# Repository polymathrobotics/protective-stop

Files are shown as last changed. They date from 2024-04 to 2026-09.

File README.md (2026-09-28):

# Protective Stop

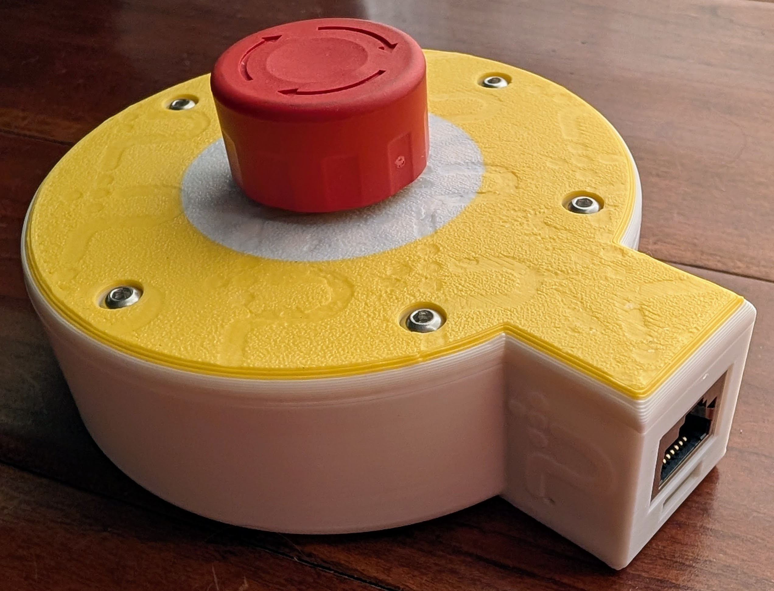
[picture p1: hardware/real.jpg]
Assembled Protective Stop remote with a red stop button, printed enclosure, and Ethernet side pod


<a href="https://certification.oshwa.org/us002846.html">
  OSHWA open source hardware certification mark, UID US002846
</a>

Protective Stop is an open hardware remote for robots and automation. A
PoE- or USB-powered ESP32-S3 watches a physical stop switch and reports its
state to machine-side pstop logic. A STOP message, a wiring fault, or a lost
heartbeat causes the machine process to request STOP.

Each machine sets its own heartbeat window; the remote normally transmits
halfway through it. The network update rate is therefore configured, not fixed.

> This is a protective stop, not an emergency stop. It does not replace a
> required emergency-stop function, including hardwired power removal where
> applicable. OSHWA certification covers open source hardware; it is not
> functional-safety certification.

## How it works

The switch has two normally closed contacts, each wired to a separate GPIO loop
and read by one CPU core. Each core builds the full pstop message independently;
transmission occurs only when both encoded messages match exactly.

Pressing the switch opens both loops and sends STOP. A broken wire or other
fault in one loop makes the cores disagree, while a stalled task or loss of all
network paths prevents transmission. In either case, the machine requests STOP
when its silence timeout expires.

The wire protocol and machine-side state logic come from vendored
[`pstop_c`](pstop_c/), which remains unchanged and follows a separate
certification track. The surrounding firmware handles sensing, networking, and
recovery.

```mermaid
flowchart LR
    subgraph REMOTE["REMOTE - ESP32-S3"]
        SW["DPST NC stop switch"]
        C0["core 0: read loop A and encode"]
        C1["core 1: read loop B and encode"]
        CMP{"byte-for-byte comparator"}
        SW --> C0 --> CMP
        SW --> C1 --> CMP
    end

    NET(["Tailscale path<br/>WireGuard direct or DERP relay"])

    subgraph MACHINE["MACHINE - robot host"]
        APP["machine wrapper"]
        LIB["pstop_c state machine"]
        STOP["STOP request"]
        APP --> LIB --> STOP
    end

    CMP -->|"machine-controlled heartbeat"| NET --> APP
```

Peers addressed directly over LAN or USB-NCM bypass Tailscale and are not
WireGuard-encrypted. Tailscale peers use WireGuard, with DERP relay fallback
when a direct path is unavailable. Their sockets are pinned to the tunnel, so
losing the VPN causes silence instead of a plaintext downgrade. Ethernet is
preferred, with USB-NCM and WiFi available as fallbacks.

## What's included

| Path | Contents |
|---|---|
| [`hardware/`](hardware/) | Editable FreeCAD enclosure, printable files, BOM, wiring, and photographed assembly guide |
| [`firmware/`](firmware/) | ESP-IDF remote firmware and the dual-core sensing/comparison logic |
| [`host/`](host/) | Plain-C machine process and its documented configuration |
| [`ros2/`](ros2/) | ROS 2 machine node and messages |
| [`components/`](components/) | Embedded networking, USB tether, and `pstop_c` integration |
| [`docs/`](docs/) | API, recovery, testing, networking, and safety-case documentation |
| [`tools/`](tools/) and [`test/`](test/) | Protocol, chaos, soak, flashing, and static-analysis tools (see [`tools/README.md`](tools/README.md) for the uv setup) |

Tailscale support uses
[`microlink`](https://github.com/CamM2325/microlink), an embedded client from
Malone Technologies.

### ROS Support
The protective stop machine node is compatible with the following ros2 Distros:
1. Humble (until May 2027)
2. Jazzy (until May 2029)
3. Lyrical (not yet supported, but planned to be supported as soon as possible!)

## Build and run

**[`docs/QUICKSTART.md`](docs/QUICKSTART.md)** walks a fresh laptop through
the whole thing: Tailscale account and key, USB tether, build and flash,
the ROS 2 machine node, pairing, and a bench test through STOP and ARM.
The short version (ESP-IDF 5.5 required):

```sh
cp firmware/sdkconfig.credentials.example firmware/sdkconfig.credentials
$EDITOR firmware/sdkconfig.credentials            # Tailscale auth key + admin password
cd firmware && . /path/to/esp-idf-v5.5/export.sh
idf.py -DPSTOP_PROFILE=dev build && idf.py -p /dev/ttyACM0 flash   # dev profile: bench only

cd ../ros2 && colcon build --packages-up-to protective_stop_machine
ros2 run protective_stop_machine machine_bridge_node
curl -X POST "http://<remote>/api/pstop_peer?ip=<laptop-tailscale-ip>&port=8890"
```

A plain-C machine process (`cd host && make && ./machine_app_runner`) is the
non-ROS alternative. Later firmware updates go over the authenticated admin
API (`POST /admin/api/ota`). Hardware assembly starts with
[`hardware/README.md`](hardware/README.md) and the photographed
[`hardware/ASSEMBLY.md`](hardware/ASSEMBLY.md).

## Timing and arming

The network update rate and stop-on-silence time are machine-controlled:

```text
remote send interval = clamp(heartbeat_ms / 2, 100 ms, 1000 ms)
stop-on-silence time = heartbeat_ms * max_missed_heartbeats
```

The default configuration uses a 400 ms heartbeat window and five missed
windows, giving a send interval of about 200 ms and a stop-on-silence threshold
of about 2 seconds. Integrators should choose values within the validated limits
so the timeout fits their process safety time and network conditions.

The machine starts stopped. To arm it, press and hold the switch for at least
`min_stop_ms` (500 ms by default), then release it. Whether a remote may re-arm
is the **remote's own** declared role: a new remote announces `stop_only` (it can
stop a machine but never arm it) until promoted to `operator` through its
authenticated `/api/role`. The change applies live — an armed machine keeps
running when its operator demotes itself, but refuses to re-arm until a remote
announcing `operator` performs the gesture.

Machines optionally restrict **who may bond at all** with a global allowlist
and/or denylist (empty by default = everyone). A refused remote is told so
(`UNBOND`) and stops retrying until an operator asks it to rebond.

One remote can maintain independent sessions with up to four machines. Each
machine controls its own heartbeat window, timeout and admission policy.

## Testing

The repository includes host-side protocol tests, fault-injection and chaos
ladders, transport soaks, ROS 2 tests, firmware builds, and a MISRA C:2012
pre-check. Start with [`docs/TESTING.md`](docs/TESTING.md); long-run transport
testing is documented in
[`docs/CONNECTIVITY_SOAK.md`](docs/CONNECTIVITY_SOAK.md).

```sh
make -C host test
./tools/misra_check.sh
pre-commit run --all-files
```

## Certification and licensing

The Protective Stop v1.2 hardware design was OSHWA-certified as open source
hardware on August 27, 2026:

- OSHWA UID: **[US002846](https://certification.oshwa.org/us002846.html)**
- Hardware: CERN-OHL-P-2.0
- Software and firmware: Apache-2.0
- Documentation: CC-BY-4.0 unless a file states otherwise

<a href="https://oshwa.github.io/certification-mark-generator/facts">
  Open source license facts: hardware CERN-OHL-P-2.0, software Apache-2.0, documentation CC-BY-4.0
</a>

The source package, licensing map, and mark guidance are summarized in
[`docs/OSHWA_COMPLIANCE.md`](docs/OSHWA_COMPLIANCE.md). Full license texts are
in [`LICENSE`](LICENSE) and [`LICENSES/`](LICENSES/).

The design target for the on-demand stop function is SIL 3 under IEC 61508 and
PL e under ISO 13849. These are engineering targets, not current
functional-safety certifications. The safety case and remaining evidence gaps
are tracked in [`docs/safety/`](docs/safety/) and
[`docs/safety/OPEN_ITEMS.md`](docs/safety/OPEN_ITEMS.md).

## Contributing

See [`CONTRIBUTING.md`](CONTRIBUTING.md) for development requirements. Report
security issues through [`SECURITY.md`](SECURITY.md).

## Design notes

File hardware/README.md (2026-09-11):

# Hardware

<a href="https://certification.oshwa.org/us002846.html">
  OSHWA open source hardware certification mark, UID US002846
</a>

<p>
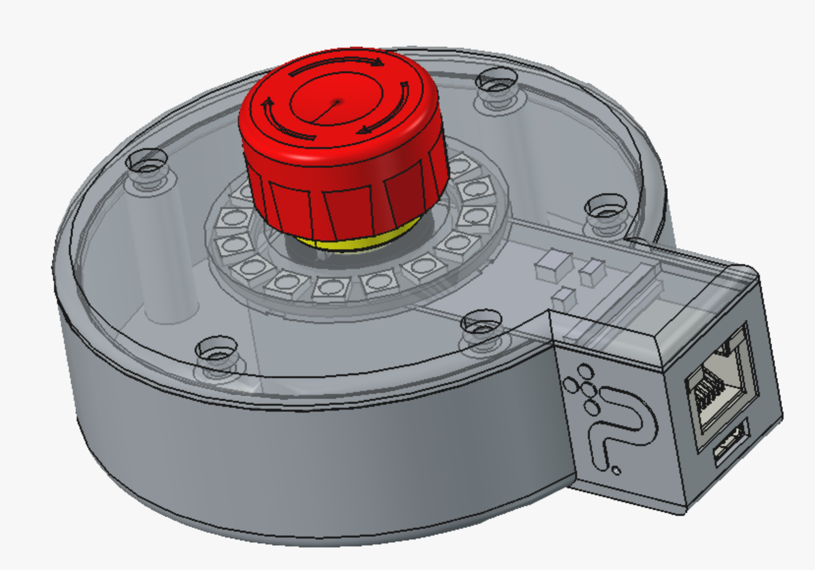
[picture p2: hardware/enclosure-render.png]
CAD render: E-stop button over the 16-LED ring, ports in the side pod
  
  Printed unit: yellow lid, red E-stop, RJ45 in the side pod
</p>

The physical design of the Protective Stop remote lives here: enclosure CAD
(FreeCAD source `casing.FCStd` plus printable exports), the Waveshare
ESP32-S3-ETH carrier board (`ESP32-S3-ETH-Schematic.pdf`, photos, STEP), and
the LED and connector models. CAD render on the left, a printed unit on the
right: the E-stop button sits in the center, the LED ring lights the
diffuser around its base, and the Ethernet and USB-C ports live in the
side pod.

Build steps with photos: [ASSEMBLY.md](ASSEMBLY.md).

## Pinout and wiring

Two external parts connect to the board: the 16-LED WS2812 ring and a DPST
normally-closed E-stop button. Each pole of the button sits in its own
loopback: the firmware drives one GPIO and reads the echo on another, once
per pole, so a broken wire reads the same as a pressed button (STOP). The
pin assignments are fixed in the firmware; the wire colors are only an
assembly convention to keep units consistent and easy to check. Pin names
match the board silkscreen (IO17, IO39, and so on).

| Board pin | Goes to | Wire color |
|---|---|---|
| VBUS | Ring 5V | red |
| GND | Ring GND | black |
| IO17 | Ring DIN (data) | green |
| IO39 | Button terminal 11 (pole A) | white |
| IO40 | Button terminal 12 (pole A) | white |
| IO41 | Button terminal 21 (pole B) | yellow |
| IO42 | Button terminal 22 (pole B) | yellow |

```mermaid
flowchart LR
    subgraph BOARD["ESP32-S3-ETH"]
        direction TB
        P5V["VBUS"]
        GND["GND"]
        G17["IO17"]
        G39["IO39 drive"]
        G40["IO40 sense"]
        G41["IO41 drive"]
        G42["IO42 sense"]
    end

    subgraph RING["WS2812 ring, 16 LEDs"]
        direction TB
        RV["5V"]
        RG["GND"]
        RD["DIN"]
    end

    subgraph SW["DPST E-stop button, NC"]
        direction TB
        P1A["terminal 11, pole A"]
        P1B["terminal 12, pole A"]
        P2A["terminal 21, pole B"]
        P2B["terminal 22, pole B"]
    end

    P5V --- |red| RV
    GND --- |black| RG
    G17 --- |green| RD
    G39 --- |white| P1A
    G40 --- |white| P1B
    G41 --- |yellow| P2A
    G42 --- |yellow| P2B

    linkStyle 0 stroke:#d33,stroke-width:2px
    linkStyle 1 stroke:#333,stroke-width:2px
    linkStyle 2 stroke:#2a2,stroke-width:2px
    linkStyle 3,4 stroke:#aaa,stroke-width:2px
    linkStyle 5,6 stroke:#cc2,stroke-width:2px
```

Notes:

- The button contacts have no polarity; within a pole, either terminal can
  go to the drive pin. Keep each color pair on one pole: 11/12 together
  (white), 21/22 together (yellow).
- The sense pins are pulled down internally, so an open loop reads 0 and
  the firmware treats it as STOP. Pressing the button opens both poles at
  once; a single open loop (one broken wire) makes the two cores disagree,
  which also stops the machine.
- The ring can be installed in any of its 16 rotations. Which pixel counts
  as LED 1 is a per-device setting, calibrated over the network after
  assembly (`POST /api/ring_offset`, see `../docs/API.md`).
- The board's onboard status LED (IO21) needs no wiring.

## Bill of materials

Everything except the printed parts is ordered online. Listings are
pinned where the exact part matters; the wire and lid hardware are
generic, so those stay as search links. All links open in a new window.

| Qty | Part | Notes | Order |
|---|---|---|---|
| 1 | Waveshare ESP32-S3-ETH | The W5500 Ethernet carrier board this design is built around. For PoE-powered units order the ESP32-S3-POE-ETH variant on the same page; it includes the PoE Module (B) that mounts on the board. | <a href="https://www.waveshare.com/esp32-s3-eth.htm" target="_blank" rel="noopener">Waveshare</a> |
| 1 | DIYmall WS2812B ring, 16 pixels | 5V addressable ring. | <a href="https://www.amazon.com/DIYmall-WS2812B-Integrated-Individually-Addressable/dp/B0B2D5QXG5" target="_blank" rel="noopener">Amazon</a> |
| 1 | NKK Switches FF0126BBCAEA01 E-stop button | Twist-release mushroom, two normally-closed contacts (DPST NC). Rated 100,000 operations (mechanical and electrical life, FF01 datasheet); the firmware counts presses against this in `GET /api/health` (`CONFIG_DCS_BUTTON_RATED_OPS`). The STEP model in this folder is this exact part. Substitutes must have 2NC: both loops need an NC pole, so a 1NO+1NC unit will not work; set the Kconfig rating to the substitute's datasheet value. | <a href="https://octopart.com/part/nkk-switches/FF0126BBCAEA01" target="_blank" rel="noopener">Octopart</a> |
| 1 set | Silicone hookup wire | Red, black, green, white, yellow, 24 to 26 AWG, per the wiring table above. | <a href="https://www.amazon.com/s?k=silicone+hookup+wire+kit+26awg" target="_blank" rel="noopener">search</a> |
| ~6 | M3 socket-head screws + brass heat-set inserts | Lid fasteners. Confirm length and count against the current print before buying in bulk. | <a href="https://www.amazon.com/s?k=m3+heat+set+insert+socket+head+kit" target="_blank" rel="noopener">search</a> |
| 4 | M1.6 heat-set threaded inserts, M1.6 x 5 x 2.5 mm | Anchor the ESP32-S3-ETH board to the base; 2.5 mm is the insert height/depth. | <a href="https://www.amazon.com/s?k=m1.6+heat+set+threaded+insert" target="_blank" rel="noopener">search</a> |
| 3 | 1 oz (28 g) adhesive steel weights | Optional. Ballast in the base floor pockets so the unit stays put on a table. Wheel-weight style, adhesive backed. | <a href="https://www.amazon.com/s?k=1oz+adhesive+wheel+weights+steel" target="_blank" rel="noopener">search</a> |
| 1 | Printed enclosure | `print.3mf` in this folder (base and lid; the diffuser is a white section of the lid print), or the pre-sliced `print.gcode.3mf` for an X1C. Not purchased; any common PLA/PETG works. | n/a |

## Component datasheets

The design contains no custom electronics; the active components are all
off the shelf, with freely accessible datasheets:

- <a href="https://files.waveshare.com/wiki/common/Esp32-s3_datasheet_en.pdf" target="_blank" rel="noopener">ESP32-S3 datasheet</a> (Espressif, via the Waveshare wiki)
- <a href="https://files.waveshare.com/wiki/common/W5500_ds_v110e.pdf" target="_blank" rel="noopener">W5500 Ethernet controller datasheet</a> (WIZnet, via the Waveshare wiki)
- <a href="https://files.waveshare.com/wiki/ESP32-S3-ETH/ESP32-S3-ETH-Schematic.pdf" target="_blank" rel="noopener">ESP32-S3-ETH carrier board schematic</a> (Waveshare)
- <a href="https://cdn-shop.adafruit.com/datasheets/WS2812B.pdf" target="_blank" rel="noopener">WS2812B datasheet</a> (WorldSemi, the ring's LEDs)
- <a href="https://www.nkkswitches.eu/pdf/estop_FF01.pdf" target="_blank" rel="noopener">FF01 series E-stop datasheet</a> (NKK Switches)

## Licensing

The design is CERN-OHL-P-2.0 and the documentation is CC-BY-4.0; the full
texts live in [`../LICENSES/`](../LICENSES/). The vendor reference files
stay the property of their manufacturers and are included only as
fit-check references, with their origins listed below.

| File(s) | License / origin |
|---|---|
| `casing.FCStd`, `base*.stl`, `lid*.stl`, `led.stl`, `print.3mf`, `print.gcode.3mf` | CERN-OHL-P-2.0 (original design) |
| `esp32-S3.step` | CERN-OHL-P-2.0 (original board fit model) |
| `LED.step` | CERN-OHL-P-2.0 (ring model commissioned by Polymath Robotics) |
| `README.md`, `ASSEMBLY.md`, `enclosure-render.png`, `real.jpg`, `assembly/*.jpg` | CC-BY-4.0 (original documentation) |
| `oshwa-certification-mark.svg` | Official OSHWA wide certification mark generated for UID `US002846`; use is governed by the [OSHWA certification agreement](https://certification.oshwa.org/license-agreement.html) |
| `oshw-license-facts.svg` | Generated with the [Open Source Licenses Facts generator](https://oshwa.github.io/certification-mark-generator/facts) for this project's certified license combination |
| `ESP32-S3-ETH-Schematic.pdf` | Waveshare, from the <a href="https://www.waveshare.com/wiki/ESP32-S3-ETH" target="_blank" rel="noopener">product wiki</a> (<a href="https://files.waveshare.com/wiki/ESP32-S3-ETH/ESP32-S3-ETH-Schematic.pdf" target="_blank" rel="noopener">direct PDF</a>) |
| `ESP32-S3-ETH-details-15.jpg` | Waveshare product photo, from the <a href="https://www.waveshare.com/esp32-s3-eth.htm" target="_blank" rel="noopener">product page</a> |
| `FF0126BBCAEA01.stp` | NKK Switches E-stop model, from the <a href="https://www.nkkswitches.com/distributor-landing-page/?part_no=FF0126BBCAEA01&vendor=digikey" target="_blank" rel="noopener">NKK part page</a>; series datasheet: <a href="https://www.nkkswitches.eu/pdf/estop_FF01.pdf" target="_blank" rel="noopener">FF01 (NKK)</a> |

## Design files

The editable source for the custom parts is `casing.FCStd`; the STL/3MF files
are its printable exports, and the STEP models are references used for fit.
Build steps live in [ASSEMBLY.md](ASSEMBLY.md).

OSHWA certification details and maintenance notes are in
[`../docs/OSHWA_COMPLIANCE.md`](../docs/OSHWA_COMPLIANCE.md).

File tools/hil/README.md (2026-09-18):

# pstop hardware-in-the-loop test suite

Drives a real pstop remote through its **actual E-stop loops and power
feed** using a 4-channel USB relay board (`tools/usb_relay4.py`), and
asserts the safety behavior at a **dedicated real machine instance**
(`host/machine_app_runner`) over the real transport. Nothing is mocked:
the loop GPIOs, the lockstep comparator, the wire protocol, and the
machine-side arming policy are all the shipping code paths.

## Rig wiring (as built, verified 2026-07-28)

Relay board: STM32 VCP (`0483:5740`), auto-detected. All three channels
use the relays' **NO contacts**, so the fully de-energized rig is the
fail-safe state: loops open ("button pressed"), DUT unpowered.
Bench-normal requires relays 1–3 energized — `rig.idle()` and every
fixture teardown put the rig there.

| Relay | NO contact in series with | De-energized means |
|---|---|---|
| 1 | E-stop loop A: GPIO39 → GPIO40 | loop A open ("press") |
| 2 | E-stop loop B: GPIO41 → GPIO42 | loop B open ("press") |
| 3 | DUT USB power feed (VBUS) | DUT power cut |
| 4 | spare | |

If a future rig wires NC contacts instead, flip `press_energizes` /
`power_cut_energizes` in `hil.toml` — the suite is polarity-agnostic.

The DUT is tethered on USB-NCM; `hil.toml` names the host interface
(`ncm_iface`) and the suite finds the chip's IP from the kernel
neighbor table, then talks to `state.json` + `/api/pstop_peers`. This
bench has TWO pstops attached (soak unit on `esp-pstop0`/10.42.0.x,
test unit on `usb0`/10.43.0.x) — the iface setting is what keeps the
suite pointed at the right one. The suite claims **peer slot 3** on the
chip for its own machine instance (port 8894, id 0x01020390) and clears
it on teardown; slot 0 belongs to whatever real bench machine exists.

## Running

```sh
cd tools/hil
./run.sh                    # everything (incl. power cycles, slow)
./run.sh -m 'not power'     # skip the power-cycle tests
./run.sh test_00_rig.py     # rig self-check after (re)wiring
```

`run.sh` runs pytest in the `tools/` uv environment and strips
`PYTHONPATH`, which a sourced ROS setup otherwise fills with broken
plugins. One-time setup is `cd tools && uv sync`; see
[`../README.md`](../README.md) for installing uv.

If the loops aren't wired yet, everything that needs them **skips**
with a message rather than failing; `test_00_rig.py` tells you whether
the wiring is live.

## What is covered

- `test_00_rig.py` — relay board round-trip, chip API shape, and that
  each relay opens exactly its own loop (catches miswiring).
- `test_10_button.py` — press ⇒ STOP on the wire; release ⇒ armed, never
  sooner than `min_stop_ms`; held button pins the robot at STOP; a
  sub-`min_stop` blip defers arming (pstop_c #59 semantics); re-arm
  after a stop while armed.
- `test_20_discordance.py` — one loop open, the other closed (per
  channel): comparator must go silent (no STOP message on the wire),
  machine stops via MISSED_HEARTBEATS, chip counts lockstep mismatches,
  and healing the fault must NOT re-arm without a fresh gesture.
- `test_30_power_cycle.py` (`-m power`) — power loss stops the machine;
  a cold boot re-bonds (NVS peer slot) but never self-arms; boot with
  the button held flows STOP and then completes a gesture on release.

Timing knobs live in `hil.toml [timing]` and are fed into the generated
machine config, so the asserted budgets and the machine under test
always agree.

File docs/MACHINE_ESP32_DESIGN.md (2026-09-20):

# pstop machine on ESP32-S3 — design sketch (v0, for review)

**Status:** v0.1 — review answers folded in, 2026-07-31. Deliberately
short — structure over detail. Nothing implemented yet.

## Goal

Deploy the pstop_c **machine** role on the same ESP32-S3 platform as the
remote: a self-contained box that bonds remotes, runs the safety decision
dual-core, and actuates the robot's stop circuit through relays. The pure
software machine (`host/machine_app_runner`) remains fully supported — same
library, same wire protocol, same config semantics; this is a second
machine form factor, not a replacement.

## Reused from the remote (unchanged infrastructure)

- **Hardware**: Waveshare ESP32-S3-ETH (PoE), same enclosure family.
- **Connectivity**: microlink (Tailscale/WireGuard/DERP), eth → wifi
  supervised uplinks. Own tailnet identity derived from eFuse MAC, prefix
  distinguishes the role: **`machn-01<mac24>`** (remotes keep `pstop-`).
- **Platform services**: NVS-persisted settings + admin UI, boot-count
  safety ladder, direct OTA (`/admin/api/ota`), `/state.json` telemetry
  (with `fw_ver`/`fw_sha`), reset-history, panic log.
- **pstop_c untouched**, as always: the machine role is what the library
  already provides; everything below is the shell around it.

## Dual-core RX lockstep (mirror of the remote's TX lockstep)

The remote's pattern: two cores independently *encode*, byte-compare,
transmit only on agreement. The machine inverts it:

- Each core runs its **own pstop_c machine instance** (own state, own
  remotes table) and independently decodes + validates every received
  datagram and computes (verdict, reply bytes).
- A comparator (same 100 ms tick discipline as the remote) compares the
  two cores' verdicts AND reply bytes. **Agree** → actuate relays to the
  agreed state, send the reply. **Disagree** → treat as internal fault:
  both relay outputs commanded open (STOP), reply withheld (the remote
  sees silence and stops, exactly like a remote-side mismatch), mismatch
  counter incremented (purple-equivalent indication, persistent-only per
  the current ring policy).
- Liveness (`check_heartbeats`) runs per core on the shared monotonic
  clock; a timeout verdict must also agree before it opens the relays —
  with the caveat that *either* core alone opening its relay already
  stops the robot (see below), so disagreement is never less safe.

## Relay output + feedback (replaces the remote's button inputs)

> **[DESCOPED 2026-08 — feedback OFF by default, REVERSIBLE.]** The relay
> **feedback / read-back** described in this section is compiled out by default
> via the Kconfig option `CONFIG_MACHN_RELAY_FEEDBACK` (default `n`), pending a
> new machine hardware revision whose wiring makes the divider voltages
> unreadable. The relay **drive** (below) and the series de-energize-to-safe
> stop are unchanged. Set the Kconfig to `y` to restore feedback. Full detail +
> safety-case impact: docs/RELAY_FEEDBACK_DESCOPE.md.

Two opto-isolated relays, contacts **wired in series** in the robot's
stop circuit — either core alone can break the circuit:

- Core 0 drives relay A, core 1 drives relay B (one GPIO each through
  opto-isolated drivers, reusing the remote's E-stop loop pins).
  **Energized = circuit closed = robot may run; de-energized = STOP.**
  Power loss, brownout, reset, or a hung core all fail to STOP.
- **Feedback = output-voltage sensing**: a resistor divider on each
  relay's switched output, read as a digital input by BOTH cores. After
  any commanded transition the observed voltage must match within
  `RELAY_FEEDBACK_MS` (TBD from relay switching time) and is also
  checked continuously at every comparator tick.
- **Fault semantics — nothing latches.** Transient conditions (a
  momentary core disagreement, a momentary loss of remote signal)
  already self-recover exactly as on the remote: the comparator
  withholds/opens for the duration and resumes when agreement returns.
  A *feedback contradiction* (e.g. output still live after commanding
  open — welded contact / shorted driver) raises a persistent
  **relay-fault indication** for as long as the condition is observed:
  telemetry flag, fault counter, and the machine keeps both outputs
  commanded open. Safety does not depend on latching — the series
  partner relay breaks the circuit — but the indication persists so a
  single-channel box gets serviced; it clears by itself when feedback
  returns to sanity.

## Reporting to the ROS2 computer

The ESP32 machine replaces the runner's *decision* role but the robot
computer still needs live state. Two channels, both read-only:

**`/state.json`** gains machine-role fields: robot verdict, restart
state, arming owner, per-remote table (bonded/heartbeat age), relay
commanded/observed states, mismatch + fault counters. A thin **ROS2
node** (successor of the archived `protective_stop_node`) polls it at
5 Hz and republishes as topics — `robot_status`, `relay_state`,
`fault`. No new firmware surface; no UDP stream.

The stop circuit itself is the relay chain — the ROS2 reporting path
carries **no safety responsibility**.

## Fleet / OTA policy (config-gated, per decision)

- The machine runs the same fleet check-in code but registers with
  **`device_type: "machine"`** in the check-in payload (new field,
  remotes implicitly `"remote"`).
- **Server-side enforcement (required, management-console work):** the console
  must refuse to assign remote firmware to `device_type != remote` —
  machines get their own image lineage or nothing. This needs a handoff
  item to the console session before any machine unit ships.
- Belt-and-braces on the device: machine builds set `auto_update`
  default **off**, and the OTA-apply path verifies the incoming image's
  project name (`machn_machine` vs `pstop_remote` in the app
  descriptor) and rejects a mismatch regardless of what the server says.
- Direct OTA (`/admin/api/ota`) remains the recovery path, same as today.

## Config

The `machine.toml` knobs move to NVS + admin UI (same pattern as the
remote's settings): admission allow/denylist (`/api/admission`, optional —
who may bond; re-arm authority is each remote's own announced role),
`max_missed_heartbeats`, `min_stop_ms`
(→ library `delay_between_stop_ms`), `machine_device_id`, listen port.
Persisted, live-applied where safe.

## Out of scope for v1

Certification argumentation; multi-machine coordination (remote side
already handles up to 4 machines — an ESP32 machine is just one of
them); LED ring on the machine box (onboard RGB only for v1, TBD);
console MACHINES-tab integration beyond the existing announce.

## Resolved in review (2026-07-31)

1. Relay: opto-isolated module; feedback via resistor divider on the
   switched output read as digital IO. Exact part TBD during hardware
   pass; `RELAY_FEEDBACK_MS` set from its switching time.
2. ~~No fault latching: indication only~~ **Revised 2026-07-31 after
   bench test** (disconnected feedback looked fully green): a feedback
   contradiction persisting ≥ ~1 s now **stops the robot** — both
   relays open, replies STOP, re-arming refused while the fault is
   present. Still no latch: clears with the fault; re-arm requires a
   fresh remote gesture. Named telemetry: `relay_fault_a/b` (consecutive
   contradiction ticks) + `relay_stop` in `/state.json`; commanded/
   observed in `e_hi*/e_lo*`.
3. ROS2 reporting: poll `/state.json` at 5 Hz; no UDP stream.
4. Arming: remote gestures only — the machine box has no arm input.
5. Naming: remotes keep `pstop`; machines use `machn`.

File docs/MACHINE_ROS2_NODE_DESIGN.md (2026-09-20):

# Machine ROS 2 Lifecycle Node — Design v0.2

Status: **READY TO IMPLEMENT** (2026-08-01). Decisions locked from Q&A:
role = **bridge + control**; software backend = **node hosts pstop_c itself**;
distro = **Jazzy**; interfaces = **machine-state + relay/fault + remotes/RTT**;
arming stays **remote-only** (§2, §8). Implementation decisions resolved in §10:
extend `protective_stop_msg`, in-repo `ros2/` workspace, **full control-proxy**
hardware backend, keep `machine_app_runner`.

---

## 1. Purpose & scope

A managed (lifecycle) ROS 2 node that presents **one uniform ROS 2 surface**
over a pstop *machine*, regardless of which of the two machine implementations
is behind it:

- **software** — the node **is** the machine: it links the certified `pstop_c`
  library and runs a machine instance in-process, binding UDP `:8890` so remotes
  bond directly to it (today's `host/machine_app_runner`, absorbed into the node).
- **hardware** — the ESP32 `machn` unit is the machine; the node is an HTTP
  client that polls its `/state.json` at 5 Hz and drives its admin API.

The backend is chosen at **configure time** from the parameter file; everything
above the backend seam (topics, services, diagnostics, lifecycle) is identical.

### What this node is NOT
It is a **bridge + control** surface, **not the safety authority**. The relays
(hardware) and the `pstop_c` fail-safe logic (software) enforce STOP
independently of ROS 2. Loss of this node, its host, or the DDS graph **must not
produce unsafe motion**: with the software backend the machine dies with the
node, so remotes stop receiving replies and **fail-safe STOP** on their own
heartbeat timeout; with the hardware backend the ESP32 keeps enforcing while
ROS 2 merely goes blind. This property is a design invariant, re-checked in §8.

What the node **does** owe, because the pure ROS 2 (software) machine has no
final element of its own, is an unambiguous published statement of the desired
state — STOP or OK — carried on a stamped heartbeat a consumer can watchdog.
That is `~/pstop_hb`; see §5 "Stop signal". Publishing it does not make the node
the safety authority (SR-M-04), it makes the machine's verdict actionable by
whatever the integrator allocates the actuation duty to.

---

## 2. Control surface (what "bridge + control" means here)

Allowed control, none of which can *create* an unsafe RUN state:

- **Reconfigure timing** — heartbeat period, `max_missed`, `min_stop_ms` — via
  dynamic parameters. Tightening these can only make the machine *more*
  conservative at runtime; validation (§4) refuses values looser than the
  compile-time safe envelope. Rates are read at configure/activate and need a
  restart.
- **Target/peer management** — which remotes the software machine expects, or
  (hardware) proxied peer-slot config through the ESP32 admin API.
- **Lifecycle** — activate/deactivate the bridge (deactivate drives the machine
  to its safe state, §3).

Explicitly **out of scope**: arming. Arming a machine to RUN requires a physical
STOP→OK gesture on a bonded remote (pstop_c `#59` ownership semantics). Exposing
"arm" over ROS 2 would move the human-in-the-loop guarantee into software; we
keep it on the remotes. The node can *observe* and *report* arm state, never
assert it.

---

## 3. Lifecycle model (`rclcpp_lifecycle::LifecycleNode`)

| Transition | Software backend | Hardware backend | Safety note |
|---|---|---|---|
| `on_configure` | load+validate params, construct backend, create pub/sub/services **inactive**, build `pstop_c` machine (no socket yet) | same, construct HTTP client, resolve device URL | no I/O, no motion authority yet |
| `on_activate`  | bind UDP `:8890`, start the **machine loop thread**, activate publishers, start state-publish timer | start 5 Hz poll timer, activate publishers | machine begins servicing remotes / polling |
| `on_deactivate`| **stop the machine loop** → remotes stop getting replies → they fail-safe STOP; deactivate publishers | stop polling; ESP32 keeps enforcing | deactivation is a *safe* action by construction |
| `on_cleanup` | destroy machine, socket, pubs | destroy HTTP client, pubs | back to `unconfigured` |
| `on_shutdown`  | ensure loop stopped, release | ensure polling stopped | idempotent safe teardown |
| `on_error` | stop loop, publish `UNSTABLE`, → `errorprocessing` | mark backend unreachable, publish `UNSTABLE` | fault ⇒ conservative state |

Bringup is **self-managed**: the read-only `autostart` parameter (default
**true**) makes the node configure and activate itself in its constructor, so a
bare `ros2 run protective_stop_machine machine_bridge_node` comes up active.
Set `autostart:=false` to hold it in `unconfigured` for manual or orchestrated lifecycle control

---

## 4. Parameters — file-driven, validated, partly dynamic

Loaded on start from a **ROS 2 params YAML** (`--ros-args --params-file`), the
idiomatic mechanism. We use **`generate_parameter_library`** (PickNik, standard
on Jazzy) to declare params in one YAML, auto-generate a typed struct with
**validation (ranges/enums)**, `read_only` flags, and a dynamic-update hook —
eliminating hand-rolled `declare_parameter` + validation boilerplate.

**Static (`read_only`, require reconfigure):**
`autostart`, `backend` (`software|hardware`), `machine_id`, `frame_id`, software
`bind_addr`/`port`, software `allowlist`/`denylist` (optional admission —
who may bond; re-arm authority is the remote's own announced role), hardware
`device_url`/`admin_user`, the `rates.*` group (`state_poll_hz`,
`publish_rate_hz`, `diagnostics_rate_hz` — read at configure/activate), and the
optional fleet groups `announce.*` and `fleet.*`.

**Dynamic (runtime-settable, re-validated on set):** the `timing.*` group only —
`heartbeat_ms` (∈ [50, 1000]), `max_missed` (∈ [1, 5]), `min_stop_ms` (≥ 100).

Validation rule: a dynamic set that would **loosen** the safety envelope past the
compile-time floor is **rejected** (the set-callback returns `successful=false`
with a reason), so ROS 2 can only make the machine safer, never less safe.

**Fleet check-in (`announce.*`, software backend only, opt-in):**
`announce.url`, `announce.key_file`, `announce.name`, `announce.interval_s` —
all `read_only`, and **default DISABLED** (empty `url`). When a URL is set, the
node runs a background thread (started on `on_activate`, stopped on
`deactivate`/`error`/`shutdown`) that POSTs a bearer-authenticated JSON check-in
every `interval_s`, so the software machine appears in the fleet console's
machines/overview exactly like the host runner (`host/machine_app_runner.c`
`[announce]`) and the ESP32 machn. The body's core `{"name","port"}` matches the
host runner byte-for-byte (the console keys on `name` and attributes the source
IP itself); additive fields carry the machine's status for the overview
(`device_type:"machine"`, `machine_id`, `running`, `active_remotes`, and a
per-remote `remotes[]` summary). Deliberately **off the safety path**: its own
thread, libcurl only, log-only on failure — a dead console never affects pstop.
Prefer the **environment** for the deployment secrets: `PSTOP_ANNOUNCE_URL` and
`PSTOP_ANNOUNCE_KEY_FILE` override the params so URL/key stay out of committed
config (same convention as the host runner). See `announce.hpp` /
`src/announce.cpp`; payload builder is header-inline + unit-tested
(`test/test_announce.cpp`, network-free).

---

## 5. Interfaces

### Topics (QoS chosen per data semantics)
| Topic | Type | QoS | Notes |
|---|---|---|---|
| `~/machine_state` | `protective_stop_msg/ProtectiveStopStatus` (ACTIVE/DEACTIVATED/UNSTABLE) + reason string | **reliable, transient_local (latched)**, depth 1 | publish on-change **and** at `publish_rate_hz` heartbeat; late subscribers get current state |
| `~/relay_status` | new `MachineRelayStatus` (relay_stop, relay_fault_a/b, mismatch, run) | reliable, depth 5 | hardware: from `/state.json`; software: relays N/A → fields flagged `not_applicable` |
| `~/remotes` | new `BondedRemoteArray` (id, bond_state, reply_age_ms, loop_rtt_ms, disco_rtt_ms, rebonds) | reliable, depth 5 | uniform across backends |
| `~/pstop_hb` | `protective_stop_msg/ProtectiveStopHeartbeat` (`stamp`, `stop`) | **reliable, volatile**, depth 1 | the **desired-state signal + liveness** — see "Stop signal" below. Republished every `publish_rate_hz` tick regardless of change; deliberately **not** transient_local |
| `/diagnostics` | `diagnostic_msgs/DiagnosticArray` via `diagnostic_updater` | default | backend reachability, bond count, faults, mismatch, loop jitter |

### Stop signal (what a downstream consumer acts on)

On the hardware backend the final element is the `machn` relay pair and this
node is telemetry. On the **pure ROS 2 (software) machine there is no final
element in scope** (SR-M-04, HARA A-07/H-12) — the actuation duty is allocated
to a downstream consumer, so the node's *published* signal is the only thing
that consumer can act on. It must therefore be unambiguous and self-dating:

- **Desired state, not a status narrative.** `~/pstop_hb.stop` is a single
  boolean — `true` = drive to STOP, `false` = cleared to run. It is taken from
  the machine's own cleared-to-run verdict, so `DEACTIVATED` (stopped, or
  awaiting the arming gesture) and `UNSTABLE` (backend unreachable) **both**
  resolve to `stop = true`. FMEA M03-1's "downstream consumer must treat
  STOP/UNSTABLE as de-energize" is applied at the source rather than re-derived,
  possibly differently, by every consumer.
- **`~/machine_state` is not the actuation input.** It stays the operator /
  telemetry view. It carries no stamp, and its tri-state deliberately reports
  *why* the machine is not running — a distinction a gate must not act on
  differently.
- **Heartbeat.** The same message carries `stamp` and is republished every tick
  whether or not anything changed, so a consumer fails safe on silence or
  staleness without the node having to assert anything. **Absence is a stop.**
- **Explicit final stop.** `on_deactivate`, `on_shutdown` and `on_error` each
  publish one last `stop = true` before the publishers go down, so an orderly
  teardown produces a positive stop instead of relying on the consumer's timeout.
- **Volatile by construction.** A late-joining consumer must never be handed a
  latched historical `stop = false` and open its gate on it; it waits for a live
  sample.

This makes the signal *usable*; it does not make it *rated*. SR-M-04 still
stands — a software-machine deployment is non-safety-rated and the final-element
integrity remains the integrator's (HARA A-07).

Interfaces ship as **`protective_stop_msg`** (`ros2/protective_stop_msg/`),
moved out of `archive/` so there is a single interface package. It keeps the six
original remote-side messages and the `ProtectiveStop` service — including
`ProtectiveStopHeartbeat`, reused unchanged for `~/pstop_hb` — and adds **three**
machine-side ones: `MachineRelayStatus`, `BondedRemote` and `BondedRemoteArray`,
so remote and machine share one interface package.

### Diagnostics
`diagnostic_updater` publishes OK/WARN/ERROR: backend unreachable ⇒ ERROR (but
note the machine still enforces independently); relay fault or mismatch ⇒ WARN/
ERROR; loop-period jitter over budget (software) ⇒ WARN.

---

## 6. Threading & determinism

Clean separation of **pure logic** from **ROS glue** (matches the repo's module
discipline):

- **Software backend** runs the `pstop_c` machine loop in a **dedicated
  `std::thread` at a deterministic period**, *off* the ROS 2 executor, so DDS/
  callback jitter never perturbs the safety heartbeat. It writes an immutable
  **state snapshot** (double-buffered / mutex-guarded POD) that ROS timers read.
- **Hardware backend** polls on a ROS timer in a **`Reentrant` callback group**
  so a slow HTTP round-trip can't stall state publication. *(superseded)*
- Publishers/services live in a `MutuallyExclusive` group. A `MultiThreaded
  Executor` runs the node. *(superseded)*

  > **[Reconciled 2026-08-05]** Both bullets above describe a threading model the
  > code does not have, and the node is **deliberately not** built that way.
  > Ground truth:
  >
  > - The hardware backend polls on its **own `std::thread`**
  >   (`hardware_backend.cpp` `poll_loop`), not a ROS timer in a callback group —
  >   so the "slow HTTP can't stall publication" property holds by the same
  >   off-executor mechanism the software backend uses, not by reentrancy.
  > - The node declares **no callback groups**, so every ROS callback
  >   (`publish_tick`, the lifecycle transitions, `diagnostic_updater`, the
  >   parameter set handler) lives in the node's default **`MutuallyExclusive`**
  >   group, and the code-generated executable spins a
  >   **`SingleThreadedExecutor`** (rclcpp_components default).
  >
  > **Single-threaded execution is a design requirement, not an accident.**
  > `publish_tick` and the lifecycle transitions both touch the publisher handles
  > and `last_snapshot_`, and `pub_timer_->cancel()` does not wait for an
  > in-flight callback. Serialising every ROS callback on one thread is what
  > makes that safe without locks: `on_cleanup`/`on_error` can only `reset()` a
  > publisher on the same thread that would otherwise be inside `publish_tick`.
  > Introducing a `MultiThreadedExecutor`, or moving any callback into a
  > `Reentrant` group, re-opens a use-after-free on all four publishers and a
  > data race on `last_snapshot_`, and **must** be accompanied by explicit
  > lifetime/state guards. Off-executor work belongs on a backend thread behind
  > `IMachineBackend`'s mutex-guarded snapshot, which is where it already is.
- Backends implement one interface:

  ```cpp
  class IMachineBackend {            // pure, no rclcpp
  virtual void start() = 0;        // bind/socket or begin polling
    virtual void stop()  = 0;        // → safe state
    virtual MachineSnapshot snapshot() const = 0;   // thread-safe read
    virtual bool configure(const MachineTiming&) = 0; // runtime reconfig
  };
  ```

  `SoftwareMachineBackend` and `HardwareMachineBackend` are the two impls; the
node depends only on `IMachineBackend`.

---

## 8. Safety analysis (invariant re-check)

| Failure | Software backend | Hardware backend |
|---|---|---|
| Node process dies | machine dies → remotes time out → **STOP**; `~/pstop_hb` also goes silent → a consumer watchdogging it stops | ESP32 unaffected → still enforces; ROS 2 blind (diagnostics ERROR on next consumer) |
| `on_deactivate` | machine loop stops → remotes **STOP**; one explicit `stop = true` heartbeat is published before the publishers go down | polling stops; ESP32 enforces |
| DDS/host partition | irrelevant to enforcement (UDP bond is separate from DDS); a partitioned consumer sees `~/pstop_hb` stop arriving → **STOP** | irrelevant; ESP32 enforces |
| Backend unreachable | n/a (in-process) | publish `UNSTABLE` + diag ERROR; **no** motion authority asserted |
| Param set loosening safety | rejected by validator | rejected by validator |

Invariant holds: **no ROS 2 failure path creates or sustains RUN.** The node can
only observe, report, and tighten.

---

## 9. Testing

- **gtest** on `SoftwareMachineBackend`/`HardwareMachineBackend` behind
  `IMachineBackend` with a mock transport / mock HTTP — no ROS spin needed
  (pure-logic tests).
- **launch_testing** for lifecycle transitions and the safety invariants
  (deactivate ⇒ remotes STOP; bad param ⇒ rejected).
- Reuse the existing wire-protocol suites (`pstop_multi_remote_test.py`,
  `stop_reset_battery.py`) against the **software backend hosted in the node** to
  prove parity with `machine_app_runner`.

---

## 10. Decisions (resolved 2026-08-01)

1. **Message ownership** — **extend `protective_stop_msg`** (moved out of
   `archive/` into `ros2/`); add `MachineRelayStatus` + `BondedRemote` +
   `BondedRemoteArray` there so remote and machine share one interface package.
2. **Package location** — **in-repo `ros2/` colcon workspace** at repo root. The
   archived packages already live here and CI can build it; accepts re-adding
   ROS 2 build deps that #53 slimmed out.
3. **Hardware backend scope** — **full control proxy**: the hardware backend not
   only publishes state but proxies config/peer-slot changes to the ESP32 via
   its admin API, so timing reconfiguration and target management work uniformly
   across both backends (§5). Still bounded by the safety validator (§4): proxied
   config can only tighten, never arm.
4. **`machine_app_runner`** — **kept** as a headless / CI tool. The node's
   software backend shares its pstop_c glue, but the runner stays because the
   wire-protocol suites (`pstop_multi_remote_test.py`, `stop_reset_battery.py`)
   depend on it.

## 11. Rollout note (perf / fleet, 2026-08-01)
Firmware perf track is `-O2`-only for the near term (validated); `-O3`-on-crypto
is deferred to its own change. Verified builds are uploaded to the fleet build
server so the flashing station's "latest" tracks real work; "starring" not
adopted (station uses newest).

---

## 12. Running the node and overriding parameters

Defaults (and the SR-M-01 validation ranges) live in the
`generate_parameter_library` source `src/protective_stop_machine_params.yaml`
and are compiled in, so a bare run comes up active:

```sh
ros2 run protective_stop_machine machine_bridge_node
```

To override, pass a params file:

```sh
ros2 run protective_stop_machine machine_bridge_node \
  --ros-args --params-file my_overrides.yaml
```

```yaml
/machine_bridge:
  ros__parameters:
    autostart: true             # read_only; false holds the node in unconfigured
    backend: software           # software | hardware   (read_only)
    machine_id: 0x01020304      # read_only
    frame_id: pstop_machine

    software:                   # used when backend == software
      bind_addr: 0.0.0.0
      port: 8890                # read_only
      # Admission (OPTIONAL): who may BOND. Both empty (default) = everyone.
      # A non-empty allowlist admits ONLY the listed 32-bit pstop ids; the
      # denylist always refuses and wins. A refused BOND is answered UNBOND.
      # Re-arm authority is NOT here: each remote announces its own
      # stop_only/operator role (remote /api/role) and the node honours it
      # live — a demoted operator keeps an armed machine running but cannot
      # re-arm it after the next STOP.
      # allowlist: [30234300]   # read_only
      # denylist: []            # read_only

    hardware:                   # used when backend == hardware
      device_url: http://100.84.155.111
      admin_user: admin         # password via env, never in the file

    timing:                     # the only dynamic group; validated on every set
      heartbeat_ms: 400         # [50, 1000]
      max_missed: 5             # [1, 5] — default 5, matches machn (timeout ~2.0s)
      min_stop_ms: 500          # >= 100

    rates:                      # read_only; read at configure/activate
      state_poll_hz: 5.0        # hardware poll
      publish_rate_hz: 10.0     # also the ~/pstop_hb rate
      diagnostics_rate_hz: 1.0

    # Optional fleet console check-in (software backend only, both default
    # DISABLED on an empty url). Prefer the ENVIRONMENT for the secrets:
    # PSTOP_ANNOUNCE_URL / PSTOP_ANNOUNCE_KEY_FILE and
    # PSTOP_CHECKIN_URL / PSTOP_CHECKIN_API_KEY_FILE override these.
    announce:                   # lightweight overview check-in
      url: ''                   # read_only; empty = disabled
      key_file: ''              # read_only; chmod-600 bearer token
      name: ''                  # read_only; empty = this host's hostname
      interval_s: 60            # read_only

    fleet:                      # device check-in (device_type="machine")
      checkin_url: ''           # read_only; base url, /api/v1/checkin appended
      api_key_file: ''          # read_only
      check_interval_s: 300     # read_only; [60, 300]
```

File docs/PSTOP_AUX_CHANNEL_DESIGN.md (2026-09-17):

<!--
SPDX-FileCopyrightText: 2026 Polymath Robotics
SPDX-License-Identifier: Apache-2.0
-->

# Remote role announcement

`pstop_c` v2 added two CRC-protected `uint32` padding fields to its 48-byte
message. Wrapper code uses `padding1` to let a remote announce whether it is an
operator or stop-only. The certified `pstop_c` library remains unchanged.

> **Forward-compatibility:** `padding1` is the remote-to-machine field and keeps
> 16 bits reserved for future remote announcements. `padding2` is reserved in
> full for a future machine-to-remote schema, such as machine state or stop
> reason feedback. The planned convention for `padding2` is an 8-bit schema
> version followed by 24 bits of direction-specific data. It remains zero and
> uninterpreted in this version.

## Wire layout

`padding1` is encoded by `common/pstop_aux_channel.h`:

```text
bits  0..7   schema version (1)
bits  8..15  role: 0 unspecified, 1 stop-only, 2 operator
bits 16..31  reserved for future remote-to-machine additions (zero today)
```

`padding2` is owned by machine replies but has no active schema yet:

```text
bits  0..7   reserved for a future machine-to-remote schema version (zero today)
bits  8..31  reserved for future machine-to-remote data (zero today)
```

Senders must zero every reserved bit. Receivers must ignore `padding2` until a
nonzero machine-to-remote schema version is defined and implemented.

Unknown versions decode as unspecified. Unknown role values under version 1
decode as stop-only. Only an explicit operator value can contribute operator
authority.

## Policy

Two independent decisions, deliberately kept apart.

### Authority: the remote alone decides

A remote may re-arm a machine when — and only when — the frame carrying its OK
announces `OPERATOR`. Machines do not consult any list for this: the machine
callback seeds `is_stop_only` from the BOND frame's announced role and every
later frame refreshes it.

```text
stop_only = announced_role != OPERATOR
```

`UNSPECIFIED` (pre-role firmware, unknown schema version) and unknown role
values decode as stop-only, so the failure mode of a provisioning gap is always
"cannot re-arm", never "unexpected operator".

The role is **live**. `POST /api/role` on the remote applies to its next frame
(no reboot) and the machine re-reads it per frame, giving these semantics:

| Situation | Machine behaviour |
|---|---|
| Armed; the remote that armed it demotes itself to `stop_only` | keeps **running**; that remote's arming-cycle ownership is released |
| ...then that remote presses STOP | machine **stops** and refuses to re-arm on its release (`NEED_STOP`) |
| ...and presses again | still refused — a stop-only remote never opens an arming cycle |
| some remote announcing `OPERATOR` performs STOP → OK | arms |
| the demoted remote promotes itself back | its next STOP → OK arms |

Why the machine needs two hooks around `machine_process_message()`
(`common/pstop_aux_channel.h`, `pstop_aux_apply_role_pre/post`): `pstop_c`
consults `is_stop_only` only when a STOP *acquires* ownership of the arming
cycle (`remote_stop_id == 0`). Once a remote has armed the machine it stays the
owner and its later STOP re-opens the cycle unconditionally; and from
`restart_state = OK` a stop-only STOP leaves `restart_state` untouched, so the
release would re-arm. The pre-hook releases ownership held by a stop-only remote
(voiding a half-open cycle to `NEED_STOP`); the post-hook forces `NEED_STOP`
after any accepted STOP from a stop-only remote. `pstop_c` itself is unmodified;
only public structs are touched, identically in all three machines.

Because the role is self-asserted (CRC only, no authentication), it must never
*grant* anything the machine would otherwise refuse — which is why admission is
a separate, machine-owned decision.

### Admission: optional, machine-owned, global

Whether a remote may **bond at all** is decided by two optional lists on the
machine, both empty by default (**open**: every remote is admitted). This is the
normal way to run; a fleet that wants a "paranoid" posture populates them.

| List | Effect |
|---|---|
| `allowlist` non-empty | **only** listed ids may bond |
| `denylist` | listed ids may **never** bond; wins over the allowlist |

Admission is evaluated once, at BOND (`remote_details_t.allowed`). A refused
BOND is answered with the `UNBOND` reply `pstop_c` already prepares
(`protocol.c`), addressed to the remote, instead of silence. On the remote a
BOND answered with `UNBOND` parks that session in `REJECTED` (`state: 3` in
`state.json`, red chip in the web UI, `last_msg = UNBOND`) with **no automatic
retries** — it waits for `POST /api/pstop_peers?slot=N&rebond=1` (the Rebond
button), a slot reconfigure, or a reboot. This keeps a banned or misconfigured
remote from knocking forever while making the refusal visible.

Where the lists live:

| Machine | Configuration |
|---|---|
| ESP32 `machn` | NVS via `GET/POST /api/admission` (`?allow=`, `?unallow=`, `?deny=`, `?undeny=`); web UI; `state.json` `allowlist`/`denylist` |
| ROS 2 node | `software.allowlist`, `software.denylist` (int arrays) |
| host runner | `[policy] allowlist = [...]`, `denylist = [...]` in `machine.toml` |

Admission never affects authority: an admitted remote still re-arms only if it
announces `OPERATOR`.

## Provisioning and lifecycle

The role is stored in remote NVS and defaults to stop-only. `POST /api/role`
persists a new value and applies it live; the next outbound frame announces it
and every bonded machine honours it on receipt (see the table above). No
re-bond is needed. The active role is exposed as `role` in the remote's
`state.json` and on its web UI.

Machine-side, each bonded remote's effective `stop_only` is observable (ROS 2
`/machine_bridge/remotes`, machn `state.json` `bonded_remotes`, host runner
`ROLE` log lines) and now tracks the announced role live.

## Rollout

The v2 message size is a hard wire cutover from 40 to 48 bytes. Update remotes
and machine implementations together. Existing remotes without the NVS role key
start as stop-only and must be explicitly promoted where re-arm authority is
required. A machine that previously carried an operator list does **not**
inherit it as an admission allowlist: the meanings differ ("may re-arm" vs
"may bond") and reinterpreting it would lock out every other remote after an
OTA. machn migrates the legacy `operators` ids once into its **pin list** (they
keep their WireGuard peer pinning, which is what made cross-site remotes bond
reliably) and comes up in open admission; add ids to the allowlist deliberately
if a paranoid posture is wanted.

One observed edge worth knowing: if a remote is promoted to `operator` *while
its button is held*, its continuing STOP frames are now operator STOPs and open
an arming cycle, so the release arms (min-STOP still counted from the first
operator STOP). Role is evaluated per frame; promotion is an authenticated
admin action, so this is by design.

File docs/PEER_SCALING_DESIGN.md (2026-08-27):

# Peer capacity scaling — 16 → 128 peers (2026-07-21)

Raises the Tailscale peer capacity to 128 on the ESP32-S3 (8 MB PSRAM)
**without** degrading the stability or latency of the one safety-critical
peer (`priority_peer_ip`, the protective-stop link). All changes are
in `components/microlink` (+ nested `wireguard_lwip`) and `firmware/`;
`pstop_c` is untouched.

## Principle: memory scales, CPU bursts don't

A full code trace found that **memory is not the limiter** — at 128 peers
the WG device struct (~114 KB) and peer table (~34 KB) are PSRAM-resident,
and per-packet peer lookups are µs-scale linear scans dwarfed by the
~30 ms NaCl box-open that follows. Every historical wedge in this firmware
was **CPU load starving the single wg_mgr loop** that also drains the
pstop heartbeat queue. So the load paths were armored first; the capacity
constants were raised last.

The NaCl layer recomputes the X25519 DH on **every** box open/seal (no
shared-key cache), so each inbound disco packet from an unknown/rotated
key costs ~30 ms — and the 2026-07-20 rotation-rescue deliberately admits
unknown keys to that cost. Unbounded, a 100-peer tailnet's magicsock
probing (or a malicious flood) is a multi-second stall. The fix is a
budget, not a revert.

## Load-path armor (landed before the capacity raise)

All budgets exempt the priority peer; all live in `ml_wg_mgr.c` /
`microlink_internal.h` / `ml_peer_nvs.c`.

| Change | Constant | Effect |
|---|---|---|
| WG-rx queue drained **first** in the loop + depth 8→32 | `ML_WG_RX_QUEUE_DEPTH` | pstop heartbeats no longer wait behind (or overflow from) a disco box-open burst — the single highest-value latency fix |
| Inbound disco box-open budget per loop pass | `ML_DISCO_OPENS_PER_PASS=4` | bounds the unknown-key admission; priority peer's disco key exempt (cleartext key at header offset 6, one memcmp, no crypto) |
| Peer-add pacing | `ML_PEER_ADDS_PER_PASS=4` | a 100-peer MapResponse used to drain in one pass (~10 s of X25519 stall); now ~4 adds/10 ms, loop returns for heartbeats |
| NVS peer-cache write debounce (5 s) | `ml_peer_nvs_flush_if_due` | first sight of 100 peers rewrote the growing blob once **per peer** (~465 KB flash into a 24 KB partition, cache-stalling both cores); now the PSRAM working copy is authoritative and flash catches up ≤1×/5 s (+ flush on deinit) |
| CallMeMaybe broadcast pacing | `ML_CMM_SENDS_PER_PASS=2` | post-STUN CMM to all sessionless peers was an all-at-once seal burst + inbound ping storm; now resumable 2/pass |
| Heartbeat seal cap + per-peer phase jitter | `ML_HB_SEALS_PER_TICK=8` | a shared trust-renewal moment (AP blip) aligned every peer's next heartbeat into one tick; jitter de-aligns the fleet, cap bounds the tick |
| Sessionless handshake-retransmit cap | (active-clear) | the lease/demotion path re-armed `peer->active`, and wireguardif then retried an initiation (~90 ms) every 5 s **forever** for peers that never answer; non-priority peers with no session get `active` cleared (inbound initiations still establish sessions) |
| Dedup ring 16→64, pending-probe table 32→64 | `WG_DEDUP_RING_SIZE`, `MAX_PENDING_PROBES` | dual-path dedup and probe tracking sized for 100+ peers |

## Capacity raise

`CONFIG_ML_MAX_PEERS` 16→128 (Kconfig range 1→128, sdkconfig +
sdkconfig.defaults); `WIREGUARD_MAX_PEERS` 16→128; the WG device
`heap_caps_calloc(MALLOC_CAP_SPIRAM)` explicit (was policy-dependent
`mem_calloc`), with an internal-RAM fallback; `cfg.max_peers=128` in
dcs_support.c; settings-blob validation and web-UI cap 64→128. Memory
delta ≈ **+130 KB PSRAM, ~0 internal RAM** (+1 KB BSS for the probe
table). No wire-protocol change; the settings-blob `max_peers` is uint8
with append-only versioning, so no NVS-format break.

## Deliberately NOT changed

- **NVS peer *cache* stays 64** (`CONFIG_ML_NVS_MAX_PEERS`): 128 entries
  (11.8 KB blob) can't safely coexist with a populated allowlist in the
  24 KB NVS partition. Growing the partition moves `ota_0` → full reflash
  - NVS wipe + re-provisioning — a flash-layout breaking change deferred
  to a hardware/major revision. The cache is only a boot accelerator;
  the control plane repopulates the rest.
- **WG sessions stay lazy** (peers added passive, sessions form on peer
  initiative) — no separate slot allocator needed; idle PSRAM slots cost
  only the 400 ms periodic's `valid` check.
- **Allowlist** Kconfig is already 512; keeping it *populated* in
  deployment remains the primary outbound-load bound.

## Validation (bench, 2026-07-21)

Real 100-peer tailnets aren't available on the bench, so
`tools/disco_storm.py` injects well-formed **unknown-key** DISCO pings at
the chip's UDP 51820 — driving the exact worst-case box-open path a large
tailnet produces. Concurrent 10 Hz pstop link measured throughout (new
USB chip, no loops wired so verdict is STOP — the test is heartbeat
continuity under crypto load, not arming).

| Storm rate | pstop sent/replies | send_fail | rebonds | RTT | boot_count | machine heartbeat timeout |
|---|---|---|---|---|---|---|
| baseline | lockstep | 0 | 0 | 5 ms | 0 | none |
| 40 pps | 1973/1973 | 0 | 0 | 5 ms | 0 | none |
| 600 pps (≈1.5× budget capacity) | 3336/3336 | 0 | 0 | 5 ms | 0 | none |

At 600 pps — above the ~400 opens/s budget — excess disco crypto is shed
while the heartbeat stays fully isolated: RTT unchanged, no dropped ticks,
no rebonds, wg_mgr stack healthy. **The 128-peer build boots clean
(`boot_count=0`), confirming the explicit PSRAM placement holds the
internal heap** — the v15.6 "64 peers exhausts internal RAM" warning does
not apply under the current SPIRAM-malloc policy + explicit placement.

### Real-tailnet validation (2026-07-21, Polymath tailnet, 343 nodes)

Run on the live Polymath tailnet — no synthetic control plane needed.
The bench chip registered (`vpn_ip 100.117.20.69`, `state CONNECTED`) and
pulled the **full 128 peers** (capped from 343 real nodes: macbooks,
robots, peplinks, desktops — all organically DISCO-probing it), while
heartbeating pstop to the laptop machine over the WireGuard tunnel.

| Metric | Result over the ingestion + steady window |
|---|---|
| peers pulled | **128 / 128** (cap), `ml_state=4` throughout |
| pstop cadence | exactly 10 Hz (1056 sent / 106 s), replies in lockstep |
| rebonds | **1** (the initial post-boot bond) — no storm |
| mismatches / send-fails | **0 / 0** |
| boot_count / crashes | 0 / none |
| comparator tick | never starved — 10 Hz held under full 128-peer DISCO load |
| 6-min steady hold | up 398 s, bc 0, 3729 sent, 1 rebond, **1 mismatch / 3729 ticks** (0.03 %, single core-publish-timeout, absorbed by machine loss-tolerance), 6/128 peers upgraded to direct |

This is the max-load case the earlier revision of this doc flagged as
unvalidated: the load bounds + shared-key cache + 128-peer NVS all held
together on a genuine 128-peer tailnet. Note the pstop RTT read ~110 ms
here — a **bench-topology artifact**, not a regression: the chip's only
uplink is the laptop's shared connection, so reaching the laptop's *own*
Tailscale IP hairpins through DERP. A remote and robot with independent
internet form a direct path (~20–70 ms, as measured in
`TRANSPORT_TEST_REPORT`).

Still worth doing later: a mass simultaneous trust-lease flap (toggle the
uplink with 128 peers bonded) to exercise the heartbeat-spread + retransmit
caps at scale.

## Optional follow-ups (not done)

- NaCl `beforenm` shared-key cache per known peer (~32 B/peer): removes
  the per-open/seal X25519 for known peers — a large multiplier on every
  budget above. Worth it if organic load ever approaches the budgets.
- Honor runtime `config.max_peers` as the actual `add_peer` bound (today
  the compile-time `ML_MAX_PEERS` is the only bound; the runtime knob is
  cosmetic).

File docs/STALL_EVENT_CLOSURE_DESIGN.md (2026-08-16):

<!-- SPDX-FileCopyrightText: 2026 Polymath Robotics -->
<!-- SPDX-License-Identifier: Apache-2.0 -->

# Closing the all-path stall class (run-33 residual) — design

Status: REVIEWED (adversarial agent, APPROVE-WITH-CHANGES) — this revision
incorporates all 7 required changes. Scope: the single remaining disarm class after
PR #96 — a ~2-4 s machn-side stall that ages ALL remotes' heartbeats
simultaneously (run-33 +167m: LAN-only PS included, ages fresh at samples,
self-healed 11 s). Plus the queued low-risk items (operator directive).

## 1. Evidence and the prime suspect

At the event: all three remotes' rtt elevated 1.3-1.5 s and ages crossed
2.0 s between 2 s samples; machn's `wg_max_iter_ms` gauge did NOT register a
new worst — but its high-water mark already sat at 5.2 s, so any stall
under 5.2 s is invisible to it (gauge blind spot, see §3). The DERP task's
rx-poll gap DID set a new worst (4.5 s) in the same window. machn-local
gateway-ping loss (11-15%) accrues while external probes measure the LAN
fabric at 0% loss — the loss is machn-side egress, not the wire.

The one remaining UNBOUNDED crypto path on the heartbeat task (`ml_wg_mgr`
loop, 10 ms cadence):

- The WG-rx drains (loop-head unbounded `while(xQueueReceive)` plus FOUR
  other processing sites: the peer-add and disco interleaves via
  wg_mgr_drain_wg_rx, the post-disco tail drain, and the pre-registration
  drain) are "safety first" — but HANDSHAKE packets share that FIFO with
  the heartbeats, and an inbound INITIATION costs ~4 X25519 ≈ 45 ms
  MEASURED (11.3 ms/op, docs/CRYPTO_SPEEDUP_REPORT.md; a response ≈ 2 ≈
  23 ms). A wave of ~44-88 initiations stalls heartbeat processing 2-4 s.
  Every other burst source in this loop is already budgeted (disco opens,
  peer-adds with safety-decrypt interleave, CMM sends).
- THE COUPLING MECHANISM: each handshake is processed holding
  LOCK_TCPIP_CORE (CONFIG_LWIP_TCPIP_CORE_LOCKING). A wg_mgr crypto burst
  therefore also stalls the DERP task's lwIP sockets (the observed 4.5 s
  rx-poll gap) and machn-local ICMP egress (the observed gw-ping loss) —
  one lock explains all three observations. Task priorities exonerate CPU
  starvation (safety 8 > wg_mgr 7 > DERP 5).
- Secondary: `wireguardif_periodic()` can INITIATE rekeys inline for all
  peer slots in one call — unbounded, deferred evidence-first (§5).

Plausible trigger: SESSION-ESTABLISHMENT PHASE-LOCK — sessions
(re)established together (boot, or a prior stall) rekey phase-locked every
~120 s (REKEY_AFTER_TIME) indefinitely; re-ingest is verifiably hitless to
WG sessions and cannot phase-lock rekeys itself. Unproven — §3's
instrumentation decides it from the next event (a 120 s comb in the
existing wireguardif_periodic timing log would confirm).

## 2. Fix A — handshake budget on the WG-rx drain (core, ~25 LOC)

ONE budgeted drain helper replaces ALL FIVE wg_rx processing sites (a
single shared per-pass budget — a handshake deferred at one site must not
be processed unbudgeted at another):

> Scope caveat: "all five sites" covers the `wg_rx_queue` ingestion model
> only. With `CONFIG_ML_ZERO_COPY_WG=y` (default n, no in-tree config
> enables it), direct-UDP WG packets bypass the queue — `zc_pcb_recv_cb`
> calls `wireguardif_network_rx()` inline on tcpip_thread — so a handshake
> wave on that path runs unbudgeted under LOCK_TCPIP_CORE. Thread the same
> budget into `ml_zerocopy.c` before enabling zero-copy.

- Drain is SNAPSHOT-BOUNDED: `uxQueueMessagesWaiting()` at entry caps the
  pops this call — a requeued handshake cannot be re-popped in the same
  pass (the naive while-loop would livelock spinning on its own requeue).
- DATA packets (heartbeats, replies, cookies): drain freely, unchanged.
- HANDSHAKE packets (len>=4 && data[0] 0x01/0x02 — verified identical
  framing on both producer paths): consume from
  `ML_WG_HANDSHAKES_PER_PASS` (default 3 ≈ ≤135 ms worst per pass at the
  measured 45 ms); excess handshakes REQUEUE to the tail with a per-packet
  attempt counter (new u8 in ml_rx_packet_t padding). On requeue FAILURE
  (queue refilled by a concurrent producer) or attempt cap
  (`ML_WG_HS_REQUEUE_MAX`, default 12 — must exceed one pass's worth of
  pops so a deferral survives to the next pass's budget): free(pkt.data) + count
  (`wg_hs_dropped`) — never leak, never spin. Deferrals count
  (`wg_hs_deferred`).
- Fail-safe direction: a deferred/dropped handshake can only delay a
  REKEY — initiators retransmit at 5 s with ~60 s of session margin
  (REJECT_AFTER_TIME 180 s vs rekey start 120 s); the active session keeps
  decrypting heartbeats. Worst case = the existing rekey-late nuisance
  stop, never a missed stop.

## 3. Fix B — stall-EVENT instrumentation (telemetry only, ~40 LOC)

High-water gauges can't attribute events (blind under their own mark).
Add a small event ring (8 entries, DERP-task/wg-task-owned, monitor-read):

- wg_mgr: when an iteration exceeds 1000 ms, record {boot_s, dur_ms,
  wg_pkts, handshakes, peer_adds, disco_opens, periodic_ms,
  disco_probe_ms} for that iteration (per-pass counters; the last two are
  already timed at their call sites).
- DERP ring for iterations > 1000 ms: {boot_s, dur_ms, home_cstate
  (DERP_CS_* — separates residual blocking-DNS from rx backlog),
  last_dns_ms, rx_gap_ms}.
- Entries published via a release-stored write index (the in-tree
  zero-copy ring pattern); readers may see a torn in-flight entry, never a
  torn published one.
- NEW edge-drop counters at BOTH wg_rx producers (net_io UDP + DERP
  route): today they drop silently on a full queue; post-Fix-A a
  storm bigger than the drain rate sheds heartbeats AT THE EDGE while
  every iteration stays short — without `wg_rx_enqueue_drops` the rings
  are blind to exactly the mode Fix A creates.
- Export all of it in /admin/api/monitor; the soak driver already
  snapshots the monitor at each disarm, so the next event self-attributes.

## 4. Queued low-risk items riding along

- **#42 partial (gauge ONLY):** export `fleet_region_missing` (bool: fleet
  peer configured with region 0). The reviewed-out fallback is DROPPED:
  `ML_DERP_REGION` is 9 while this fleet lives on region 2 — a compiled-
  default aux would be a permanently useless TLS conn, and injecting
  synthetic regions into `ml_wg_collect_safety_regions` could re-home the
  machine itself (it also feeds the home-fallback candidate list). Root
  cause of the learning gap stays open (#42) — likely server-side map
  content for machine-role nodes.
- **ops:** run-33's START line printed a hardcoded stale build label;
  interpolate EXPECTED_FW instead (driver-only).

## 5. Explicitly out of scope

- Timeout/margin changes (2.0 s stands; operator-only).
- pstop_c: untouched.
- wireguardif_periodic rekey-initiation bounding: DEFERRED unless the §3
  rings attribute an event to it (touching wireguard_lwip's periodic path
  has wider blast radius than the rx-drain budget; do it evidence-first).
- ENOTCONN kick (#32), region sweep (#30), host-test PR: unchanged queue.

## 6. Validation

Bench: build both roles; flash uniform; verify budget behavior (handshake
storm synthesized by rebonding all remotes at once = flash-boundary reboot
does exactly this) and rings populate on induced stalls. Then the operator
gate: 8 h zero-exclusion soak, normal protection (hourly reports, disarm
class diagnosis via the new rings, HIL gesture rearm, driver preflight).
Success: 0 drops, or any drop fully self-attributed by the rings.

## 7. Phase 2 (2026-08-15): re-ingest quiescence + region stash + ring v2

Status: DRAFT for review. Evidence: run-34 rings (steady-state 1.0-2.0 s
stall clusters, every entry adds=4 with ~70-90% of the duration
unaccounted) and the post-run storm (2,998 ms cluster during flush
recovery, compounding losses). Root chain, source-verified: the 5-min
re-register re-ADDs every peer; existing-peer re-adds already skip the
WG reinstall (hitless re-ingest), but each one still calls
ml_peer_nvs_save() → dirties the peer cache → the 5 s-debounced
ml_peer_nvs_flush_if_due() commits to FLASH in-loop — and a flash write
suspends flash-resident execution on BOTH cores, stalling wg_mgr, the
DERP task and ICMP egress at once (the "unaccounted" time; also the
likely body of run-33's 2-4 s event and run-34's forensic 2.7 s gap).

### 7a. Skip-unchanged re-adds (fix 3 core, ~20 LOC)
In add_peer(), for an EXISTING peer, compare the material fields
(public_key match is given; disco_key, hostname, vpn_ip, and the update's
carried region/endpoints vs stored) and RETURN EARLY when nothing
changed: no memcpys, no maybe_rehome, no ml_peer_nvs_save (⇒ no dirt ⇒
no flash flush), no pacing slot consumed (adds_this_pass unchanged —
skipped re-adds are ~µs). Counter: peer_readds_skipped. Effect: a
5-min re-register of an unchanged map becomes telemetry-free and
flash-free; re-ingest clusters only occur when the map genuinely changed.

### 7b. Flush quiet-gate (fix 3 belt, ~6 LOC)
ml_peer_nvs_flush_if_due() additionally defers while
uxQueueMessagesWaiting(peer_update_queue) > 0 (an ingest burst is in
progress — the worst moment to suspend the cores). Flash writes then land
in genuinely quiet passes. The existing 5 s debounce stays.

### 7c. Learned-region stash (fix 4 / task #42, ~18 LOC)
Both existing region writes already preserve-on-zero; the wipe is
REMOVE→re-ADD: the fleet peer is pinned but NOT is_safety_peer, so the
hitless-reingest remove-veto does not protect it, and a fresh slot has
nothing to preserve. Minimal fix that changes no remove/veto semantics:
a 4-entry {pubkey, region} stash written when a PINNED peer with a
nonzero learned region is removed; add_peer consults it when the incoming
update carries region 0. Counter: region_stash_restores. (The
server-side question — why machn's map omits the fleet region — stays
open in #42.)

### 7d. Ring v2 + soak-driver self-audit (fix 5, ~15 LOC + ops)
- wg ring entries gain cmm_sends (site exists at the CMM pacing loop).
- wireguardif stamps worst_rx_gap_at_ms when the per-peer worst updates
  (one field + one line in wireguardif.c, accessor alongside the existing
  one) — makes cumulative-gauge events datable (run-34's 2,720 ms and the
  DUT's 19.6 s reconcile become decidable).
- ops driver: hourly line gains machn pstop-side rebond totals and
  rx_worst_gap(+at) so blind-window drops self-audit.

### 7e. Explicitly out of scope (unchanged)
Timeouts; pstop_c; wireguardif_periodic bounding (rings show ≤62 ms all
night — exonerated); moving flush to another task (flash suspension is
core-global — the fix is writing less and at quiet times, not elsewhere).

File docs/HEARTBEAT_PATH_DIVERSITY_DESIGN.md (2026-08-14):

<!-- SPDX-FileCopyrightText: 2026 Polymath Robotics -->
<!-- SPDX-License-Identifier: Apache-2.0 -->

# Heartbeat path diversity — relay-leg mirroring (design + resource analysis)

Status: **IMPLEMENTED (e9a7faa) + field-validated** — run-31: 400+ home-conn
RSTs absorbed overnight with ZERO disarms and worst heartbeat gap <1 s
(vs 13 disarms/3 h on the pre-diversity build under lighter storms);
dedup verified exact (sent==replies, ratio 1.00); rescue-router saved 746
frames in the first storm hour alone.
Goal: a heartbeat gap requires MULTIPLE simultaneous path deaths, so false
protective stops become rare at the EXISTING 2 s failsafe latency (operator
ceiling: ≤4 s; nothing here changes any timeout).

## 1. What already exists (and where it is blind)

`peer->dual_path` (wireguard_lwip) is ON for every safety peer, both roles:
when a DIRECT endpoint exists, every encrypted WG packet (heartbeats, replies,
rekeys) is also mirrored over DERP (`derp_output_fn`), and the receiver's
standard WG anti-replay window (RFC2401, wireguard.c:320) silently drops the
duplicate. Dedup is free, protocol untouched.

run-29/30 disarm ledger against that machinery — the blind spots:

| Blind spot | Ledger evidence | This design |
|---|---|---|
| B1. Relay-bound peer = DERP **single**-path (no direct endpoint ⇒ nothing to mirror; wireguardif.c:163 branch) | disarms #1–#3: relay-bound remotes gapped while machn's home conn reconnected | fix (relay-leg diversity) |
| B2. The DERP leg (mirror OR sole leg) routes to ONE conn (peer-region, fallback home; `derp_route_conn`) and **drops silently** if it's down | every storm window where home was mid-reconnect | fix (pool fallback + second leg) |
| B3. Stale direct endpoint (NAT wiped): direct leg blackholes; covered ONLY if the DERP leg survives | full-wipe disarms | hardened by B1/B2 fix |
| B4. wg_mgr/lwIP stall (machn-side, all-remote simultaneous gap) | disarms #4/#10/#12 class; `wg_max_iter_ms` gauge in run-30 | NOT addressed here (separate: ingest bounding) |

## 2. Design: safety-frame DERP leg diversity

One change, both roles, entirely in `ml_derp_queue_send()` + `derp_route_conn`
usage (components/microlink):

For frames whose destination is a heartbeat carrier (`ml_wg_tx_class_pubkey()`
at the enqueue path: mirror = priority OR health-tracked; the fleet pin keeps
its priority-queue slot but is NOT mirrored — reachability armor, not a
heartbeat carrier):

1. **Primary leg (today's):** peer-region conn, else effective-home conn.
2. **NEW second leg:** one ADDITIONAL connected pool conn, chosen as:
   the peer's home-region conn and the effective-home conn when both are up
   and DISTINCT; else any other CONNECTED pool conn (a DERP server only
   delivers to clients connected to it — but both ends hold multi-region
   pools via the safety want-set, so cross-region delivery is real: verified
   by the DUT's 4-slot pool in the field).
3. **Fallback (replaces silent drop):** if the primary is down, the frame
   goes to ANY connected conn instead of being dropped.
4. Non-safety frames: unchanged (single leg).
5. Receiver: no change anywhere — WG anti-replay dedups; DERP servers ignore
   frames for absent clients (today's semantics).

Failure algebra after: a heartbeat gap now requires
(direct dead) AND (DERP leg A dead) AND (DERP leg B dead-or-same-server-down)
inside one 2 s window. Tonight's ledger reread: every network-class disarm
had ≥1 surviving pool conn at the disarm instant.

## 3. Resource analysis (operator-required, first)

Frame: pstop heartbeat ≈ 60 B payload → WG transport ≈ 92 B → DERP
SendPacket framed ≈ 92 + 45 (hdr+key) ≈ ~140 B → TLS record ≈ ~170 B wire.

**Bandwidth** (worst case, all legs active):
- Remote (1 machine): 5 Hz × 1 extra leg ≈ **0.85 kB/s up** (plus existing).
- Machine (3 remotes, replies): 15 Hz × 1 extra leg ≈ **2.6 kB/s up**.
- At 10-remote scale: ~8.5 kB/s extra — noise against any uplink; DERP
  servers see one extra small TLS record per heartbeat.

**CPU** (per extra leg, machine @15 Hz worst case):
- No extra WG encrypt (the SAME encrypted packet is mirrored — encryption
  happens once, before transport fan-out).
- Per leg: one queue enqueue + one memcpy (~140 B) + one AES-GCM TLS record
  (HW AES, ~10–20 µs incl. overhead on S3).
- Total ≈ 15 × ~30 µs ≈ **<0.5 ms/s = <0.05 % CPU**. The prio-queue drain is
  already budgeted per loop (ML_DERP_TX_PRIO_DEPTH drained fully first).

**Memory:**
- Zero new buffers or structs. Each mirrored frame is one extra
  `ml_derp_tx_item_t` (existing pool/queue) alive for <1 loop iteration.
- Queue headroom: prio queue depth 12 vs machine worst case 3 remotes ×5 Hz
  ×2 legs = 30 items/s, drained every ~1 ms loop → instantaneous occupancy
  ≤2–3. At 10 remotes ×2 legs = 100/s → occupancy still <8. **Bump
  ML_DERP_TX_PRIO_DEPTH 12 → 16** as margin (16 × ~24 B item = +96 B RAM).
- Net RAM delta: **~+100 B**. Flash: ~1–2 kB code.

**Radio/coexistence:** DERP legs are TCP on the existing conns — no new
sockets, no new RF behavior.

## 4. Implementation sketch (~60–100 LOC)

- `ml_derp_queue_send()`: after the existing enqueue, if
  `ml_wg_is_safety_pubkey(dest)` → compute second leg conn (distinct,
  connected) → enqueue a second item tagged with that conn's region so
  `derp_route_conn` picks it; if the primary’s region conn is down at DRAIN
  time, existing home-fallback already applies — extend the final drop case
  to try any-connected before dropping (counter: `derp_tx_leg2 +
  derp_tx_rescue_routes` for observability).
- Item struct gains nothing (region_id field already routes).
- Both roles get it by construction (shared component).

## 5. Validation (operator directive #3)

Bench: verify duplicate suppression (machine `pstop_replies` rate unchanged,
WG replay drops counter increments), then **stop run-30 and start run-31**
(12 h zero-exclusion, same format) the moment the build is verified. Success
metric: network-class disarms → 0 through ≥1 real storm; only B4
(wg_mgr-stall class) may remain, tracked by `wg_max_iter_ms` correlation.

## 6. Explicitly out of scope
- Any timeout change (2 s stands; operator ceiling 4 s held in reserve).
- ESP-NOW/BLE sidechannel (separate feasibility study in flight).
- B4 wg_mgr ingest bounding (own fix, pending run-30 correlation data).
- pstop_c: untouched (transport-only; dedup is WG-native).

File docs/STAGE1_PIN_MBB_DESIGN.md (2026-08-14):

<!-- SPDX-FileCopyrightText: 2026 Polymath Robotics -->
<!-- SPDX-License-Identifier: Apache-2.0 -->

# Stage 1 — Gapless forced region switch (pin → make-before-break)

Status: **IMPLEMENTED (36c768d + b4f7b5e) — pending bench validation (§8).**
Date: 2026-08-13. Parent plan: `NONBLOCKING_DERP_TLS_PLAN.md` (Stage 1 of 4).
Implementation deltas from this design (all safety-neutral): no httpd→wg_mgr
poke (the 3 s self-heal cadence IS the next tick — pin latency ≤3 s); the
no-live-home case fires nothing (the DERP task's own home-reconnect already
connects to the override); two extra executor fixes found during
implementation — the "already effective" check and the want-set exclusions
compared against `ml_effective_home_region()`, which under a pin equals the
override from the instant it is set, so both had to compare against the LIVE
home conn's region instead (§4.3 of commit b4f7b5e; also prevents a duplicate
aux to the region the home actively serves during the prove window).
Repro + evidence: run-26 + real-flush wire data (memory
`reference_pstop_switch_home_reconnect_dropgap`; peer artifacts
`flush-20260813T112019Z-*`).

Scope decisions (operator, 2026-08-13):

1. **Switch-path only.** The dead-home (RST/flush) reconnect is out of scope
   — different mechanism (nothing alive to keep serving), handled by the
   async engine (Stages 2–3).
2. **Command routing through wg_mgr** — the negotiator stays the single
   writer of the MBB command interface.
3. **Pin fallback = retry forever, never gap.** A pin toward an unprovable
   region keeps the old (working) home and retries with backoff; green is
   never risked to honor a pin faster.
4. **Delivery: new PR stacked on #94.** Gate: ~25-switch forced-switch soak,
   0 green drops, MBB-commit (no-teardown) logs confirmed.

---

## 1. Problem (one paragraph)

`POST /api/settings {"derp_region":N}` (machn, admin) applies a region pin by
firing `ML_EVT_DERP_RECONNECT` (`ml_config_httpd.c:649`). The DERP task
handler (`ml_derp.c:1272-1309`) **tears down the live home conn, then
blocking-reconnects** (DNS→TCP→TLS ~1-2 s on the DERP I/O task). During that
window the task cannot service rx, and the machn's inbound heartbeat
processing gaps; when the gap crosses the 2 s machine timeout the dual-core
verdict drops ROBOT_OK → nuisance fail-safe disarm (~1 in 5 switches on the
bench, self-recovers ~12-20 s, but latches disarmed pending a re-arm
gesture). Meanwhile the codebase already contains a **gapless** home switch —
the §7 MBB executor (`derp_mbb_tick`, `ml_derp.c:904`): open the target as an
aux, prove it (rx echo / PONG), then swap `derp_home_slot` **by index, no
teardown**; the old home drains as an aux via the want-set. Autoneg uses it;
the pin does not.

## 2. Design in one sentence

Make the pin a **first-class MBB source**: the httpd handler only records the
override; the wg_mgr negotiator (already the MBB single-writer) issues an MBB
command toward the override whenever the home conn is alive; the legacy
teardown path remains only for the no-live-home case (cold boot / already
dead — where there is no gap to protect).

## 3. Invariant change (the one semantic edit)

Today's executor invariant **I2** — "a lock landing mid-switch wins
instantly: ABORT" (`derp_mbb_tick`, `ml_derp.c:~928`) — was written for locks
preempting an *autoneg* switch. Stage-1 revises it:

> **I2':** an override aborts an in-flight MBB **only if it names a different
> region than the MBB target** (operator preemption). An MBB whose target
> *equals* the override is the override being applied — it proceeds.

Everything else in the executor (prove gates, generation preemption,
`SWITCH_ADVERT` commit, rollback) is reused verbatim.

## 4. Changes by file

### 4.1 `components/microlink/src/ml_config_httpd.c` (handler, ~646-665)

- **Remove** the direct `xEventGroupSetBits(..., ML_EVT_DERP_RECONNECT)`.
- Keep: `derp_region_override = N`, `config_save_settings()` (NVS), and the
  coord re-advertise (`microlink_request_announce`) — the re-advertise is
  independent of transport switching and must stay (PS-wedge fix).
- Add: `ml_wg_notify_region_pin(ml)` — a thin poke so the negotiator
  evaluates the pin on its next tick without waiting for a natural pass
  (see 4.2). Log line switches from "slot-0 reconnect" to "pin routed via
  negotiator (MBB when live)".

### 4.2 `components/microlink/src/ml_wg_mgr.c` (negotiator)

`neg_apply_target()` override branch (~1251-1263) currently:
`priority_peer_region = target; neg_cancel_mbb(); derp_home_region = target;
fire ML_EVT_DERP_RECONNECT`. Replace with:

```text
if (ml->derp_region_override != 0) {
  ml->priority_peer_region = target;            /* advert: unchanged */
  if (home_conn_alive(ml)                        /* NEW: gapless path */
      && ml->derp_home_region != target) {
    if (ml->mbb_target_region != target) {
      s_neg_pending_source = MICROLINK_REGION_SRC_LOCK;
      ml->mbb_target_region = target;            /* same single-writer issue */
      ml->mbb_generation++;
      s_pin_mbb_requests++;
      log "PIN via MBB: region %u -> %u (gapless; old home drains)"
    }
    /* else: already in flight toward the pin — let it run */
  } else if (ml->derp_home_region != target) {
    /* no live home = nothing to protect: legacy immediate rehome */
    s_diag_rehome_applied++;
    ml->derp_home_region = target;
    fire ML_EVT_DERP_RECONNECT                    /* unchanged cold path */
  }
  return;
}
```

- `home_conn_alive(ml)`: `ml->derp[ml->derp_home_slot].connected` — read on
  the wg_mgr task; a torn read costs one conservative fallback to the legacy
  path (same as today's behavior), never a wrong commit.
- **Damping exemption:** the pin branch sits *above* the §8 damping guards
  (stability window, dwell, switches/hour circuit-breaker) exactly as the
  override branch does today — an operator pin is deliberate; it must not be
  suppressed. The MBB dedupe (`mbb_target_region == target → return`) is the
  only rate limit it needs.
- **Ban exemption:** `neg_region_banned()` is NOT consulted for the pin
  (matches today: the lock ignores autoneg's bad-region cooldowns).

**Outcome consumption (retry-forever):** where the negotiator consumes
`mbb_outcome` (ML_MBB_OUTCOME_ROLLED_BACK), add: if
`ml->derp_region_override == rolled_back_target`:
- do **not** ban the region (a pin is a command, not advice);
- schedule re-issue with backoff: 5 s → 15 s → 60 s, then every 60 s
  (`s_pin_retry_at_ms`, RAM-only), re-issuing the same
  `mbb_target_region`/generation bump when due;
- increment `s_pin_mbb_retries`; status stays `pin_pending` (see 4.4).
The old home keeps serving throughout — green never at risk. Pin lands on
the first successful prove once the region becomes reachable.

### 4.3 `components/microlink/src/ml_derp.c` (executor, minimal)

- **I2 → I2'** (~928): `if (override != 0 && override != s_mbb.target) abort`.
- No other executor change. The aux open reuses the want-set; during its
  blocking TLS handshake the home conn keeps being **pumped**
  (`derp_pump_home_rx`, commit 6832794) — Stage-1 composes with the pump:
  home stays connected *and* its rx is serviced during the new conn's
  handshake. The residual CPU burst is the same one switches #1-#4 survived
  in run-26 *without* a live home; with the home alive and pumped the
  timeout race is removed, not just narrowed.
- `ML_EVT_DERP_RECONNECT` handler: **unchanged** (still the correct path for
  RST/EOF dead-home recovery and the cold rehome).

### 4.4 Observability (small, same files)

- Counters (wg_mgr, exposed via `ml_wg_get_neg_diag` extension or a new
  4-word getter): `pin_mbb_requests`, `pin_mbb_commits` (from outcome
  consumption), `pin_mbb_retries`.
- `/admin/api/status`: `pin_pending` = (override != 0 &&
  effective_home != override) — lets the soak driver and the fleet console
  distinguish "pin applied" from "pin retrying".
- Existing `mbb_pending_region` / `mbb_state` already surfaced — reused for
  validation.

## 5. Ownership / concurrency review

Unchanged model. The negotiator remains the only writer of
`mbb_target_region`/`mbb_generation` (httpd never touches them — it writes
`derp_region_override` exactly as today, already a published cross-task
word). The executor remains the only writer of `derp_home_slot` and conn
state. `derp_home_region` gains no new writer: in the MBB path the executor
sets it at commit (existing); in the legacy path the negotiator sets it
(existing). The single new cross-task read (`derp[home_slot].connected` from
wg_mgr) is a volatile word read with a fail-conservative fallback. No locks
added; no pstop_c contact (`components/microlink` only — reliability, not
safety; every failure mode below fails toward "old home keeps serving" or
"legacy behavior", both green-safe or no-worse-than-today).

## 6. Edge cases

| # | Case | Behavior |
|---|---|---|
| 1 | Pin while autoneg MBB in flight toward a **different** region | Negotiator issues pin target → generation bump preempts (executor restarts toward pin). I2' aborts nothing (override == new target). |
| 2 | Pin while autoneg MBB in flight toward the **same** region | Dedupe: command already in flight; executor proceeds; commit satisfies the pin. |
| 3 | Pin to the current home region | `derp_home_region == target` → no-op (advert refresh only). |
| 4 | Pin cleared (override → 0) mid-MBB | I2' no longer matches (override 0 ≠ abort condition — add explicit: target-source was LOCK and override cleared → negotiator `neg_cancel_mbb()` on its next pass; executor aborts on generation bump). Autoneg resumes ownership. |
| 5 | Pin changed N→M mid-MBB | Negotiator issues M, generation bump restarts executor toward M. Retry state resets. |
| 6 | Home conn dies mid-MBB (flush during switch) | Executor's existing stability gates fail → rollback; RST path reconnects home as today (out of scope); negotiator retries pin once home is back (4.2 fallback picks legacy if home still dead at retry). |
| 7 | Pinned region genuinely dead | Retry-forever with 60 s cap; `pin_pending` visible; old home serves indefinitely. Operator sees unfulfilled pin in status rather than a disarm. |
| 8 | Reboot with pin set (NVS) | Boot path connects directly to override region (existing `ml_effective_home_region` — no live home to protect; unchanged). |
| 9 | Remote peers' stale netmap | Unchanged: `microlink_request_announce` re-advertise still fires from httpd (4.1). MBB commit additionally sends NOTE_PREFERRED on both conns (existing). |

## 7. What Stage-1 does NOT fix (explicit)

- **Dead-home reconnect** (edge-flush RST, drops #2/#3 of run-26): the
  blocking reconnect with no live home remains; that is Stages 2–3 (async
  handshake state machine). Stage-1 removes the *forced-switch* trigger and
  proves the MBB-for-pin plumbing those stages build on.
- The reconnect-storm/RTT-inflation under sustained stress (scale ceiling):
  also Stages 2–3.

## 8. Validation plan (gate for the PR)

**Results so far (2026-08-13, machn OTA'd with bcc9d5d, verified behaviorally
via the new `pin_pending` monitor field):**
- **8.1 matrix: PASS.** Pins 9→2→10→12→9: 4/4 committed gaplessly in 12-15 s
  (pin tick ≤3 s, prove ~10 s, index swap), **`derp_reconnects` stayed 0 for
  the whole matrix** (legacy path was +1/switch), green held on every 3 s
  sample, 3/3 direct throughout.
- **8.2 negative: legacy semantic inherited, not testable on this bench.**
  Pinning a nonexistent region (999) COMMITS rather than retries: unknown
  regions fall back to the compiled default DERP host (`ml_derp.c` region
  lookup, documented pre-existing behavior identical in the legacy path), so
  the conn connects and proves against a real server. The retry-forever
  machinery therefore engages only for genuinely unreachable regions
  (server/network down) — exercised by code review + the rollback path;
  every failure mode degrades to "old home keeps serving".
- **8.3 preemption: PASS.** Pin →2 re-pinned →10 4 s later: executor
  restarted to 10 immediately (generation bump), exactly one commit, landed
  on 10, green held, reconnects 0.
- **8.4 run-27 gate soak: 17/17 SWITCHES GREEN, 0 switch-triggered drops**
  (runs 27a–d, 2026-08-13, stopped at 17/25 by the operator with the edge in
  a sustained flush storm — evidence deemed sufficient). Breakdown: 8 (27a,
  build bcc9d5d) + 1 (27b, 38b4645) + 8 (27c/d, cbb1545 machn), including
  **3 switches committed gaplessly MID-STORM** and run-26's killer
  transition (switch #5 → region 2) repeatedly. `pin_commits` tracked
  +1/switch exactly; `derp_reconnects` stayed FLAT during switching (the
  legacy path cost +1/switch and ~1/5 disarms). ~10 non-switch disarms
  occurred across the day — every one attributed to real edge flush events
  by independent wire captures (peer pcap µs clocks) or concurrent
  RST-counter deltas, and excluded per the pre-registered triage; none were
  switch-triggered. Contrast baseline: run-26 on the legacy path = 1
  switch-triggered disarm in 13 switches plus a reconnect storm and RTT
  inflation, none of which recurred under pin→MBB.
- **Residual (out of scope, Stage-2/3):** dead-home flush survival — a
  flush that RSTs the live home conn (or wipes the NAT hairpins) can still
  gap heartbeats 2–9.5 s. Five wire-attributed case studies with disarm
  wall-clocks are banked as the Stage-2 validation targets.

1. **Bench live-switch matrix** (fast): pin 9→2→10→12→9 with all 3 remotes
   bonded; for each switch confirm in logs: `PIN via MBB` → `MBB AUX_OPENING`
   → `MBB COMMIT` (and **no** `DERP reconnect requested` line); green held;
   `pin_mbb_commits` increments; `derp_reconnects` does NOT increment.
2. **Negative prove test:** pin to an unreachable/bogus region id → verify
   `pin_pending`, retries at 5/15/60 s cadence, old home serving, green
   held; then pin back → immediate recovery.
3. **Preemption test:** start pin 9→2, immediately re-pin →10 (case 5);
   verify single commit to 10.
4. **25-switch soak** (run-27): run-26 driver re-used verbatim (20 min
   cadence, cycle [9,2,10,12], ~8 h). PASS = **0 green drops** across ≥25
   switches + every switch shows an MBB COMMIT (no teardown). Contrast
   metric vs run-26: drop rate 3/13 → 0/25; `derp_reconnects` stays ~flat
   (was +1/switch); RTT median should no longer step up per switch.
5. **Opportunistic real-flush overlay:** peer watchers stay armed; a flush
   during run-27 exercises the *unfixed* dead-home path — expected outcome
   documented (possible disarm, same as run-26 drops #2/#3), NOT a Stage-1
   failure. Distinguish via logs (`DERP reconnect requested` = flush path).

## 9. Deliverables

- One PR stacked on #94 (branch `derp/pin-mbb` off `derp/relay-recovery`):
  - commit 1: negotiator + httpd routing (+counters/status)
  - commit 2: executor I2' + LOCK-source abort handling
  - commit 3: docs (this file moves to Implemented status + soak results)
- run-27 soak report (25+ switches, table + verdict) before requesting
  review.

## 10. Effort / risk

Small diff (~150-200 LOC net, three files), no new tasks, no new locks, no
sdkconfig change, no pstop_c contact. Highest-risk element is the outcome/
retry bookkeeping in the negotiator (new small state machine: `s_pin_retry_at_ms`
- backoff): mitigated by the negative prove test (8.2) and by the fact that
every retry failure mode degrades to "old home keeps serving" (green-safe).

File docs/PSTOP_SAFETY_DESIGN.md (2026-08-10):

# Protective-Stop (pstop) Integrity Chain — Safety Design

> **Reconciliation status — updated 2026-08-02.** This document has been
> reconciled against the current firmware and **predates the shipped code**. It
> is **SIL2-framed**; the program target is now **SIL 3 / PL e**
> (`docs/safety/SYSTEM_DEFINITION.md`). Its **§5–§10 describe the DROPPED
> "Option C" integrity chain** (LFSR/PRNG challenge, `S ^= (Cn ^ En)` liveness
> accumulator, stamp echo-signature) and an **unimplemented GPIO
> config-integrity check** as if live. The **implemented** stuck-at/systematic
> controls are **Option A** (fresh both-phase physical sample every tick) +
> **Option B** (two cores form the verdict by diverse expressions; a byte
> `memcmp` of the two 40-byte encodings detects divergence). Inline
> `> **[Reconciled 2026-08-02]**` notes and bold status markers
> (**DROPPED 2026-07** / **NOT IMPLEMENTED**) below correct each claim **without
> deleting the original design rationale**. Full register:
> `docs/safety/RECONCILIATION.md`. Ground truth: `SYSTEM_DEFINITION.md`.

**Status:** design record. §2 describes what is implemented today
(verified against `firmware/main/main.c`); §4–§8 are the SIL2 hardening
roadmap, still awaiting decisions. Merged from the former
ESTOP_SAFETY_DESIGN.md + ESTOP_SAFETY_DECISIONS.md.
**Standard frame:** IEC 61508 (SIL2 target, HFT=1, de-energize-to-safe).
> **[Reconciled 2026-08-02]** Program target is now **SIL 3 / PL e**
> (SYSTEM_DEFINITION; HARA §6). The SIL2 rationale throughout this doc is
> retained as design history; read the integrity level as **SIL 3 / PL e**.
**Scope:** the remote's stop-switch sensing → verdict → pstop message
path. `pstop_c` (machine *and* remote protocol library,
`components/pstop/upstream`, certification track) stays byte-for-byte
unchanged; everything here lives in the application shell
(`firmware/main/main.c`, the comparator, the GPIO sensing) around it.

Terminology: the product function is a **protective stop (pstop)** — the
physical DPST normally-closed button on the loops is referred to as the
"E-stop switch" only as the hardware part name.

---

## 1. The property to guarantee

> There is **no viable execution path** in which the pstop message says
> `OK` while the physical switch loop is open, stuck, or unread.

Equivalently: a sustained `OK` reaching the machine must be *causally and
freshly* derived from a correct, live read of the switch loop on **both**
independent channels. Any fault — open loop, stuck pin, frozen task,
bypassed branch, lost packet, dead machine — must drive the system to
STOP within the process safety time.

## 2. Implemented today (`firmware/main/main.c`)

- **Dual-channel loopback.** Core 0 owns channel A (IO39 drive →
  DPST pole 1 → IO40 sense); core 1 owns channel B (IO41 →
  pole 2 → IO42). Sense inputs are pulled DOWN, so an open loop
  reads 0 (STOP) — fail-safe idle.
- **Rolling drive level.** *(superseded — see reconciled note.)* Each tick
  the owning core drives its OUT pin
  with the tick counter's LSB (10 µs settle, `ESTOP_SETTLE_US`) and
  verifies the echo. The loop counts as closed only when the most recent
  drive-high echoed high (continuity) AND the most recent drive-low
  echoed low (no stuck-high short). Until both phases have been sampled
  the channel reads OPEN.
  > **[Reconciled 2026-08-02]** **Superseded by Option A both-phase.** The
  > current code (`main.c:265-308`) samples **both phases every tick** — drive
  > HIGH → read → drive LOW → read, in one call — and **ignores the tick
  > counter** (`(void)counter;` "both phases are sampled every tick; no rolling
  > phase", `main.c:269`). The verdict is thus fresh each tick with no two-tick
  > latency. The "rolling counter-LSB, one phase per tick" text above is the
  > *predecessor* design and is what SYSTEM_DEFINITION means by "not the old
  > rolling `counter&1`".
- **Asymmetric release debounce** (`LOOP_RECLOSE_DEBOUNCE_TICKS = 3`).
  The open→STOP edge is single-tick — the stop path is never filtered.
  The closed→OK edge requires 3 consecutive healthy reads, so
  EMC-induced blips produce a ≥300 ms STOP episode instead of chatter.
- **Boot warm-up hold** (`LOOP_BOOT_OPEN_CONFIRM_TICKS = 5`). The
  comparator sends NOTHING until each channel has settled (one full
  closed-debounce cycle, or 5 consecutive open reads = switch genuinely
  held at boot). This keeps the boot-time loop glitch from putting a
  STOP→OK episode (the arming gesture) on the wire at every power-on.
- **Lockstep comparator.** Both cores independently compute a verdict and
  encode the full 40-byte `pstop_msg_t`; the comparator memcmps the two
  encodings — including the CRC — and transmits only on agreement.
  2oo2-to-run, 1oo2-to-stop: a single-channel fault makes the cores
  disagree → nothing is sent → the machine heartbeat-times out to STOP.
- **Machine-side arming policy** (`host/machine_app_runner.c`,
  `min_stop_ms = 500` in `host/machine.toml`): a STOP episode must be
  held ≥500 ms for its OK release to count as the arming gesture; shorter
  STOP→OK cycles are vetoed via the library's public
  `machine_stop_robot()`. See `FAILOVER_AND_ARMING_DESIGN_2026-07-21.md`.

## 3. The black channel is end-to-end

pstop_c is explicitly a black-channel protocol:

- The machine echoes the remote's own data back in every reply
  (`protocol.c`): `resp->received_counter = req->counter`,
  `resp->received_stamp = req->stamp`.
- The machine also *validates* the reverse direction — it checks that the
  remote correctly echoed the machine's counter/stamp, with bounded loss
  and monotonic time (`MSG_LOST`, `OUT_OF_ORDER`).

Both ends can therefore confirm their own data made the full round trip,
and the machine's *native* checks already trip to STOP if the remote's
counter/stamp sequence stalls or regresses. That gives a closed loop —
remote → machine → remote — that the GPIO can be **spliced into**, so a
GPIO fault breaks a chain the *machine* polices, not just the remote.

## 4. Gaps in today's design (the SIL2 case)

| # | Gap | Why it matters at SIL2 |
|---|-----|---|
| G1 | **Common-cause / systematic SW faults.** Two cores run identical code → an identical bug yields identical wrong `OK` → comparator agrees. | Byte-compare gives ~0 systematic-fault coverage (β≈1). Usually the dominant SIL2 risk. |
| G2 | **Bypassable verdict.** `closed ? OK : STOP` is a branch; a wild write / optimizer / logic bug can reach `OK` without a read. | Defeats "OK ⟺ correct read." |
| G3 | **Predictable challenge.** `counter&1` is a known toggle; a fault that happens to track it isn't forced to reveal itself. | Lowers diagnostic coverage (DC). |
| G4 | **Loose coupling to the message.** The verdict is computed *beside* the message, not woven into the data that round-trips. | A stale/forged value can ride the protocol. |

> **[Reconciled 2026-08-02]** How these gaps were actually dispositioned:
> **G3** is **moot as written** — the predictable `counter&1` was *not* fixed by
> the dropped LFSR challenge; the adopted compensating measure is **Option A**
> both-phase sampling (a stuck pin fails the high *or* low phase without any
> unpredictable challenge; `counter` is ignored, `main.c:269`). **G1**
> (common-cause) is addressed by **Option B** diverse expressions, **not** the
> §5.4 semantic comparator (see the §5.4 note). **G2/G4** were targets of the
> dropped Option-C chain and remain **residuals** tracked in HARA (H-06/H-09)
> and FMEA (DU-3/DU-5), not closed controls.

## 5. Proposed integrity-chain architecture — **DROPPED 2026-07 (Option C)**

> **[Reconciled 2026-08-02]** **The entire §5 integrity chain below was assessed
> and NOT adopted (Option C, dropped 2026-07).** The LFSR/PRNG challenge (§5.1),
> the `S ^= (Cn ^ En)` liveness accumulator (§5.2), the stamp echo-signature
> (§5.3), the semantic-1oo2D comparator (§5.4), and the runtime GPIO
> config-integrity check (§5.5) are **not in the code**. The implemented controls
> are **Option A** (fresh both-phase physical sample per tick, `main.c:265-308`)
> - **Option B** (two cores form the verdict by diverse expressions — arithmetic
> image `:305` vs boolean `:307` — with a byte `memcmp` of the two 40-byte
> encodings, `:890`, detecting divergence). The text is kept as design rationale;
> see per-subsection notes and `docs/safety/RECONCILIATION.md` (R-01/R-02/R-04).

One token must circulate the **entire** physical+logical loop every
cycle, and must come back fresh and correct to keep `OK` alive:

```
 per-core LFSR challenge Cn
        │  drive
        ▼
   GPIO OUT ─▶ DPST pole ─▶ GPIO IN   (echo En; En==Cn iff loop closed+healthy)
        │  read
        ▼
   fold En into: (a) counter advance   (b) stamp signature
        │  pstop msg
        ▼
      MACHINE  ──(native checks: counter +1, stamp monotonic, bounded loss)──┐
        │  resp.received_counter = req.counter                               │
        │  resp.received_stamp   = req.stamp   (black-channel echo)          │
        ▼                                                                    │
   REMOTE verifies: my counter/stamp (and the echo signature) returned ◀────┘
        │  only then →
        ▼
   advance token / emit next OK     ── else STOP (chain stalled anywhere)
```

### 5.1 Dynamic challenge–response loopback (fixes G3)
Replace `counter&1` with a per-core rolling pseudo-random challenge
(LFSR seeded per core), optionally multi-bit per tick — a genuine short
serial loopback — and verify the full echo each tick.

### 5.2 Liveness accumulator — no bypass (fixes G2)
Maintain a per-core accumulator that *is* the safety value:
`S ^= (Cn ^ En)` — zero contribution iff the echo matched. `OK` is gated
on `S == seed` AND a freshness counter that must advance every tick.
Emitting `OK` provably requires a history of correct live reads; there is
no constant `OK` to fall through to, and the data dependency stops the
compiler from hoisting/caching the read.

### 5.3 Splice the GPIO into the black-channel round-trip (fixes G4)
Using only existing wire fields (pstop_c unchanged):
- **Counter backbone (machine-enforced).** Gate the counter advance on a
  correct echo: a GPIO fault stops counter progress → the **machine's
  own** `MSG_LOST`/heartbeat logic trips to STOP, with zero machine
  changes.
- **Stamp signature (freshness/anti-replay).** Carry a rolling signature
  of the measured echoes in the low bits of `stamp` (kept strictly
  increasing). The machine echoes it verbatim in `received_stamp`; the
  remote checks the returned signature against the challenge sequence it
  drove — proving the machine acted on the exact, current GPIO-derived
  message.

### 5.4 Dual-core diversity + comparator contract (fixes G1 — the crux)
Make the two channels diverse by construction: core 0 active-high sense,
challenge seed A, GPIO data-register read; core 1 active-low, seed B,
driver-API read. A systematic bug in one encoding does not reproduce
identically in the other. This forces the comparator from byte-identical
`memcmp` to **semantic 1oo2D**: each core emits {verdict, liveness
proof, fresh sequence}; the comparator checks they agree on meaning AND
each proof is valid+fresh, then emits the single canonical pstop message.
Any disagreement, stale proof, or missing proof → send nothing → STOP.

> **[Reconciled 2026-08-02] — Framing correction.** The implemented comparator
> is a **byte-identical `memcmp`** of the two 40-byte encodings (`main.c:890`),
> **not** a semantic 1oo2D. This is **sufficient by design, not a skipped
> control**: **Option B** makes the two cores emit **byte-identical** encodings
> when healthy (core 0 arithmetic image `k_estop_msg[((rb_hi^1)|rb_lo)&1]` `:305`
> vs core 1 boolean `(rb_hi==1)&&(rb_lo==0)` `:307` — the *same* OK/STOP codeword
> when correct), and any caught fault makes one core's bytes **differ**, which
> the memcmp catches. The semantic comparator was therefore rendered
> **unnecessary**, not omitted. **Do not overclaim:** this rests on the two
> source expressions staying non-convergent through one toolchain/ISA, and the
> shared code *after* codeword selection (override/debounce, encode) is β≈1.
> Common-cause coverage is **not quantified** — it requires FMEDA **and** the
> §10 row-9 fault-injection proof (HARA §6; FMEA DU-3/DU-5).
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

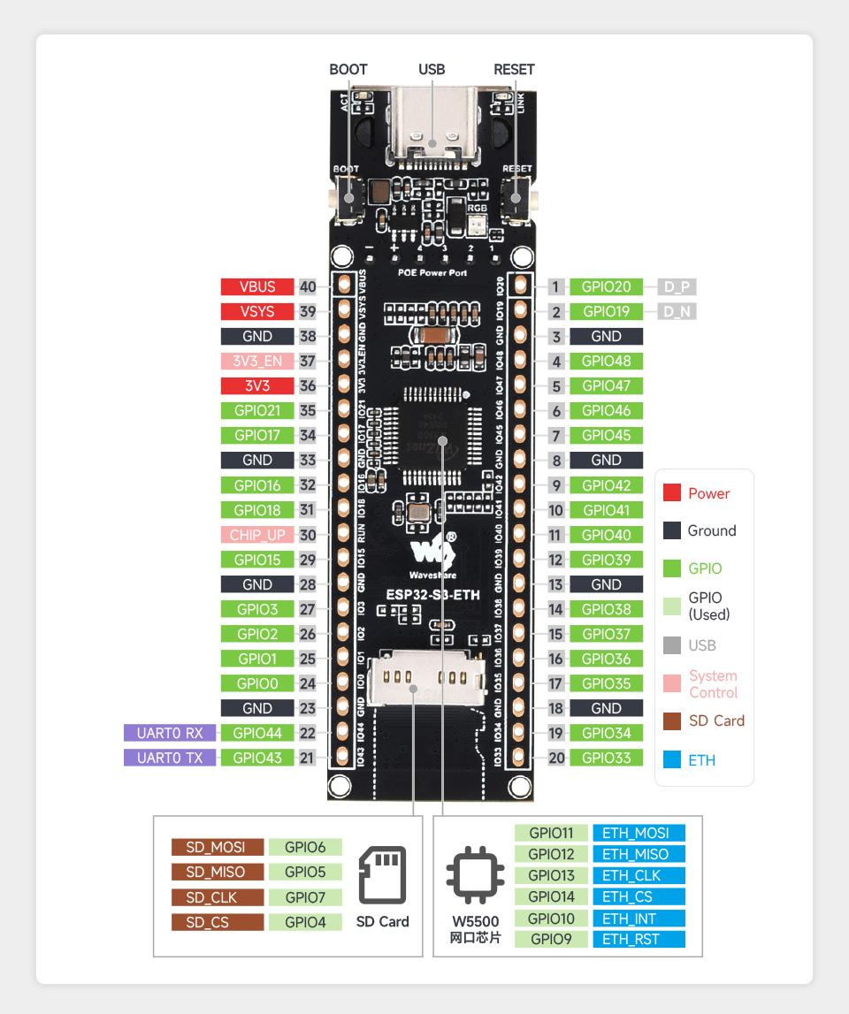
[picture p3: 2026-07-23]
hardware/ESP32-S3-ETH-details-15.jpg

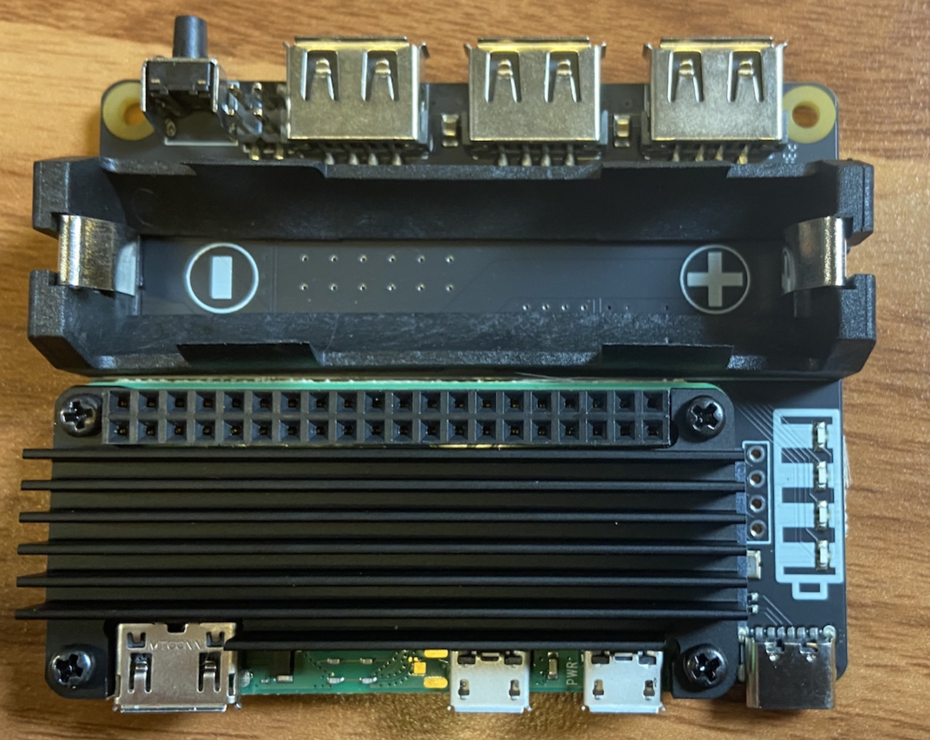
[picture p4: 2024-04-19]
docs/img/applied-heatsink.png

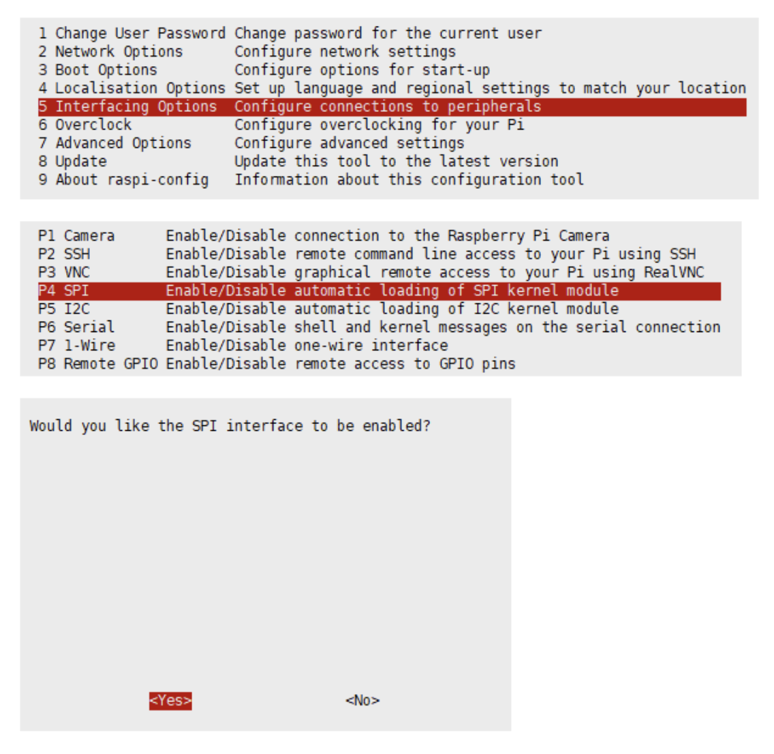
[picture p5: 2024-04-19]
docs/img/rpi-config.png

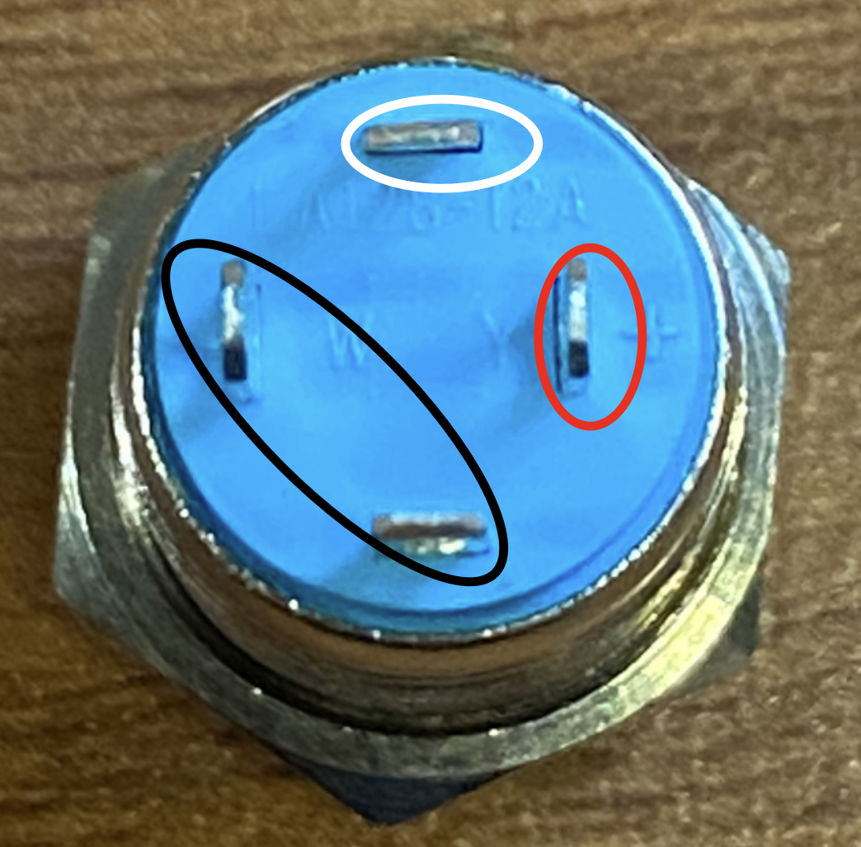
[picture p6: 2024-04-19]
docs/img/powerbutton-colors.png

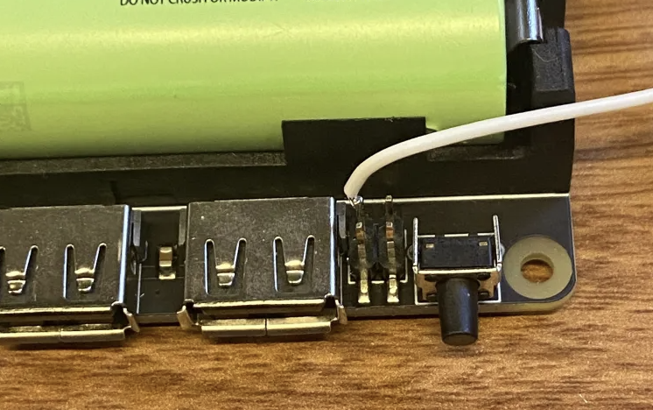
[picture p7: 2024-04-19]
docs/img/powerbutton-white.png

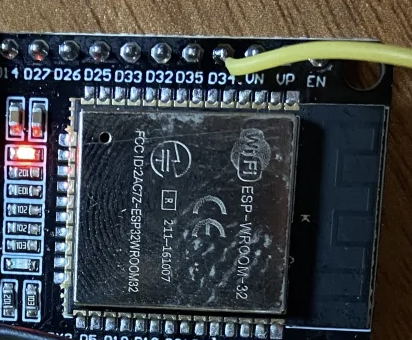
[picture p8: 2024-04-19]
docs/img/esp-d34.png

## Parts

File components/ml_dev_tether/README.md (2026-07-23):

# ml_dev_tether — USB-CDC-NCM tether for dev iteration

Opt-in microlink module. When the ESP32-S3 boots, brings up its USB-OTG
controller as an NCM (Network Control Model) Ethernet device and waits for a
DHCP lease from the connected host. If a lease arrives, that netif becomes
the default route — DERP/Tailscale traffic rides over USB to the host,
through the host's existing internet, and out. If no lease arrives within
the configured timeout, falls back to WiFi.

## Usage on the device side

```c
#include "ml_dev_tether.h"

void app_main(void) {
    ml_app_config_t cfg = ML_APP_CONFIG_DEFAULT();
    cfg.try_alt_network        = ml_dev_tether_try_start;
    cfg.alt_network_timeout_ms = 5000;
    ml_app_start(&cfg);
}
```

Also enable the NCM class in `sdkconfig.defaults`:

```
CONFIG_TINYUSB_NET_MODE_NCM=y
```

## Host-side setup (Linux, NetworkManager)

Easiest approach — let NetworkManager handle DHCP server + NAT
automatically. Plug the ESP32 in once, then:

```sh
# Find the new interface (look for the locally-administered MAC)
ip link show

# Configure NetworkManager "shared" connection on it (does DHCP + NAT)
nmcli connection add type ethernet ifname <usb-iface-name> \
    con-name esp-tether ipv4.method shared ipv6.method ignore
nmcli connection up esp-tether
```

Verify:

```sh
ip addr show dev <usb-iface-name>     # should see 10.42.0.1/24 or similar
ping <esp-ip>                          # should see <1 ms
```

## Host-side setup (Linux, manual)

If NetworkManager isn't your friend, dnsmasq + iptables:

```sh
sudo ip addr add 192.168.7.1/24 dev <usb-iface-name>
sudo ip link set <usb-iface-name> up
sudo dnsmasq --interface=<usb-iface-name> --bind-interfaces \
    --dhcp-range=192.168.7.2,192.168.7.10,1h --no-daemon &
sudo sysctl -w net.ipv4.ip_forward=1
sudo iptables -t nat -A POSTROUTING -o <wan-iface> -j MASQUERADE
sudo iptables -A FORWARD -i <usb-iface-name> -j ACCEPT
sudo iptables -A FORWARD -o <usb-iface-name> -j ACCEPT
```

## Caveats

* **Single USB-C connector on XIAO ESP32-S3.** USB-OTG and USB-Serial-JTAG
  share D+/D-. Enabling TinyUSB takes the JTAG console with it — the device
  re-enumerates as an NCM device (no `/dev/ttyACM*` console). Recovery:
  hold BOOT + tap RESET to enter ROM bootloader (USB-Serial-JTAG is provided
  by ROM), then `idf.py flash` works again. OTA over WiFi or over the USB
  netif also works.
* **First-boot fallback latency.** On boot, `ml_dev_tether_try_start` waits
  up to `alt_network_timeout_ms` for a DHCP lease before falling back to
  WiFi. Keep this short (~5 s) for fast cold-boot when no host is
  attached.
* **No hot-plug.** Tether is one-shot at boot. If you unplug USB while
  tethered, the netif loses its lease but won't auto-fall-back to WiFi.
  Reboot to retry.
* **No PSRAM-less boards.** Tested on ESP32-S3. ESP32 classic has no
  USB-OTG.

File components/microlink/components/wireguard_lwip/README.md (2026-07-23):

# WireGuard Implementation for lwIP

This project is a C implementation of the [WireGuard&reg;](https://www.wireguard.com/) protocol intended to be used with the [lwIP IP stack](https://www.nongnu.org/lwip/)

# Motivation

There is a desire to use secure communication in smaller embedded devices to communicate with off-premises devices; WireGuard&reg; seems perfect for this task due to its small code base and secure nature

This project tackles the problem of using WireGuard&reg; on embedded systems in that it is:
- malloc-free so fits into a fixed RAM size
- written entirely in C
- has low memory requirements in terms of stack size, flash storage and RAM
- compatible with the popular lwIP IP stack

# Code Layout

The code is split into four main portions

- wireguard.c contains the bulk of the WireGuard&reg; protocol code and is not specific to any particular IP stack
- wireguardif.c contains the lwIP integration code and makes a netif network interface and handles periodic tasks such as keepalive/expiration timers
- wireguard-platform.h contains the definition of the four functions to be implemented per platform (a sample implementation is given in wireguard-platform.sample)
- crypto code (see below)

## Crypto Code

The supplied cryptographic routines are written entirely in C and are not optimised for any particular platform. These work and use little memory but will probably be slow on your platform.

You probably want to swap out the suplied versions for optimised C or assembly versions or those available throught the O/S or crypto libraries on your platform. Simply edit the crypto.h header file to point at the routines you want to use.

The crypto routines supplied are:
- BLAKE2S - adapted from the implementation in the RFC itself at https://tools.ietf.org/html/rfc7693
- CHACHA20 - adapted from code at https://cr.yp.to/streamciphers/timings/estreambench/submissions/salsa20/chacha8/ref/chacha.c
- HCHACHA20 - implemented from scratch following description here https://tools.ietf.org/id/draft-arciszewski-xchacha-02.html
- POLY1305 - taken from https://github.com/floodyberry/poly1305-donna
- CHACHA20POLY1305 - implemented from scratch following description here https://tools.ietf.org/html/rfc7539
- AEAD_XChaCha20_Poly1305 - implemented from scratch following description here https://tools.ietf.org/id/draft-arciszewski-xchacha-02.html
- X25519 - taken from STROBE project at https://sourceforge.net/p/strobe, in addition there is a version optimised for Cortex-M0 processors which requires very little stack taken from https://munacl.cryptojedi.org/curve25519-cortexm0.shtml

# Integrating into your platform

You will need to implement a platform file that provides four functions
- a monotonic counter used for calculating time differences - e.g. sys_now() from lwIP
- a tain64n timestamp function, although there are workarounds if you don't have access to a realtime clock
- an indication of whether the system is currently under load and should generate cookie reply messages
- a good random number generator

# lwIP Code Example
(note error checking omitted)

    #include "wireguardif.h"
    
    static struct netif wg_netif_struct = {0};
    static struct netif *wg_netif = NULL;
    static uint8_t wireguard_peer_index = WIREGUARDIF_INVALID_INDEX;

    static void wireguard_setup() {
    	struct wireguard_interface wg;
    	struct wireguardif_peer peer;
    	ip_addr_t ipaddr = IPADDR4_INIT_BYTES(192, 168, 40, 10);
    	ip_addr_t netmask = IPADDR4_INIT_BYTES(255, 255, 255, 0);
    	ip_addr_t gateway = IPADDR4_INIT_BYTES(192, 168, 40, 1);

    	// Setup the WireGuard device structure
    	wg.private_key = "8BU1giso23adjCk93dnpLJnK788bRAtpZxs8d+Jo+Vg=";
    	wg.listen_port = 51820;
    	wg.bind_netif = NULL;

    	// Register the new WireGuard network interface with lwIP
    	wg_netif = netif_add(&wg_netif_struct, &ipaddr, &netmask, &gateway, &wg, &wireguardif_init, &ip_input);

    	// Mark the interface as administratively up, link up flag is set automatically when peer connects
    	netif_set_up(wg_netif);

    	// Initialise the first WireGuard peer structure
    	wireguardif_peer_init(&peer);
    	peer.public_key = "cDfetaDFWnbxts2Pbz4vFYreikPEEVhTlV/sniIEBjo=";
    	peer.preshared_key = NULL;
    	// Allow all IPs through tunnel
    	peer.allowed_ip = IPADDR4_INIT_BYTES(0, 0, 0, 0);
    	peer.allowed_mask = IPADDR4_INIT_BYTES(0, 0, 0, 0);

    	// If we know the endpoint's address can add here
    	peer.endpoint_ip = IPADDR4_INIT_BYTES(10, 0, 0, 12);
    	peer.endport_port = 12345;

    	// Register the new WireGuard peer with the netwok interface
    	wireguardif_add_peer(wg_netif, &peer, &wireguard_peer_index);

    	if ((wireguard_peer_index != WIREGUARDIF_INVALID_INDEX) && !ip_addr_isany(&peer.endpoint_ip)) {
    		// Start outbound connection to peer
    		wireguardif_connect(wg_net, wireguard_peer_index);
    	}
    }

# More Information

WireGuard&reg; was created and developed by Jason A. Donenfeld. "WireGuard" and the "WireGuard" logo are registered trademarks of Jason A. Donenfeld. See https://www.wireguard.com/ for more information

This project is not approved, sponsored or affiliated with WireGuard or with the community.

- The whitepaper https://www.wireguard.com/papers/wireguard.pdf
- The Wikipedia page https://en.wikipedia.org/wiki/WireGuard 

# License

The code is copyrighted under BSD 3 clause Copyright (c) 2021 Daniel Hope (www.floorsense.nz)

See LICENSE for details

# Contact

Daniel Hope at Smartalock

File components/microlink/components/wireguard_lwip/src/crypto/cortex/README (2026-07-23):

Curve25519 for ARM Cortex-M0 from https://munacl.cryptojedi.org/index.shtml

Public Domain

Introduction

μNaCl (pronounced "microsalt") is a project to bring the crypto part of the Networking and Cryptography library (NaCl) to embedded microcontrollers. At the moment the only full implementation of μNaCl is targeting 8-bit AVR ATmega microcontrollers. Work on NaCl for TI MSP430 and ARM Cortex-M0 is in progress and this websites already provides standalone implementations of Curve25519 for those architectures.

Contributors

The core μNaCl development team consists of Michael Hutter and Peter Schwabe.

μNaCl benefits from contributions by and collaboration with other people. The standalone Curve25519 implementation for TI MSP430 is by Gesine Hinterwälder (Ruhr University Bochum). The standalone Curve25519 implementation for ARM Cortex-M0 is by Björn Haase and Ana Helena Sánchez.

Acknowledgements

Work on μNaCl is supported by the Austrian Science Fund (FWF) under the grant number TRP251-N23 and by the Netherlands Organisation for Scientific Research (NWO) through Veni 2013 project 13114.

Part of the work on μNaCl was done when Michael Hutter and Peter Schwabe were on an invited research visit at Academia Sinica, Taiwan. They thank Bo-Yin Yang for his hospitality.

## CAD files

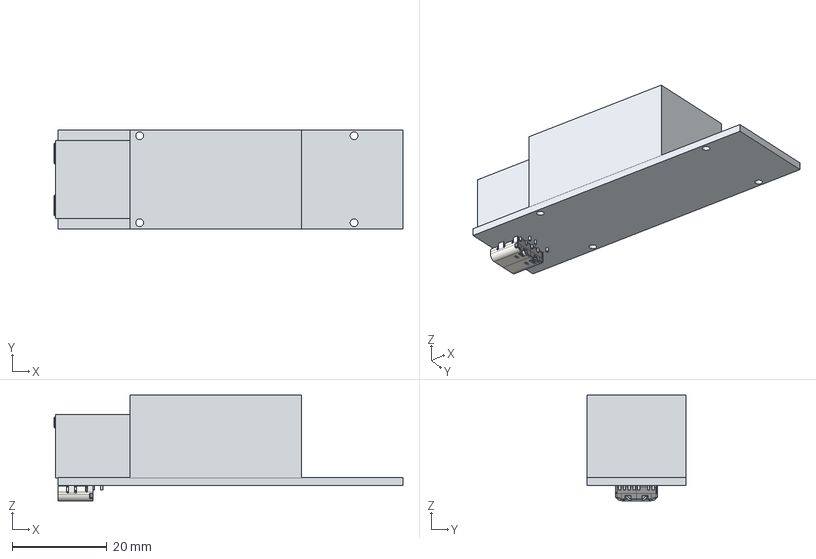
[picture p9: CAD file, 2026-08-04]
hardware/esp32-S3.step
73.8 x 21.0 x 22.3 mm
USB_C_Receptacle_16P_TopMnt_Horizontal_GCT_USB4105-xx-A037
USB_C_Receptacle_16P_TopMnt_Horizontal_GCT_USB4105-xx-A038
USB_C_Receptacle_16P_TopMnt_Horizontal_GCT_USB4105-xx-A039
USB_C_Receptacle_16P_TopMnt_Horizontal_GCT_USB4105-xx-A040

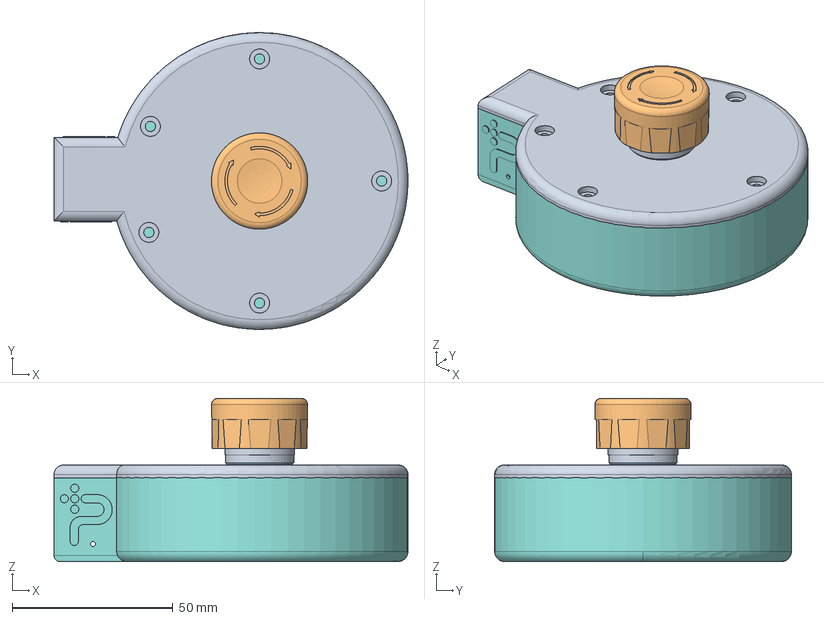
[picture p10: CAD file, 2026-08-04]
hardware/casing.FCStd
110.2 x 92.4 x 50.9 mm
FF01H
FF01CBA
ff01_seal
FF01N
FF01T2
FF01IH
LED
LED001
LED002
LED003
LED Ring Board
LED004
LED005
LED006
LED007
LED008
LED009
LED010
LED011
LED012
LED013
LED014
LED015
base_01
lid_01
USB_C_Receptacle_16P_TopMnt_Horizontal_GCT_USB4105-xx-A041
USB_C_Receptacle_16P_TopMnt_Horizontal_GCT_USB4105-xx-A042
USB_C_Receptacle_16P_TopMnt_Horizontal_GCT_USB4105-xx-A043
USB_C_Receptacle_16P_TopMnt_Horizontal_GCT_USB4105-xx-A044

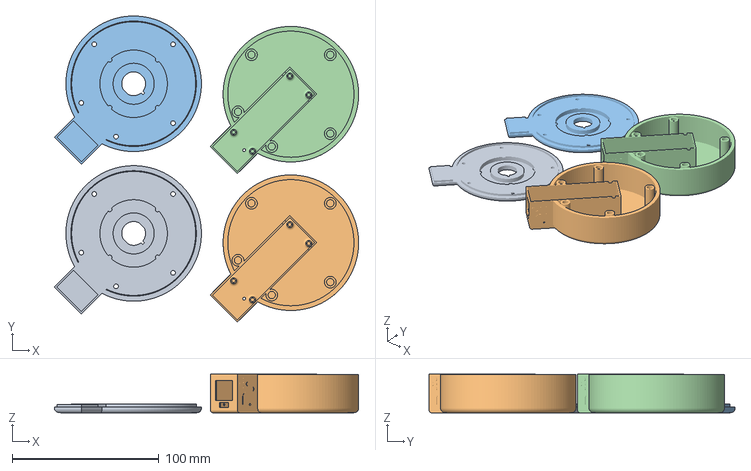
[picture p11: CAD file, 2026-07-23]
hardware/print.3mf
207.4 x 208.6 x 26.3 mm
lid_01.stl x 2
base_01.stl x 2

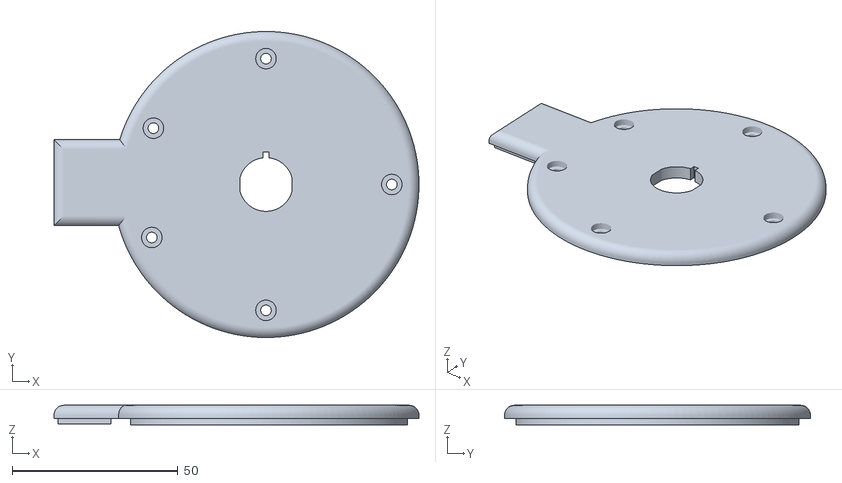
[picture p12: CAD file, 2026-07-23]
hardware/lid_01.stl
110.2 x 92.4 x 5.90

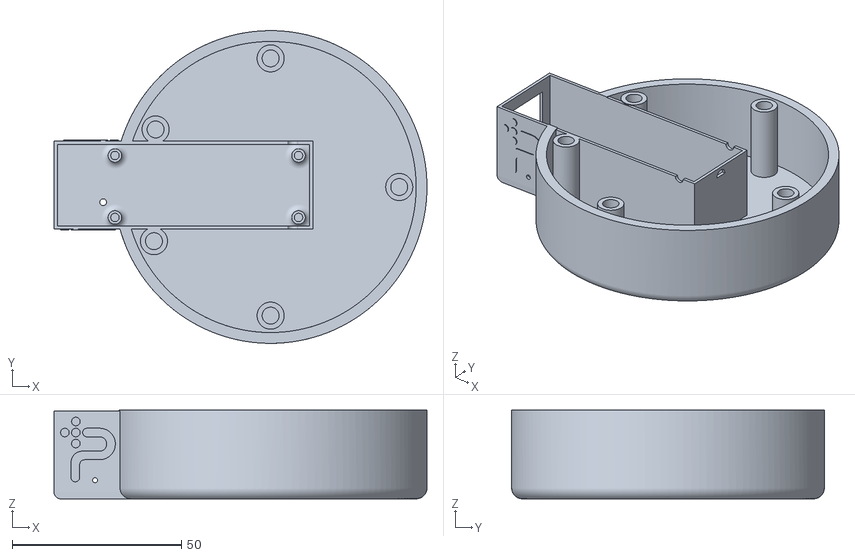
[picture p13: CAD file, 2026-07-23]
hardware/base.stl
110.2 x 92.4 x 26.2

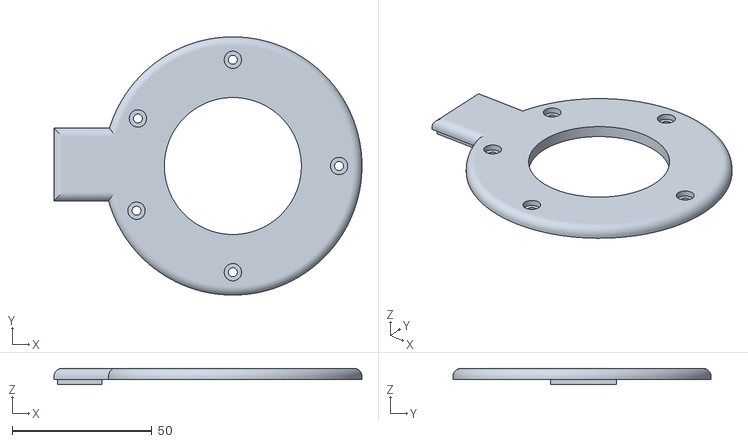
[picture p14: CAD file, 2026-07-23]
hardware/lid-minus-led.stl
110.2 x 92.4 x 5.90

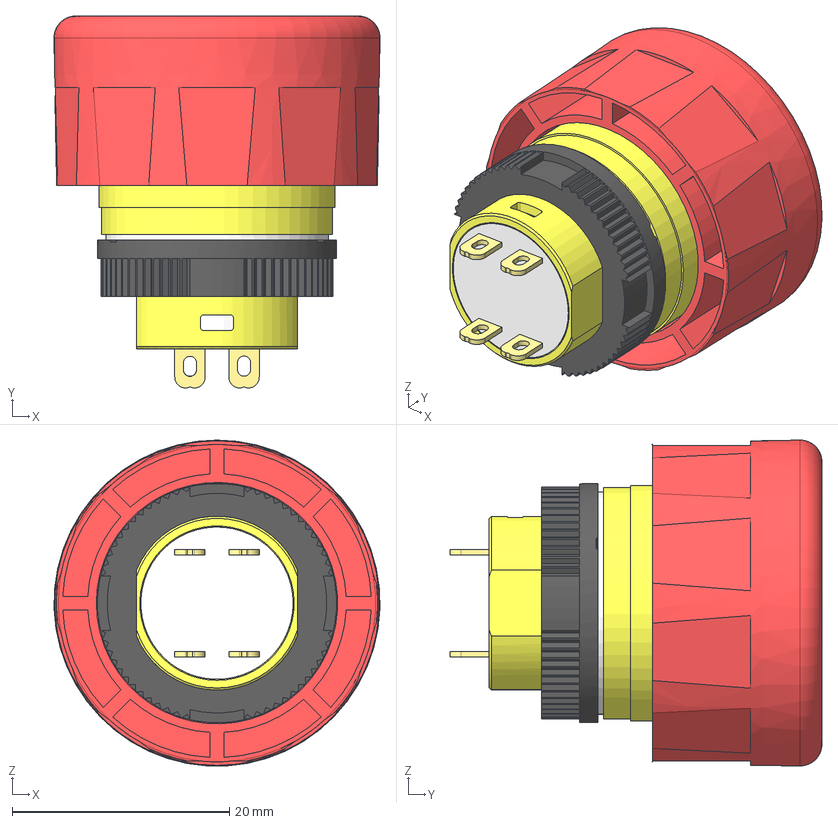
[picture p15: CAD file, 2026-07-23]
hardware/FF0126BBCAEA01.stp
30.0 x 34.2 x 30.0 mm
2 B A
FF01H
FF01CBA
ff01_seal
FF01N
FF01T2
FF01IH

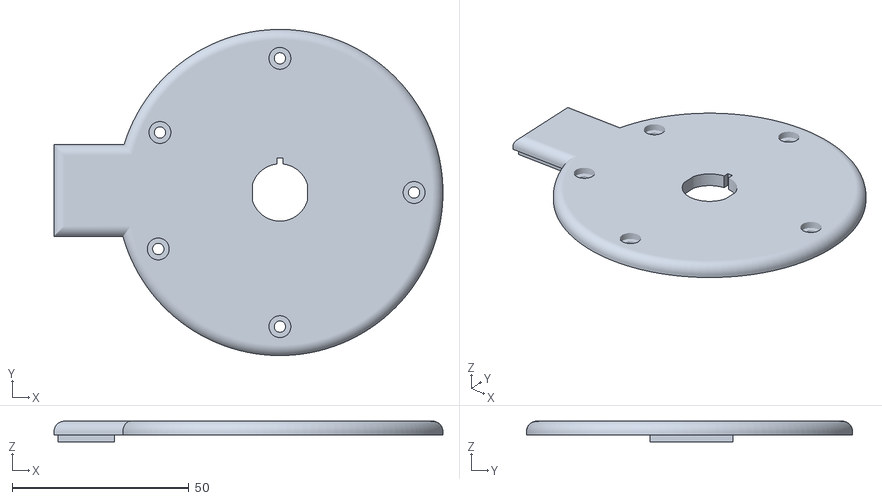
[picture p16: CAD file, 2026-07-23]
hardware/lid.stl
110.2 x 92.4 x 5.90

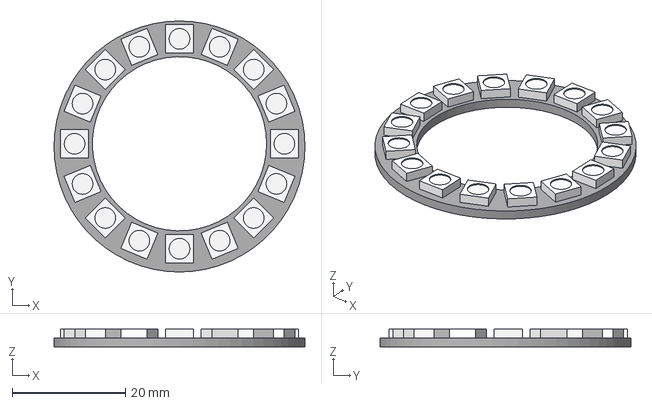
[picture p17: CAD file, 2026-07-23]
hardware/LED.step
44.3 x 44.3 x 3.16 mm
LED x 16
LED Ring Board

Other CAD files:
hardware/print.gcode.3mf
hardware/base_01.stl
hardware/led.stl

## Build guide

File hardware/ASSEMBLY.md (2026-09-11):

# Assembly guide

Building one Protective Stop remote takes about 15 minutes. Order the
parts from the [BOM](README.md#bill-of-materials) and print the enclosure
(`print.3mf`) first; the white diffuser is part of the lid print, not a
separate piece. Wire colors and pin names follow the
[wiring table](README.md#pinout-and-wiring).

Tools: soldering iron (wiring and heat-set inserts), solder, flush
cutters, wire stripper, Phillips screwdriver, 2.5 mm hex driver.

## Printing the enclosure

`print.3mf` is a Bambu Studio project with everything preconfigured; the
plate holds two units (two bases, two lids). The reference setup, straight
from the project file:

- Printer: Bambu Lab X1 Carbon, 0.4 mm nozzle, textured PEI plate.
- Process: the 0.20 mm Strength preset, tuned to 6 walls, 25% grid
  infill, 5 top / 3 bottom shells.
- Filaments: AMS slot 1 is white Bambu PLA Tough+ (base, diffuser,
  supports), slot 2 is yellow PLA Tough+ (lid face). The lid is the
  two-color piece; it prints face-down, so the yellow only appears in
  the first few layers and the AMS swaps are cheap. The diffuser prints
  in the white as part of the lid.
- Tree supports (auto) and auto brim are on; leave them enabled, since
  the side pod overhangs need the support.
- Sliced on this setup, the full plate runs about 4.5 hours and uses
  144 g of filament (136 g white, 9 g yellow) for the two units.
  `print.gcode.3mf` is that exact sliced plate, ready to send to an
  X1C.

Other printers and materials work; keep the walls and infill at least
this heavy, because the lid takes the button's shove every time someone
hits STOP.

## 1. Prepare the base

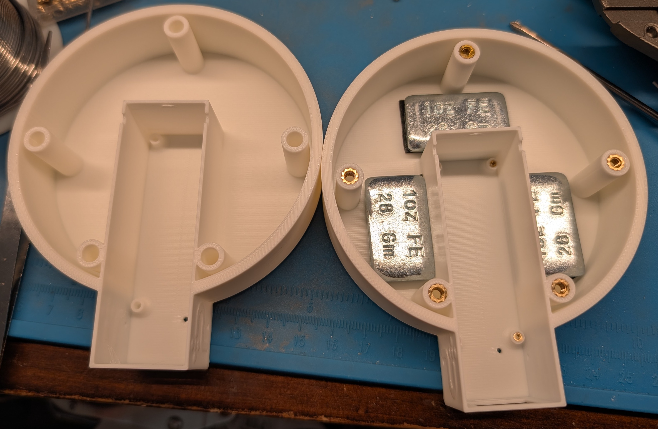
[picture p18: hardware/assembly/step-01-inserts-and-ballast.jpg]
Bare base next to a base with inserts and ballast installed


Press the brass heat-set inserts into the base with the soldering iron:
M3 inserts into the lid-screw bosses, M1.6 inserts into the board anchor
holes in the side pod. Optionally, stick the three 1 oz steel weights
into the floor pockets; they are ballast so the unit stays put on a table
instead of following the Ethernet cable around.

## 2. Mount the button and ring in the lid

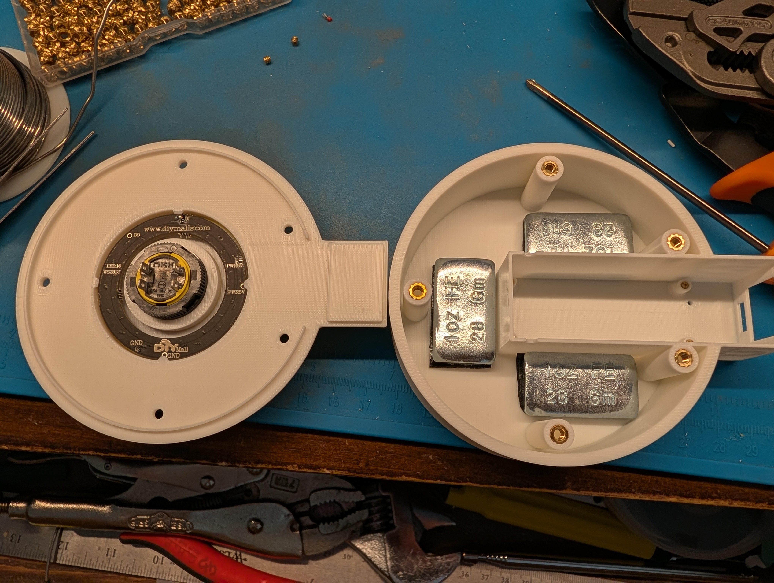
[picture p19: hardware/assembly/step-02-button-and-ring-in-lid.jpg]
Lid underside with the E-stop button and LED ring installed


Push the E-stop button through the center hole from the top and lock it
with its collar from below. Seat the LED ring around the button body,
LEDs facing the diffuser. Rotation does not matter electrically, since
which pixel counts as LED 1 is calibrated over the network after
assembly; for consistency across units, match the orientation in the
photo.

## 3. Solder the board wires and seat the board

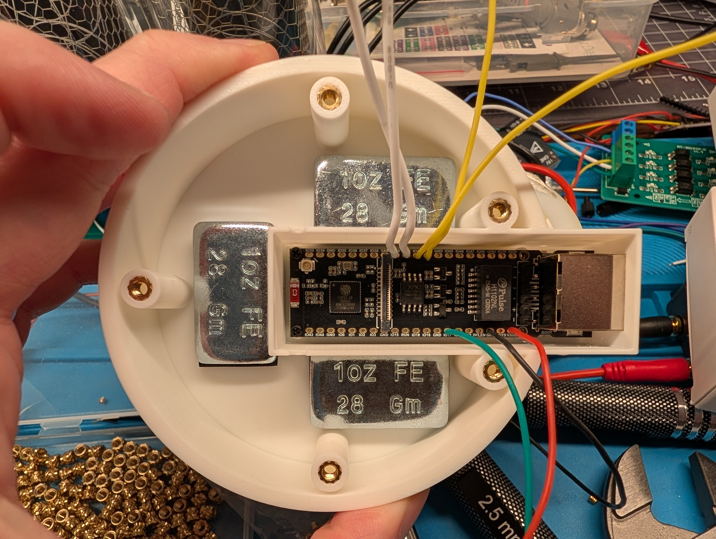
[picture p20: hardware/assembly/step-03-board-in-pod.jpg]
ESP32 board seated in the side pod with wires soldered


Solder the wires to the board pads first, leaving enough slack to open
the lid comfortably:

| Wire | Board pad |
|---|---|
| red | VBUS |
| black | GND |
| green | IO17 |
| white x2 | IO39, IO40 |
| yellow x2 | IO41, IO42 |

Then drop the board into the pod channel, connectors facing out, and
anchor it with the short M1.6 Phillips screws.

## 4. Install the PoE module and wire the lid

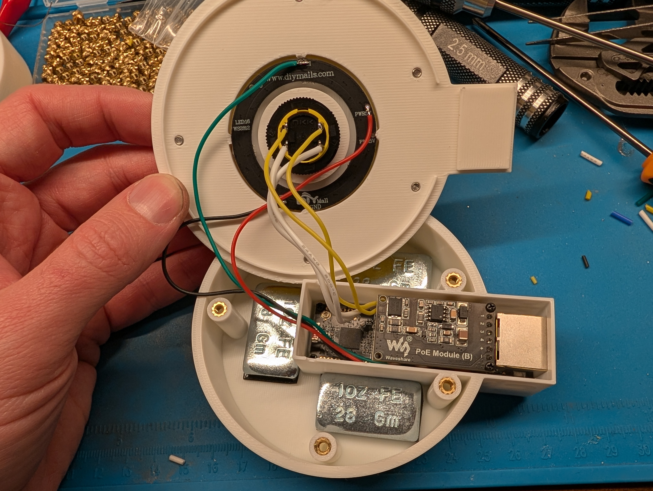
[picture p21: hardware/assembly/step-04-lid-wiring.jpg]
Lid and base joined by the wires


Set the PoE Module (B) onto the board and fasten it with the longer
Phillips screws that come with the ESP32-S3-ETH; every unit gets the
module. Thread the three ring wires (red, black, green) through the
routing hole, then solder the connections: red to PWR5V, black to GND,
green to DI (the ring has two PWR5V and two GND pads; either works, but
mind the DI/DO marking, since data only enters at DI). The white pair
goes to button terminals 11 and 12, the yellow pair to 21 and 22; within
a pair, either wire on either terminal.

## 5. Close the lid

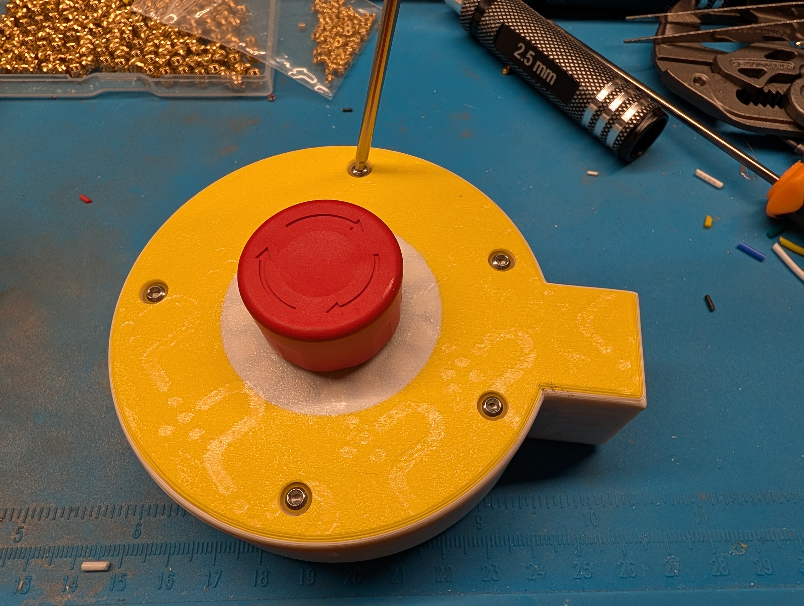
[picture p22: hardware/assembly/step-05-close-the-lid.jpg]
Lid screwed down with the 2.5 mm hex driver


Fold the wires into the base so the lid does not pinch them, seat the
lid, and drive the M3 screws into the inserts with the 2.5 mm hex driver.
Snug is enough; the inserts strip before the screws do.

## 6. Commission

Connect USB and flash; a fresh board enters download mode on its own.
(If automatic flashing does not work, hold BOOT and tap RST to force
download mode.) Everything after the first flash goes over the network.
See the [quickstart](../docs/QUICKSTART.md) for the flash and
machine-pairing steps, then calibrate the ring rotation:
`POST /api/ring_led1?on=1` lights the pixel the firmware currently calls
LED 1, and `POST /api/ring_offset?n=0..15` moves it to where the bezel
says LED 1 should be ([API reference](../docs/API.md)).

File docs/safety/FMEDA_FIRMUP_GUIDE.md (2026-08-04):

<!-- SPDX-FileCopyrightText: 2026 Polymath Robotics, Inc. -->
<!-- SPDX-License-Identifier: Apache-2.0 -->

# Firming Up the pstop FMEDA Without Manufacturer Failure-Rate Data

> **How to read this document.** It is dense with functional-safety acronyms and
> symbols. Every acronym is spelled out at first use, and there is a full reference at
> the end: **Appendix A** (acronym glossary with explanations), **Appendix B** (symbols
> and notation), and **Appendix C** (the harder concepts in plain language). If a term
> is unfamiliar, jump to the appendix — each entry is a few sentences, not just a
> definition.

**Purpose.** A **Failure Modes, Effects and Diagnostic Analysis (FMEDA)** is the
component-by-component spreadsheet that predicts how often a safety device fails, and in
which direction (safe vs dangerous). Our current one (`docs/safety/FMEDA.md`) reports a
**Safe Failure Fraction (SFF)** of ≈ 93 %, a dangerous-failure frequency
(**Probability of dangerous Failure per Hour, PFH**) of ≈ 3.7 × 10⁻⁹ per hour, and a
**common-cause failure fraction (β, "beta")** of 10 % — enough to claim **Safety
Integrity Level 3 (SIL 3)** but "met but fragile," and built on **assumed** component
numbers. This guide is the playbook for turning those assumptions into an
**assessor-defensible** FMEDA when you **cannot get component makers to supply
failure-rate (λ, "lambda") data** — Espressif publishes no **Failures-In-Time (FIT,
failures per 10⁹ hours)** or **Mean Time Between Failures (MTBF)** for the ESP32-S3
microcontroller, and most relay and passive-component vendors won't give a
dangerous-failure breakdown.

It was produced from two **IEC 61508** advisor passes (data-sourcing +
method/defensibility). *IEC 61508* is the International Electrotechnical Commission's
umbrella standard for the functional safety of electrical/electronic safety systems.
The guide is tailored to the pstop architecture: **Remote** = a dual-core ESP32-S3
reading a 2-channel **emergency-stop (E-stop)** loop through its **General-Purpose
Input/Output (GPIO)** pins; **Machine** = an ESP32-S3 microcontroller (**MCU**) driving
two **series** safety relays with feedback. The voting architecture is **one-out-of-two
with diagnostics (1oo2D)** and the **Hardware Fault Tolerance (HFT)** is 1 (it survives
one hardware fault), in **high/continuous demand** (the safety function is in constant
use — see Appendix C).

> **Honesty up front.** Everything below is *generic / handbook-derived*. None of it
> substitutes for vendor qualification data. The defensible position is **not** "we
> found the real numbers" — it is "we used a *named, dated, condition-matched,
> conservatively-adjusted, sensitivity-tested* number and can audit every one." A
> certification body / assessor (for example **TÜV**, the German technical-inspection
> association; **exida** or **Sira**, functional-safety certifiers) accepts handbook
> rates on exactly those terms.

---

## 0. The two things an assessor actually checks

1. **Random hardware failure ≠ systematic failure.** Generic rates and this FMEDA
   address only *random hardware* failure — parts wearing out or failing by chance
   (the architectural-constraint and PFH gates below). They do **nothing** for
   **Systematic Capability level 3 (SC 3)** — freedom from design/software mistakes,
   which is proved separately (the "Route 1S/2S/3S" systematic routes of IEC 61508-2,
   and IEC 61508-3 for software; see Appendix C). Keep them apart; a good FMEDA must not
   be allowed to *imply* systematic compliance.
2. **Two independent hardware gates, both must pass.** (a) **Architectural
   constraints** — the Safe Failure Fraction and Hardware Fault Tolerance together cap
   the achievable SIL (IEC 61508-2 §7.4.4, Tables 2 & 3). (b) **Quantified target** —
   the PFH must fall in the SIL-3 band (IEC 61508-2 §7.4.5). For pstop these are
   *different* tests: **our PFH is strong; our exposure is the SFF architectural gate**
   (see §2).

---

## 1. The firm-up playbook (do these in order)

1. **Freeze the FMEDA component list** — every part in the safety path (both ESP32-S3
   dies, the GPIO loop network, both series relays + feedback, power conditioning,
   oscillators).
2. **Pick one primary rate source and cite its edition** (recommendation in §3). Use a
   *consistent family* of sources; justify any per-part deviation.
3. **For each component**: base failure rate λ → **failure-mode split** (what fraction
   of failures are safe vs dangerous) → apply **π-factors** (pi-factors — the
   stress-adjustment multipliers that scale a rate to your real operating conditions,
   §4) → **Diagnostic Coverage (DC)** decides how much of the dangerous rate is detected
   (DD) vs undetected (DU) (§5).
4. **Relays**: run the **ISO 13849 B10d / MTTFd** route (§6) — the machinery-standard
   wear-out calculation — as an independent cross-check on the constant-rate relay
   numbers; set the replacement/proof-test interval from it.
5. **Common-cause fraction β via IEC 61508-6 Annex D** — a completed scoring
   questionnaire, with no phantom diversity credit (§7).
6. **Build the Assumptions Register** (§8) — the central defensibility artifact; one
   row per rate.
7. **Sensitivity analysis** (§9) — show the SFF stays ≥ 90 % (for the complex "Type B"
   channel) and the PFH stays < 10⁻⁷ per hour across the handbook uncertainty band
   (×3 to ×10).
8. **Add field evidence** where you can (§10) — "prior-use / proven-in-use" data to move
   from *assumed* toward *demonstrated*.
9. **Self-audit against the assessor checklist** (§11) before submission.

---

## 2. Architecture & metric — where pstop is strong vs fragile

Every element is classified **Type A** (simple — all failure modes well understood, with
field data) or **Type B** (complex — contains something whose failure behaviour isn't
fully known; any microcontroller is Type B). The SFF and HFT then cap the SIL via
IEC 61508-2 Tables 2 & 3 ("Route 1H", the hardware route). See Appendix C for Type A/B.

| Element | Type | HFT | SFF band needed to license SIL 3 |
|---|---|---|---|
| ESP32-S3 (Remote cores, Machine MCU) | **B** (complex) | 1 | **SFF 90–<99 %** (Table 3) |
| Series relays + feedback | **A** (well-defined modes, field data) | 1 | **SFF 60–<90 %** (Table 2) |

**Consequence.** The ESP32-S3 is **Type B**, so at HFT = 1 you need **SFF ≥ 90 %** to
license SIL 3 — and the current 93 % sits *just* inside that band. That boundary is the
whole "fragile": if an assessor reclassifies even one failure mode you called
Dangerous-Detected (DD) as Dangerous-Undetected (DU), the SFF can drop below 90 % and
demote the Type-B channel to SIL 2. **Protecting the 90 % boundary is priority #1.**
Argue the **relays as Type A explicitly** (well-known modes, field data, defined fault
behaviour) — they then only need SFF 60–<90 %, a far more comfortable margin.

**Demand mode = high/continuous → the metric is PFH.** An operator can hit the E-stop at
any moment, so demand is not below once per year and not tied to the proof-test schedule
(IEC 61508-4 §3.5.16 defines the modes). Therefore:

- Target band: **SIL 3 continuous = PFH between 10⁻⁸ and 10⁻⁷ per hour** (IEC 61508-1
  Table 3). Our 3.7 × 10⁻⁹ per hour is comfortably inside — **the quantitative gate is
  not the problem.**
- **The proof-test interval T1 barely helps in high demand.** In the low-demand metric
  (average Probability of Failure on Demand, **PFDavg**), T1 scales the dominant
  ½·λ_DU·T1 term; in the high-demand metric (PFH) the residual is **β·λ_DU** — a *rate*
  that is almost independent of T1. So don't lean on "proof-test more often" to rescue
  PFH — lean on **β** and on converting **DU → DD** with diagnostics.

**The 1oo2D high-demand approximation you must internalise (IEC 61508-6 Annex B.3.3):**

```
PFH_1oo2D  ≈  2·(1−β)²·λ_DU²·t_CE   +   β·λ_DU
                (negligible)              (dominant)
```

Here **λ_DU** is the dangerous-undetected failure rate per channel, **β** the
common-cause fraction, and **t_CE** the "channel-equivalent down-time" (a small
mean-outage term — see Appendix B). For realistic λ_DU the squared term vanishes and
**PFH ≈ β·λ_DU**. Everything that decides "SIL 3 by a comfortable margin vs by a
whisker" is (a) how small **λ_DU** is (→ diagnostics) and (b) how small and defensible
**β** is. This is the strategic heart of the whole exercise.

---

## 3. Where to get failure rates without a vendor (data sources)

These are recognized reliability-prediction handbooks and databases you can cite in
place of vendor data. Each entry names what it is best used for and its known bias.

| Source | Edition | Use it for | Bias / pedigree |
|---|---|---|---|
| **Siemens Norm SN 29500** (used with **IEC 61709:2017**) | 29500-1/-2/-4/-5; 61709 Ed. 3 | **Primary base rates** for the ESP32-S3 die + passive parts; the π-factor conversion engine | Tool-supported, well-structured; **optimistic** (rates read low). Reference conditions: 40 °C, sheltered (environment class C of IEC 60654-1). |
| **exida Safety Equipment Reliability Handbook (SERH), 4th ed.** + the SILStat field-data program | 4th | **Relays + the safe/dangerous split** — its numbers are *already* broken into the four safety buckets (λ_SD/λ_SU/λ_DD/λ_DU) in FMEDA form | Functional-safety pedigree (built for de-energize-to-trip logic). The same device can vary ~10× depending on data method — record which data set and duty you used. |
| **Quanterion Failure Mode/Mechanism Distributions (FMD-2016)** | 2016 | **Failure-mode distributions** — the safe-vs-dangerous apportionment (e.g. what fraction of relay failures are contact weld) | Empirical field data; the go-to source when a handbook gives a total rate but no mode split. |
| **FIDES Guide 2009/2022** (published in France as **UTE C 80-811**) | 2009/2022 | **Mobile-robot / rugged-environment** penalty (mission profile, thermal cycling, a process-quality factor Π_Process of 0.5–4) | Physics-of-failure + lifecycle model; more representative than SN 29500's "sheltered" reference for a moving vehicle. |
| **US Military Handbook 217F, Notice 2 (MIL-HDBK-217F N2)** | 1995 | **Environment π-factors** — the clean, citable Ground-Benign→Ground-Mobile ("G_B → G_M") mobility penalty; connector/relay/PCB models | Frozen since 1995, **pessimistic** for silicon (fine for a conservative safety argument); officially discouraged for new integrated-circuit work. |
| **Quanterion Nonelectronic Parts Reliability Data (NPRD-2016)** | 2016 | Field rates for **electromechanical/mechanical** parts (relays, connectors, switches) | Field data across ground/airborne/naval environments. |
| **Telcordia SR-332 Issue 4** | 2016 | Alternative electronic base rates; can blend lab + field data | Telecom-lineage, optimistic for harsh environments. |

**Recommended sourcing strategy for pstop:** use SN 29500 (with IEC 61709) for the
ESP32-S3 electronics; overlay FIDES / MIL-HDBK-217F Ground-Mobile factors to justify the
mobile penalty; use exida SERH + FMD-2016 for the relays and the dangerous-mode split;
cross-check the relays with ISO 13849 B10d (§6). Cite editions everywhere; never write
"industry typical."

---

## 4. Applying π-factors — the worked conversion (do this for every dominant line)

A **π-factor** (pi-factor) is a multiplier that adjusts a handbook's base failure rate
(quoted at some standard "reference condition") to your real operating condition —
temperature, electrical stress, environment, part quality, etc.

```
λ_operating = λ_ref × π_T × π_U × π_E × π_Q × π_(other)
   λ_ref = base rate at the handbook's reference condition
   π_T = temperature factor,  π_U = voltage,  π_E = environment,  π_Q = quality

Temperature factor uses the Arrhenius law (failure rate rises exponentially with heat):
  π_T = exp[ (E_a / k) · (1/T_ref − 1/T_op) ]
   E_a = activation energy (eV), material/mechanism-specific
   k   = Boltzmann's constant = 8.617×10⁻⁵ eV/K
   T_ref, T_op = reference and operating temperature, in kelvin
   Typical E_a: a complex integrated circuit ≈ 0.3–0.7 eV; passive parts ≈ 0.1–0.15 eV
```

**Worked example — the ESP32-S3 die (this is why "SIL 3 met" looks fragile):**

| Factor | Value | Basis |
|---|---|---|
| λ_ref | 60 FIT @ 40 °C | SN 29500-2 die model (assumed) |
| π_T (temperature) | **≈ 6.45** | E_a = 0.4 eV, operating 85 °C vs reference 40 °C |
| π_E (environment) | ≈ 3 | mobile (MIL-HDBK-217F Ground-Benign→Ground-Mobile) — not sheltered |
| π_Q (quality) | ≈ 2 | commercial-grade part, not automotive-qualified (AEC-Q100) |
| **λ applied** | **≈ 2320 FIT** | 60 × 6.45 × 3 × 2 |

The 40× jump from 60 to ~2320 FIT is exactly the trap: an FMEDA that quietly uses
*reference-condition* rates reads "SIL 3" but collapses under honest operating
conditions. Two legitimate levers pull it back down: **run the die cooler** (every
10–15 °C roughly halves π_T) and **diagnostics** (move that rate into the
dangerous-*detected* bucket λ_DD, where it barely touches PFH). **Show this conversion
explicitly in the FMEDA for every dominant line** — undocumented reference-condition
rates are the single most common generic-rate finding by assessors.

---

## 5. Diagnostic Coverage without vendor data — claim it from IEC 61508

**Diagnostic Coverage (DC)** is the fraction of a component's *dangerous* failures that
an on-line self-test detects (and reacts to) before they can cause harm. A "diagnostic"
here is any automatic check the system runs on itself (see Appendix C). You do **not**
need vendor DC numbers — the standard lets you claim DC from its own catalogue of
techniques, then justify it with your FMEDA reasoning.

- **Three tiers:** Low = 60 %, Medium = 90 %, High = 99 % (IEC 61508-2).
- **Where the maximum claimable DC lives:** **IEC 61508-2 Annex A** tables list, per
  element type (processing unit, program/data memory, input/output, program-sequence
  /watchdog monitoring, clock, sensors, final elements), the highest DC you may claim
  for each technique. **IEC 61508-7 Annex A** describes each technique and its
  effectiveness. **IEC 61508-2 Annex C** is the normative calculation:
  **DC = Σλ_DD / Σλ_D** and **SFF = (Σλ_S + Σλ_DD) / (Σλ_S + Σλ_D)** (Σ = "sum of"; λ_S
  = safe rate, λ_D = total dangerous rate). A worked example is in IEC 61508-6 Annex C.
  *(Verify the exact Annex A table numbering against your licensed 2010 edition before
  citing a specific "Table A.n" — the element-type→table mapping is what you cite.)*

**pstop diagnostics → defensible DC claims:**

| Diagnostic (already in the design) | Technique | DC claim | Justification / cap |
|---|---|---|---|
| Both-phase 2-channel E-stop sampling | redundant-input cross-monitor | **90 %**; 99 % only if dynamically pulse-tested | catches single-channel stuck, cross-short, short-to-supply |
| Dual-core compare (Remote) | reciprocal comparison by software | **90 %** | identical cores → **no** common-cause / shared-clock credit; do not claim 99 % |
| **Relay feedback readback** (Machine) | output / final-element monitoring | **99 % if force-guided (mechanically-linked) contacts, else 90 %** | this is what converts the relay-weld dangerous rate λ_D into detected λ_DD; weld detection needs the mirror contact mechanically forced (see Appendix C) |
| Heartbeat / windowed watchdog | program-sequence, temporal + logical | simple = **60 %**; **windowed + logical + independent timebase = 90 %** | a bare "kick the watchdog" only catches gross hangs |
| GPIO pad re-verify (requirement SR-R-09) | input/output readback / plausibility | **60–90 %** | catches a stuck driver; no common-cause credit for drive + sense sharing one die |
| Clock cross-check (requirement SR-H-04b) | clock monitoring | **90 %**; High only with a *truly independent* 2nd oscillator | checking against the same crystal is weak; against the independent tick / external watchdog timebase it is Medium-High |

Rules assessors apply — bake them in: **identical redundancy caps DC at Medium (90 %)
and pushes the residual into β**; a diagnostic only counts if it acts **within the
process safety time (PST)** and forces the safe state (document the diagnostic test
interval and the fault reaction). Then split **λ_DD = DC·λ_D** and
**λ_DU = (1−DC)·λ_D** — the sum of λ_DU across the design drives PFH.

---

## 6. Relays — the ISO 13849 B10d cross-check (relays wear out; a constant rate hides it)

ISO 13849 is the machinery functional-safety standard. Because relay contacts wear with
use, a constant-failure-rate model under-represents them; ISO 13849 models wear-out from
a cycle count instead.

```
n_op   = (d_op · h_op · 3600) / t_cycle      operations per year
   d_op    = operating days per year
   h_op    = operating hours per day
   t_cycle = seconds between demands
MTTFd  = B10d / (0.1 · n_op)                 Mean Time To dangerous Failure, in years (cap 100)
   B10d = cycles at which 10 % of samples have failed DANGEROUSLY
If only B10 is known (10 % failed by ANY mode), ISO 13849-1 permits B10d = 2·B10
   (i.e. assume half of failures are dangerous)
```

**Mean Time To dangerous Failure (MTTFd)** bands: Low 3–<10 years · Medium 10–<30 years
· High 30–100 years. Typical **B10d**: a power relay/contactor ≈ 1.3–2 × 10⁶ cycles; a
signal relay up to ~2 × 10⁷ (de-rate hard near the contact's rated load).
**Worked:** switch every 60 s, 16 h/day, 300 days/yr, B10d = 2 × 10⁶ →
n_op = 288 000/yr → MTTFd = 2 × 10⁶ / (0.1 × 288 000) = **69 years (High).**

**But an E-stop relay is usually *idle*, not cycling** — so **weld/stiction/corrosion
wear-out**, not cycle count, governs. A relay that never operates can weld silently;
the **feedback readback + a periodic forced test** is what keeps λ_DU bounded. ISO
13849-1 Annex E gives "cross-monitoring + feedback of relays" a DC of **99 %**, which
corroborates the §5 relay-feedback claim. **Reconcile the two routes:** if the B10d
calculation yields a much worse number than the constant-rate route, the constant-rate
number is hiding wear-out — trust B10d and set the **replacement interval** from it.

---

## 7. Common-cause failure fraction β via IEC 61508-6 Annex D — no phantom diversity

A **common-cause failure (CCF)** is one root cause that takes out both redundant
channels at once (a shared power glitch, a shared firmware bug, a shared thermal event).
**β ("beta")** is the fraction of a channel's failures that are common-cause — and, per
§2, in a 1oo2D high-demand system it dominates PFH.

IEC 61508-6 Annex D is a **scored questionnaire** (~37 items grouped as: separation,
diversity, complexity, assessment, procedures, competence, environmental control +
testing). Each "yes" adds an **X** score (the part whose effectiveness is *improved by
diagnostics*, amplified by a "Z" factor tied to DC and diagnostic interval) and a **Y**
score (diagnostic-independent). The total **S** is looked up in **Table D.4 → β**; a
separate score **S_D → β_D** gives the smaller common-cause fraction for *detected*
failures. *(The Table D.4 score→β cut-offs are proprietary — reproduce them from a
licensed copy of the standard.)*

**Defending pstop's β:**

- **Two identical ESP32-S3 cores running identical firmware = the textbook
  low-diversity, high-CCF case.** You earn **little or no diversity credit** — identical
  cores fail together under the same transient, clock glitch, thermal excursion, or
  firmware defect. **Do not claim diversity you don't have**; an assessor strikes it and
  then distrusts the whole register. **Hold β = 10 % on the cores** — that is the
  method's conservative default ceiling and is essentially unimpeachable.
- **Where you *can* lower β legitimately** (these load the X term, and they are real on
  our design): separation (independent power rails; physical/thermal separation of the
  two relays and their drive), strong on-line diagnostics (lockstep compare, watchdogs,
  relay readback), and documented electromagnetic-compatibility (EMC) and thermal
  qualification.
- **Highest-leverage engineering change available:** because **PFH ≈ β·λ_DU**, the
  single biggest win is **relay diversity** — if the two series relays are *different
  types / manufacturers*, you can argue **β = 5 %** (or lower) on the dominant
  final-element channel with a completed Annex D worksheet, roughly halving PFH. Two
  identical relays → hold β = 10 % there too. Always compute **β_D separately** (it feeds
  the detected-failure terms in the 1oo2D formula).

**Deliverable:** the completed Annex D questionnaire — item-by-item evidence, the X/Y
sums, the Z input, and the Table D.4 lookup — attached to the FMEDA. β must never appear
as a bare "10 %" with no worksheet behind it.

---

## 8. The Assumptions Register — the central defensibility artifact

One row per generic rate. This is the document that turns "we used a database number"
into an auditable strength:

| # | Field | Why the assessor needs it |
|---|---|---|
| 1 | Component / failure mode | trace to the FMEDA line |
| 2 | λ used | the number entering the roll-up |
| 3 | **Source + edition/version + table/page** | e.g. "SN 29500-2:2010 Tbl x"; "exida SERH 4th"; "FMD-2016" — named & dated, never "typical" |
| 4 | Source reference conditions | the temperature (θ_ref), duty, stress and quality the base rate assumes |
| 5 | **π-factors applied** | π_T / π_E / π_Q / … each with its value + the clause/equation defining it |
| 6 | Applied conditions | your actual operating temperature (θ_op), environment class (e.g. Ground-Mobile), duty — matched to (4) |
| 7 | Failure-mode-split source | where the safe/dangerous ratio came from (FMD-2016 / the source's own split) |
| 8 | Rationale | one line: why this source applies to this part |
| 9 | **Conservatism note** | *which direction is it pessimistic, and by how much* (e.g. "θ 85 °C assumed vs 60 °C measured → λ overstated ≈ 1.9×") |
| 10 | Sensitivity link | cross-reference to the §9 case that varies this λ |
| 11 | Owner / date / status | change control |

Rules that make it audit-ready: **every rate condition-matched** (a mismatched
reference condition is the #1 finding); **every rate conservative on the record**
(column 9 is your currency when you lack vendor data); **one consistent source family**
or a per-part justification; and **state the handbook uncertainty yourself** (IEC 61508-7
notes handbook rates carry a factor of ×3 to ×10) to pre-empt the assessor.

---

## 9. Uncertainty & conservatism — the load-bearing exhibit

Because handbook rates carry ×3-to-×10 uncertainty, no assessor accepts a single point
estimate that clears SIL 3 by only 5 %. **You must prove robustness:**

- **Sensitivity analysis.** Identify the dominant contributors (for a 1oo2D high-demand
  system: **β and the λ_DU of the relay channel**, per §2). Vary each **×3 and ×10**;
  move a claimed-DD mode to DU (DC 90 → 80 %); sweep β across its Annex D range; take
  the worst-case temperature. Present a table: for each perturbation recompute the
  **SFF (does it stay ≥ 90 % for the Type-B channel? ≥ 60 % for the Type-A relay?)** and
  the **PFH (does it stay < 10⁻⁷ per hour?)**. The claim you are proving is **"SIL 3
  holds across the credible uncertainty envelope,"** not "the nominal is 3.7 × 10⁻⁹." If
  SIL 3 breaks under a ×3 rate or a DC→80 % move, fix it *before* submission (relay
  diversity, better diagnostics, a cooler die).
- **Conservative rounding:** round λ_DU **up**, DC and SFF **down**, β **up**; take the
  upper end of any range; use the worst-case temperature (max ambient + self-heat).
  Record every rounding in register column 9.
- **Bound the DU terms explicitly:** since PFH ≈ β·λ_DU, put an upper bound on the sum of
  λ_DU and show that β · λ_DU(upper) is still < 10⁻⁷ per hour. A bounded worst case that
  passes beats a precise nominal.

---

## 10. From *assumed* toward *demonstrated* — prior-use / proven-in-use

Generic rates are an assumption; the strongest FMEDA adds field evidence. "Proven-in-use"
(IEC 61508-2 §7.4.10) is the standard's route for crediting an accumulated operating
history in place of, or alongside, predicted rates.

- **Requirements:** a documented, stable operating history; an **unchanged
  design/firmware** over the window (any change resets the clock); an operating
  environment that matches the target; and **field failures systematically recorded and
  classified safe/dangerous** — a real fault-reporting system, not anecdote.
- **How much:** the assessor expects the accumulated device-hour count to statistically
  support the target at a stated confidence — a common benchmark is **> 10⁷ device-hours
  (~1000 device-years)** across a sufficient installed base (**≥ ~100 units**) with a
  dangerous-failure record consistent with the claimed λ.
- **How hours become a rate (a chi-squared, χ², upper confidence bound — *not* a naïve
  failures ÷ hours):**
  `λ_a = χ²(a; 2k+2) / (2T)`, where **k** = number of dangerous failures observed,
  **T** = accumulated device-hours, and **a** = the confidence level. With **k = 0**
  failures this reduces to `λ = −ln(1−a) / T`. Assessors expect a = 70–90 %.
  **Zero failures does not mean λ = 0** — it is an upper bound *only if T is large
  enough*; low/zero counts on thin exposure are worthless.
- **Combine:** carry the **more conservative** of {handbook value, χ²-field bound} into
  the FMEDA. Showing that the field bound is *no worse* than the generic assumption is
  powerful corroboration.
- **pstop opportunity:** the fleet already logs check-ins. Instrument it to accumulate
  **per-unit operating hours + a classified fault log** now — that is how, in a year, you
  convert the relay/MCU assumptions into a proven-in-use argument, and (via **Route 2H**,
  IEC 61508-2 §7.4.4.3 — the field-data route to Hardware Fault Tolerance) potentially
  sidestep the fragile Type-B SFF gate with field-reliability evidence.

---

## 11. Pre-submission self-audit (what a TÜV / exida / kenexis reviewer asks for)

(*kenexis* is another functional-safety engineering consultancy.)

**Architecture:** Type A/B decided per block and justified (ESP32-S3 = B, relays = A) ·
HFT + voting + the compliance Route (1H/2H) declared, with the exact Table 2/3 row that
licenses SIL 3 · demand mode determined (→ metric = PFH). **FMEDA:** a complete
component × failure-mode table, with mode splits sourced · every λ_DD backed by a named
diagnostic + its coverage + a test interval ≤ the process safety time · SFF, average
Diagnostic Coverage (DCavg) and PFH reproducible from the raw sheet · **no SFF padding
with "no-effect" failures**. **Generic-rate defensibility:** an Assumptions Register with
source + edition + reference conditions + π-factors shown for **every** rate · a single
source family or a per-part justification · reference conditions matched, worst-case
temperature used · handbook uncertainty acknowledged. **Common cause:** a completed Annex
D worksheet → β and β_D · no unearned diversity credit. **Robustness:** a sensitivity
table showing SFF ≥ 90 % and PFH < 10⁻⁷ per hour across λ×3/×10, DC decreasing, β
increasing · the dominant term (β·λ_DU) explicitly bounded. **Evidence & lifecycle:** any
prior-use data with the §7.4.10 conditions met and a χ² confidence stated · **Systematic
Capability demonstrated separately** (not conflated with the FMEDA) · a safety manual
stating the proof-test procedure, the Proof-Test Coverage (PTC), the proof-test interval
T1, the Mean Time To Restoration (MTTR), the assumed environment, and every condition of
safe use.

---

## 12. The pstop action list (in priority order)

1. **Protect the SFF-90 % boundary.** Re-examine every mode you called Dangerous-Detected
   on the ESP32-S3 channel; make sure each has a real diagnostic (§5) with a coverage
   you would defend under challenge. This is the fragile gate.
2. **Introduce relay diversity** (two *different* relay types/manufacturers) — the single
   highest-leverage change; it roughly halves PFH by licensing β < 10 % on the dominant
   channel (§7). If the relays are already diverse, document it and claim the credit.
3. **Build the Assumptions Register** (§8) with SN 29500 + exida SERH + FMD-2016 +
   FIDES/MIL-HDBK-217F sources, editions, π-factor conversions, and conservatism notes.
4. **Run and table the sensitivity analysis** (§9) — this is the exhibit that converts
   "fragile" into "robust across uncertainty."
5. **Complete the Annex D β worksheet** (§7) — kill any phantom diversity; hold β = 10 %
   on identical elements.
6. **Stand up the field-hours + classified-fault log** on the fleet now (§10) so
   proven-in-use becomes available in ~a year (and opens Route 2H as an escape from the
   Type-B SFF gate).
7. **Keep Systematic-Capability (SC 3) evidence separate** — the MISRA C coding standard,
   static analysis in Continuous Integration (CI), the unit + fault-injection tests, and
   the traceability this effort produced.

---

## Caveats carried from the advisor research (do not publish these unverified)

- The exact **IEC 61508-2 Annex A table titles/numbering (A.1–A.15)** — cite the
  element-type→table mapping, but confirm the specific "Table A.n" against a licensed
  2010 edition before quoting it.
- The **IEC 61508-6 Annex D Table D.4** score→β cut-offs and any device-hour-vs-SIL
  confidence tables are proprietary tabular content — populate from a licensed copy, not
  from secondary paraphrase.
- The 1oo2 / 1oo2D **Annex B formulas** are the widely-published forms; verify them
  term-by-term against your licensed Annex B (edition-specific t_CE / t_GE conventions
  vary) before quoting in a certification submission.
- The **FIT figures in §3–§4 are order-of-magnitude, generic**, from secondary sources
  (exida blog, automotive targets, FMD mode logic, standard reference conditions) —
  starting points to be replaced by sourced register entries, not final values.

---

# Appendix A — Acronym glossary

Grouped by theme; within each group, roughly in order of first appearance.

## Analysis methods & documents
- **FMEDA — Failure Modes, Effects and Diagnostic Analysis.** The core spreadsheet of
  this whole effort: list every component, every way it can fail, how often, whether the
  failure is safe or dangerous, and whether a diagnostic catches it. Everything else here
  feeds or checks the FMEDA.
- **FMEA — Failure Modes and Effects Analysis.** The qualitative predecessor of FMEDA
  (no diagnostic/quantitative columns); FMEDA = FMEA + failure rates + diagnostic
  coverage.
- **HARA — Hazard Analysis and Risk Assessment.** (Referenced elsewhere in the safety
  set.) Determines *what* SIL/PL a function must reach; the FMEDA then shows whether the
  hardware *achieves* it.

### Standards & bodies
- **IEC — International Electrotechnical Commission.** Publisher of IEC 61508, the base
  functional-safety standard. Its parts referenced here: -1 (general/SIL bands), -2
  (hardware, architectural constraints, proven-in-use), -3 (software), -4 (definitions),
  -6 (calculation formulas + Annex D β), -7 (technique catalogue + uncertainty).
- **ISO — International Organization for Standardization.** Publisher of ISO 13849, the
  machinery functional-safety standard, used here for the relay B10d/MTTFd cross-check.
- **SN — Siemens Norm.** A Siemens corporate standard; SN 29500 is the de-facto default
  source of component base failure rates.
- **UTE — Union Technique de l'Électricité.** French electrotechnical standards body; UTE
  C 80-811 is the French-standard designation of the FIDES Guide.
- **TR — Technical Report.** IEC/TR 62380 was a reliability-data report, now folded into
  IEC 61709.
- **TÜV — Technischer Überwachungsverein.** German technical-inspection organisation; a
  common functional-safety certification body ("an assessor").
- **exida / Sira / kenexis.** Functional-safety certification / consulting firms (proper
  names, not acronyms) — "the assessor" in this document.
- **SINTEF.** A Norwegian research institute; author of the PDS method and β-factor
  report cited for common-cause data.
- **PDS.** SINTEF's reliability-analysis method for computer-based safety systems (from
  the Norwegian *Pålitelighet av Datamaskinbaserte Sikkerhetssystemer*).
- **CALCE — Center for Advanced Life Cycle Engineering** (University of Maryland); cited
  for its assessment of the FIDES method.

### Integrity levels & architecture
- **SIL — Safety Integrity Level** (1–4). The required reliability of a safety function;
  SIL 3 is our target. Higher = more reliable = harder to prove.
- **PL — Performance Level** (a–e). The ISO 13849 machinery-standard equivalent of SIL;
  PL e ≈ SIL 3.
- **SC — Systematic Capability** (1–4). How well design/software mistakes were prevented
  — proved by *process* (reviews, testing, coding standards), separately from the
  FMEDA's random-hardware numbers. SC 3 is our target.
- **HFT — Hardware Fault Tolerance.** How many hardware faults the function survives and
  still performs. HFT = 1 means one fault is tolerated (we have two channels).
- **1oo2D — "one-out-of-two with diagnostics."** A voting architecture: either of two
  channels can command the safe state (so it fails safe easily), and on-line diagnostics
  detect a broken channel and remove it. The "D" is what makes it *1oo2D* rather than
  plain 1oo2.
- **Type A / Type B element.** A hardware classification: Type A = simple, all failure
  modes understood, field data exists (our relays); Type B = complex, contains something
  whose failure behaviour isn't fully known (any microcontroller). Type B needs a higher
  SFF for the same SIL — the root of our "fragile" gate. (See Appendix C.)
- **Route 1H / 2H.** The two hardware routes to satisfying architectural constraints in
  IEC 61508-2: 1H uses SFF+HFT tables; 2H uses field-reliability data with confidence
  bounds.
- **Route 1S / 2S / 3S.** The three routes to Systematic Capability (prior-use,
  compliant development, or proven-in-use of the element).

### Failure-rate & reliability metrics
- **λ (lambda) — failure rate.** How often a part fails; usually in FIT.
- **FIT — Failures In Time.** 1 FIT = 1 failure per 10⁹ device-hours. The working unit
  for λ.
- **MTBF — Mean Time Between Failures.** The reciprocal-style summary of λ; ~1/λ for
  repairable items. Espressif publishes neither FIT nor MTBF for the ESP32-S3.
- **λ_S, λ_DD, λ_DU, λ_D — the four safety buckets.** Safe; Dangerous-Detected;
  Dangerous-Undetected; and total Dangerous (λ_D = λ_DD + λ_DU). Also seen as **λ_SD /
  λ_SU** (safe-detected / safe-undetected). λ_DU is the killer term.
- **SFF — Safe Failure Fraction** = (λ_S + λ_DD) / (λ_S + λ_D). The fraction of failures
  that are either safe or caught by a diagnostic. Our fragile number (~93 %, needs
  ≥ 90 %).
- **DC — Diagnostic Coverage** = λ_DD / λ_D. The fraction of *dangerous* failures a
  diagnostic detects. **DCavg** is the λ-weighted average across an element.
- **PFH — Probability (average frequency) of dangerous Failure per Hour.** The
  high-demand target metric; SIL 3 = 10⁻⁸ to 10⁻⁷ per hour. Ours ≈ 3.7 × 10⁻⁹ (good).
- **PFDavg — average Probability of Failure on Demand.** The *low-demand* metric (not
  ours); scales with the proof-test interval T1.
- **β (beta) — common-cause failure fraction.** Fraction of failures that hit both
  channels from one root cause; **β_D** is the smaller value for *detected* failures.
  Dominates PFH here (PFH ≈ β·λ_DU).
- **CCF — Common-Cause Failure.** The failure β measures — one cause, both channels.
- **B10 / B10d.** Cycle counts at which 10 % of samples have failed (B10 = any mode;
  B10d = *dangerously*). The wear-out input for relays.
- **MTTFd — Mean Time To dangerous Failure** (years). Derived from B10d and the operating
  cycle count; banded Low/Medium/High in ISO 13849.
- **MTTR — Mean Time To Restoration** (a.k.a. repair time); **MRT — Mean Repair Time.**
  How long a detected fault stays present; feeds the small t_CE/t_GE outage terms.
- **PST — Process Safety Time.** The maximum time the system may take to reach the safe
  state after a fault/demand; a diagnostic only counts if it reacts within the PST.
- **PTC — Proof-Test Coverage.** The fraction of dangerous-undetected failures a manual
  proof test actually reveals (rarely 100 %).
- **T1 — proof-test interval.** How often the manual proof test runs.

### Data sources
- **SERH — Safety Equipment Reliability Handbook** (exida). Failure rates already split
  into the four safety buckets.
- **FMD — Failure Mode/Mechanism Distributions** (Quanterion FMD-2016). The safe/dangerous
  *mode split* source.
- **NPRD / EPRD — Nonelectronic / Electronic Parts Reliability Data** (Quanterion). Field
  failure rates for mechanical/electromechanical and electronic parts respectively.
- **FIDES.** A French aerospace/defence reliability-prediction guide (physics-of-failure +
  lifecycle); strong for mobile/rugged use. (Name evokes Latin *fides*, "trust"; not a
  strict acronym.)
- **MIL-HDBK-217F — US Military Handbook 217F.** The venerable, pessimistic prediction
  handbook; used here mainly for environment factors.
- **G_B / G_M — Ground-Benign / Ground-Mobile.** MIL-HDBK-217 environment classes; the
  G_B→G_M ratio is a citable "mobile vehicle" penalty.

### Components & engineering
- **ESP32-S3.** The Espressif dual-core microcontroller used for both the Remote and the
  Machine.
- **MCU — Microcontroller Unit.**
- **IC — Integrated Circuit.**
- **PCB — Printed Circuit Board.**
- **GPIO — General-Purpose Input/Output.** The microcontroller pins that read the E-stop
  loop.
- **E-stop — Emergency stop / protective stop.** The safety function itself.
- **EMC — Electromagnetic Compatibility.** Immunity to electrical interference; a
  documented EMC qualification earns common-cause (β) credit.
- **AEC-Q100.** The Automotive Electronics Council's stress-qualification standard for
  ICs; a "commercial-grade" (non-AEC-Q100) part carries a higher quality π-factor.
- **ASIL — Automotive Safety Integrity Level.** The automotive (ISO 26262) analogue of
  SIL; cited only for reference FIT targets.
- **MISRA — Motor Industry Software Reliability Association.** Its C coding standard is
  part of our Systematic-Capability evidence.
- **CI — Continuous Integration.** Automated build/test on every change; hosts the static
  analysis that supports SC 3.
- **SR-R-09 / SR-H-04b.** Internal pstop safety-requirement IDs (Remote GPIO re-verify;
  machine-side clock guard).

---

# Appendix B — Symbols & notation

| Symbol | Read as | Meaning |
|---|---|---|
| **λ** | "lambda" | Failure rate (failures per hour, usually in FIT). |
| **λ_S, λ_DD, λ_DU, λ_D** | lambda-S / -D-D / -D-U / -D | Safe / Dangerous-Detected / Dangerous-Undetected / total-Dangerous failure rate. |
| **β** | "beta" | Common-cause failure fraction (0–1); **β_D** = the value for detected failures. |
| **π** | "pi" | A stress-adjustment multiplier. **π_T** temperature, **π_U** voltage, **π_E** environment, **π_Q** quality, **π_S** switching, **π_L** load; **Π_Process** = FIDES development-quality factor. |
| **Σ** | "sigma" / "sum of" | Summation over all components (e.g. Σλ_DU = total dangerous-undetected rate). |
| **θ** | "theta" | Temperature. **θ_ref** = handbook reference temp; **θ_op** = your operating temp. |
| **E_a** | "E-sub-a" | Activation energy (electron-volts, eV) in the Arrhenius temperature model. |
| **k** | — | Boltzmann's constant, 8.617 × 10⁻⁵ eV/K (in the Arrhenius term). *Separately*, **k** also denotes the *number of observed failures* in the §10 chi-squared formula — context distinguishes them. |
| **T** | — | In §10, accumulated device-hours. *Separately*, **T1** = the proof-test interval. |
| **t_CE, t_GE** | — | "Channel-equivalent" and "group-equivalent" down-time: small mean-outage terms (from λ_DU, λ_DD, MTTR/MRT and T1) in the IEC 61508-6 Annex B formulas. |
| **n_op** | — | Relay operations per year (ISO 13849 B10d route). |
| **χ²** | "chi-squared" | A statistical distribution; used to turn observed failures + device-hours into an upper-confidence-bound failure rate. |
| **≈ / × / →** | approximately / times / leads-to | e.g. "PFH ≈ β·λ_DU"; "×3" = a factor of three; "DU → DD" = converting undetected to detected. |
| **10⁻⁷ /h** | ten-to-the-minus-seven per hour | A frequency; the SIL-3 PFH ceiling in high demand is 10⁻⁷ per hour. |

---

# Appendix C — Key concepts in plain language

- **Random vs systematic failure.** *Random* = physical parts failing by chance or
  wear (what the FMEDA and failure rates cover). *Systematic* = a design or software
  mistake that is baked in and would recur (covered by process, not by rates). The
  standard demands both be handled, by *separate* arguments; a strong FMEDA says nothing
  about systematic quality.

- **The two hardware gates.** To claim SIL 3 the hardware must pass **two** independent
  tests: (1) **architectural constraints** — a table lookup on SFF and HFT that *caps*
  the SIL your architecture is *allowed* to claim; and (2) the **quantified target** —
  the computed PFH must land in the SIL-3 band. You can ace one and fail the other. For
  pstop, the PFH is comfortably good, but the architectural gate (needing SFF ≥ 90 % on
  the complex Type-B microcontroller channel) is what sits on a knife-edge.

- **Type A vs Type B.** A "simple" element (Type A) has fully understood failure modes
  and field history — you're allowed to reach a given SIL at a *lower* SFF. A "complex"
  element (Type B) — anything with a microcontroller — could fail in ways nobody has
  characterised, so the standard demands a *higher* SFF for the same SIL. That extra
  demand is the whole reason our SFF margin is "fragile."

- **Demand mode (low vs high/continuous).** *Low demand* = the safety function is called
  on rarely (< once/year), so what matters is the chance it is broken *when finally
  asked* (PFDavg). *High/continuous demand* = it is effectively always working, so what
  matters is the *rate* at which it fails dangerously (PFH). An E-stop can be pressed any
  time → high/continuous → PFH, and the proof-test interval barely moves PFH.

- **Safe vs dangerous failure; detected vs undetected.** A *safe* failure drives the
  system to its safe state (relays open, robot stops) — a nuisance, not a hazard. A
  *dangerous* failure could leave the system running when it should stop. A dangerous
  failure is *detected* if an automatic diagnostic notices it and forces the safe state
  in time; otherwise it is *undetected* — and undetected dangerous failures (λ_DU) are
  what actually cause accidents. Nearly every lever in this guide is about shrinking
  λ_DU.

- **Diagnostic.** Any automatic self-check the system runs while operating — comparing
  the two cores, reading the relay feedback contact, a watchdog timer, re-reading a pin's
  configuration. Diagnostic *Coverage* is how much of the dangerous failure rate those
  checks catch. A diagnostic only counts if it also *reacts* (forces the safe state)
  within the process safety time.

- **Proof test.** A *manual*, periodic test (unlike a diagnostic, which is automatic and
  continuous) that reveals dangerous-undetected failures that have accumulated — e.g.
  physically exercising a relay to confirm it still opens. Its "coverage" (PTC) is rarely
  100 %.

- **Common cause (β).** Redundancy only helps if the two channels fail *independently*.
  A common cause — one shared power rail, one firmware bug, one hot enclosure — defeats
  redundancy by taking out both at once. β is the fraction of failures that do this, and
  in a redundant high-demand system it becomes the dominant term of PFH. **Diversity**
  (making the two channels genuinely different) is the main way to lower β; claiming
  diversity you don't actually have (two identical chips) is the classic assessor
  red flag.

- **Reference conditions & π-factors.** A handbook quotes a base failure rate at some
  standard "reference" temperature/stress/environment. Your part runs hotter, in a
  moving vehicle, at commercial grade — all of which raise the true rate. π-factors are
  the multipliers that convert the reference rate to your condition (the worked example
  in §4 shows a 60 FIT reference becoming ~2320 FIT applied). Using reference numbers
  without this conversion is the single most common way an FMEDA silently overstates
  SIL.

- **Force-guided (mechanically-linked) relay contacts.** A relay whose monitor contact
  is *mechanically tied* to the main contact, so if the main contact welds shut, the
  monitor contact is physically prevented from indicating "open." This is what lets the
  feedback readback *reliably* detect a welded relay (a dangerous failure) and claim
  99 % diagnostic coverage; without mechanical linkage the monitor can lie and the claim
  drops to 90 %.

- **Proven-in-use / prior-use.** Crediting a large accumulated field history (many units
  × long time, with a real failure-logging system) as evidence the failure rate is at
  least as good as claimed — a way to back up, or replace, a predicted number with
  measured reality. Only valid while the design is unchanged and the environment matches.

- **Sensitivity analysis.** Deliberately re-running the numbers with each dominant input
  made worse (rate ×3 or ×10, coverage lower, β higher, hotter) to prove the SIL claim
  survives the uncertainty rather than depending on optimistic point values. It is the
  exhibit that turns "SIL 3, barely" into "SIL 3, robustly."

- **"Assessor" and "defensible."** The assessor is the third-party reviewer (TÜV/exida/
  Sira/kenexis) who decides whether to certify. "Defensible" means every number is
  traceable to a named, dated source, condition-matched, deliberately conservative, and
  shown to survive uncertainty — the standard this whole guide is written to meet.

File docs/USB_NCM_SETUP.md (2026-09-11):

<!--
SPDX-FileCopyrightText: 2026 Polymath Robotics
SPDX-License-Identifier: CC-BY-4.0
-->

# USB-NCM tether — host setup

This is the one-time host setup for operating a pstop remote over its USB
cable (the "USB-NCM tether"). USB-NCM is the recommended transport for
**bench work and field service** — no LAN, no WiFi credentials, no Tailscale
round-trip — and it is the third automatic uplink after Ethernet and WiFi.
Firmware stability of the tether itself is characterized separately in
[`USB_NCM_STABILITY.md`](USB_NCM_STABILITY.md); this guide is only about
preparing the host.

## Why a host setup is needed at all

Plugging a pstop into a host does **not** give you a working link out of the
box, and the failure mode is misleading: the host's new "wired" connection
sits in *connecting…* forever while the unit silently falls back to its
provisioned WiFi.

By design the chip's USB-NCM interface runs **no DHCP server**. The chip
presents itself as a standard USB CDC-NCM network adapter and expects the
**host** to own the link — assign itself an address, serve DHCP to the chip,
and NAT the chip's traffic onward. Once the host does that:

- the host takes **`10.42.0.1`**,
- the chip DHCPs an address in **`10.42.0.0/24`** (typically `10.42.0.x`),
- the chip switches its active uplink to USB, and
- once pointed at the host (`POST /api/pstop_peer?ip=10.42.0.1&port=8890`),
  it bonds to a `machine_app_runner` there. A fresh unit has no peer.

The chip enumerates with USB **VID:PID `303a:4001`** in application mode
(`303a:1001` is ROM download mode — a different device, ignored by the naming
rule below).

The subnet matters only for the peer address you configure: a host setup that
hands out a *different* subnet (notably Windows ICS, see below) needs the
matching `POST /api/pstop_peer?ip=<host-ip>&port=8890`.

---

## Linux — verified

**Easiest: run the installer.** It auto-detects the host's network manager
(NetworkManager *or* systemd-networkd) and installs the matching variant,
plus the manager-agnostic interface-naming rule:

```sh
host/setup/install.sh
```

Replug the unit afterward so the `esp-pstop0` rename takes effect. The manual
steps for each manager, if you prefer them:

### NetworkManager

**1. Pin every pstop to one predictable interface name (`esp-pstop0`).**
Keyed on the USB VID:PID so it holds across units and across reboots, and
sorts before the default `73-usb-net-by-mac.link` (first match wins), so the
interface is never the per-unit `enx<mac>` name:

```sh
sudo cp host/setup/70-esp-pstop.link /etc/systemd/network/
sudo udevadm control --reload
```

**2. Bind a shared-mode NetworkManager profile to that name.** `shared` mode
is what makes NetworkManager assign `10.42.0.1`, start a dnsmasq DHCP server,
and NAT the link outward:

```sh
sudo nmcli con add type ethernet ifname esp-pstop0 con-name esp-pstop \
     ipv4.method shared connection.autoconnect yes
```

Replug the unit. Within a few seconds the host takes `10.42.0.1`, the chip
DHCPs `10.42.0.x`, and its active uplink switches to USB.

### systemd-networkd (no NetworkManager)

Hosts running systemd-networkd (common on HIL / fleet hosts) need the
`nmcli`-free equivalent — a NetworkManager "shared" profile has no effect
there. Install the `70-esp-pstop.link` naming rule as above, then:

```sh
sudo cp host/setup/80-esp-pstop.network /etc/systemd/network/
sudo cp host/setup/esp-pstop-flush-networkd /etc/networkd-dispatcher/routable.d/esp-pstop-flush
sudo cp host/setup/esp-pstop-flush-networkd /etc/networkd-dispatcher/degraded.d/esp-pstop-flush
sudo chmod +x /etc/networkd-dispatcher/routable.d/esp-pstop-flush \
              /etc/networkd-dispatcher/degraded.d/esp-pstop-flush
sudo systemctl enable --now networkd-dispatcher   # GOTCHA below
sudo networkctl reload
```

`80-esp-pstop.network` gives the host `10.42.0.1/24`, runs the built-in DHCP
server, and NATs the link out (`ConfigureWithoutCarrier=yes`, so it is ready
before the chip even enumerates). **Gotcha:** the `networkd-dispatcher`
package is often *installed but its service disabled* — then the neighbor-cache
flush hook never fires and the tether can need a manual `ip neigh flush` or a
power-cycle after a re-enumeration; the `systemctl enable --now` above fixes
it (or replace the dispatcher hook with a udev-triggered oneshot to drop the
dependency). Verified on a systemd-networkd HIL host 2026-08-08: the tether
self-heals unattended across the chip's re-enumerations (interface, neighbor
table, DHCP lease, ping, and HTTP all recover).

**Caveat (both managers):** only the *first* unit plugged in gets
`esp-pstop0`; simultaneous extra units fall back to `enx<mac>` names and each
needs its own profile/match.

Background on why the naming rule (not just a MAC-keyed profile) is required
is in [`USB_NCM_STABILITY.md`](USB_NCM_STABILITY.md).

---

## Windows — notes (similar idea, not bench-verified here)

The concept is identical — the host must own the link and serve DHCP — but
the mechanism differs.

- **Driver:** Windows 10 (1809+) and Windows 11 bind the chip to the built-in
  USB NCM class driver automatically; it appears as an ordinary Ethernet
  adapter. No vendor driver is needed. On older Windows a CDC-NCM/RNDIS
  driver may have to be supplied.
- **Serving the link:** enable **Internet Connection Sharing (ICS)** on an
  Internet-facing adapter and share it *to* the pstop adapter. ICS then runs
  a DHCP server and NATs the link.
- **Subnet gotcha:** ICS hands out **`192.168.137.0/24`** with the host at
  `192.168.137.1` — **not** `10.42.0.1`. Either point the chip at that address
  (`POST /api/pstop_peer?ip=192.168.137.1&port=8890`) or change the ICS
  subnet to `10.42.0.0/24` via the registry
  (`HKLM\SYSTEM\CurrentControlSet\Services\SharedAccess\Parameters`,
  `ScopeAddress` / `ScopeAddressBackup`) and restart the service.
- **Static alternative:** instead of ICS, give the pstop adapter a static
  `10.42.0.1/24` and run any small DHCP server bound to it. The chip needs a
  DHCP lease; it will not self-assign.
- Reach the admin UI at the chip's leased address, or configure the machine
  runner to listen on the host's tether address.

## macOS — notes (similar idea, not bench-verified here)

- **Driver:** macOS binds CDC-NCM natively; the pstop shows up as a network
  service (often "USB 10/100/1000 LAN" or similar) in *System Settings →
  Network*.
- **Serving the link:** *System Settings → General → Sharing → Internet
  Sharing*, share your internet connection **to** the pstop's USB network
  service. macOS Internet Sharing runs `bootpd` (DHCP) and NATs the link.
- **Subnet gotcha:** macOS Internet Sharing also defaults to a
  `192.168.x.0/24` range, not `10.42.0.1`. As on Windows, either point the
  chip's peer at the host's address with `POST /api/pstop_peer?...` or override the `bootpd` scope
  (`/etc/bootpd.plist`) to `10.42.0.0/24`.
- **Static alternative:** manually set the pstop network service to
  `10.42.0.1/255.255.255.0` and run a DHCP server (e.g. `dnsmasq` from
  Homebrew) bound to that interface. The chip still needs a lease.

---

## Verify (any host)

```sh
# host has the tether address
ip addr show esp-pstop0            # Linux: expect 10.42.0.1/24
# chip answers on its leased address (Linux shared mode → 10.42.0.x)
CHIP=$(ip neigh show dev esp-pstop0 | awk '/10\.42\.0\./{print $1; exit}')
curl -s "http://$CHIP/state.json" | grep -o '"active_iface":[0-9]'      # expect 2 = USB-NCM
```

On the chip, `state.json` reports `active_iface` (`2` = USB-NCM) and
`usbncm_en`/`usb_ip`. A healthy tether shows the active uplink on USB and,
if a `machine_app_runner` is listening at the host's tether address, a bonded
machine session.

If the link comes up but never bonds, check that the chip's configured peer
(`pstop_machines[0]` in `state.json`) matches the address the host actually
took on the tether, and that a machine process is listening there.

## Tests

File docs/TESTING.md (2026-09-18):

# Testing

How to exercise the pstop link, the machine's arming policy, and the
remote's robustness. Nothing here needs the chip's IDE. Bench IPs are
environment-specific — every script takes them as environment variables or
flags.

Most tools here are stdlib-only and run under any Python 3.11+. The
`tools/` uv environment covers all of them plus the ones with dependencies
(`usb_relay4.py`, the HIL suite), so the commands below use `uv run`; see
[`../tools/README.md`](../tools/README.md) for the one-time setup.

## 1. Machine arming-policy suite — `tools/pstop_test_remote.py`

A scripted pstop remote that speaks the real v2 wire protocol (48-byte
messages, CRC16 poly 0x8D95, far-Hamming codewords, self-role in the aux
channel) well enough to bond and run timed STOP/OK sequences — verifies the
min-STOP-duration arming policy and the two-gate re-arm rule without a chip.
It works against either machine implementation, since both host the same
`pstop_c`. Use a **dedicated** port, never the one a real remote is bonded to.

Plain-C runner (`host/machine.toml` admits every remote; the script announces
OPERATOR, which is all that arming needs):

```sh
cd host && make
./machine_app_runner machine.toml 8893 &
cd ../tools && uv run python pstop_test_remote.py --port 8893
```

ROS 2 node (defaults admit every remote; only the port needs overriding):

```sh
printf '/machine_bridge:\n  ros__parameters:\n    software:\n      port: 8894\n' > /tmp/pstop_test.yaml
ros2 run protective_stop_machine machine_bridge_node --ros-args --params-file /tmp/pstop_test.yaml &
cd tools && uv run python pstop_test_remote.py --port 8894
```

Asserts (exit 0 = all pass):
1. bond + OK stream → machine replies STOP (NEED_STOP, nothing armed yet)
2. 200 ms STOP blip → immediate OK refused; a steady OK stream arms once the
   library's min delay has elapsed
3. 800 ms STOP press → ARMS on release (replies turn OK)
4. blip while armed → robot stops; immediate OK refused; self-re-arms after
   the delay
5. press again → re-arms

`--role stop_only` announces a stop-only remote instead and asserts the
inverse: a full press-and-release must **not** arm. Run both after any change
to `host/machine_app_runner.c`, `ros2/`, `common/pstop_aux_channel.h` or a
`pstop_c` update (a CRC/wire break fails at step 1).

## 1b. Many-remotes-to-one-machine matrix — `tools/pstop_multi_remote_test.py`

Drives N scripted software remotes (each its own device_id + counter handshake)
against a dedicated `machine_app_runner` to validate the many-to-one logic
across the corner-case matrix: independent arming, the any-STOP OR, arming
ownership, heartbeat loss, unbond, capacity overflow, admission allow/denylist
(incl. the addressed `UNBOND` reply and deny-wins), remote-announced stop-only
vs operator authority, the LIVE role flip (a demoted owner keeps the machine
running but cannot re-arm it after the next STOP), a mixed operator/stop-only
fleet, malformed/bad-CRC/invalid-type traffic, and network chaos (via §2).
47 assertions covering the fail-safe invariants (I1–I7).

```sh
cd tools && uv run python pstop_multi_remote_test.py     # exit 0 = all invariants held
```

Full write-up + invariant list: `MULTI_REMOTE_VALIDATION_2026-07-22.md`.

## 2. Protocol-level impairment — `tools/pstop_chaos_proxy.py`

UDP proxy interposed in the pstop path
(chip → proxy:8891 → machine:8890) that injects loss / delay / jitter
(reordering) / duplication / corruption per direction, re-tunable at
runtime via a UDP control port (8892) without re-bonding:

```sh
cd tools && uv run python pstop_chaos_proxy.py --listen 8891 --fwd 8890 --ctrl 8892
curl -X POST "http://$CHIP/api/pstop_peer?ip=<proxy-host>&port=8891"
echo 'loss=0.05 delay_ms=100 jitter_ms=50' > /dev/udp/127.0.0.1/8892
echo 'clear=1'                             > /dev/udp/127.0.0.1/8892
```

Direction-specific overrides: `loss_up` (chip→machine), `loss_down`,
same suffixes for `delay_ms`/`jitter_ms`/`dup`/`corrupt`. Stats print
every 10 s.

## 3. Chaos ladder — `test/chaos_ladder.sh`

Sweeps the proxy through the standard impairment ladder (baseline,
loss 1→30 %, delay 50→500 ms, jitter-reorder, dup, corrupt, combo, then
0.5/1/2/5 s full outages) while sampling the chip's `/state.json` every
10 s. Requires the proxy from §2 running and the machine ARMED (any
unscheduled STOP in the logs = false trip).

```sh
CHIP=<chip-ip> [CTRL_HOST=127.0.0.1] [CTRL_PORT=8892] test/chaos_ladder.sh
```

Outputs (next to the script): `chaos.csv` (phase-stamped samples),
`phases.log` (phase markers); machine transitions land in the runner's
stderr, proxy stats in its stdout.

Pass criteria (measured baseline, 2026-07-20): zero false STOPs, zero
rebonds, zero crashes (`boot_count` stays 0) through the entire ladder
up to 30 %/direction loss + 500 ms delay + 20 % dup + 2 % corruption;
outages <1 s ride through; outages ≥1 s STOP on the heartbeat timeout
and re-bond automatically, with arming requiring a fresh press.

## 4. WG-underlay ladder — `test/netem_ladder.sh`

tc/netem on the *encrypted* WireGuard flows (UDP 51820) of the bench
interface — validates the tunnel layer itself: loss, delay, a 5-min
direct-path blackhole (must fail over to DERP), restore (must return to
the direct path). Self-installing and self-verifying: it logs netem
qdisc packet counters per phase to PROVE impairment applied, because the
tether interface silently loses all qdiscs on every chip reboot /
USB re-enumeration.

```sh
IF=<bench-iface> CHIP=<chip-ip> CHIP_TS=<chip-tailscale-ip> test/netem_ladder.sh
```

Needs sudo (tc/ifb). NOTE: the script's `arm()` step uses the
`/api/pstop_sim` pulse, which exists only in test builds — on production
firmware (pstop_sim removed) it 404s harmlessly; arm with a physical
press of the E-stop switch instead.

Baselines (2026-07-20/21): 10 %/dir underlay loss → ~19 % reply loss, no
false STOP; blackhole → STOP on timeout, heartbeats resume via DERP at
~201 ms RTT; dark window ≤10 s with the priority-peer pong watchdog
(measured 9.3 s; was 10–66 s); direct path back within one sample of
restore.

## 5. Soak methodology

A transport claim needs, per transport (Ethernet / USB-NCM / WiFi):

1. **30–40 min steady-state soak** at the commissioned heartbeat rate over
   Tailscale, machine armed. Include the fastest supported rate as a stress
   case. Watch `/state.json`: `pstop_sent`/`pstop_replies` ratio,
   `pstop_rebonds`, `pstop_mismatch`, `boot_count`, `heap_min_int`.
2. The §3 protocol ladder and §4 underlay ladder.
3. A wire-level audit: tcpdump the underlay and confirm no plaintext
   application ports (this is what caught the critical plaintext
   downgrade — see `archive/CHAOS_RESULTS_2026-07-20.md`).

Measured baselines to compare against
(`archive/TRANSPORT_TEST_REPORT_2026-07-20.md`):

| Metric | USB-NCM | Ethernet (PoE) | WiFi (PS off) |
|---|---|---|---|
| Soak reply rate | 99.983 % | 100.000 % | 98.09 % |
| Rebonds / false stops | 0 / 0 | 0 / 0 | ~1 burst per 10–15 min (fail-safe) |
| Steady-state pstop RTT over tunnel | ~5 ms | ~5 ms | tens of ms, spiky |
| Crashes over the whole campaign | 0 | 0 | 0 |

Long-run harnesses in `tools/` (edit the IP constants at the top —
they are bench snapshots): `tools/chaos_soak.py` (reachability +
telemetry probe at 2 s with injected chaos events; reboot-gated so it
never trips the rapid-boot ladder) and `tools/robust_test.py` (repeated
reboot: Tailscale-up time, crash-free boots, admin-page latency).

## 6. Legacy scripts

`test/longsoak.sh`, `test/test_suite.sh`, `test/full_test_after_recovery.sh`,
`test/aggressive_ota.sh`, `test/auto_recover.sh` are v15-era bench
scripts kept for reference; they predate the current firmware and still
assume old bench addresses/flows. Prefer the tools above.

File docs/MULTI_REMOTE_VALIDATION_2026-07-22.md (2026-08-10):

# Many-Remotes-to-One-Machine Validation (2026-07-22)

> **[Reconciled 2026-08-02]** The heartbeat-timeout formula below is corrected to
> the library math `heartbeat_ms × max_missed_heartbeats` (`machine.c:290-298`);
> it previously read `× (max_missed_heartbeats + 1)`. Full register:
> `docs/safety/RECONCILIATION.md` (R-07).

Validates the pstop_c machine logic when **multiple remotes** heartbeat one
machine, across the corner cases a fleet actually hits. Two-part (hybrid):
exhaustive software remotes for coverage, plus the two real chips end-to-end
over the real transport.

## The logic under test (pstop_c, unmodified)

`machine.c` implements a **fail-safe OR**: the robot runs (OK) only while
*every* bonded remote is OK **and** no arming cycle is pending. Any of the
following drives STOP:

- a remote sends STOP,
- a remote goes silent past `heartbeat_ms x max_missed_heartbeats` (`machine.c:290-298`),
- a remote unbonds (disconnect),
- a remote sends a malformed / bad-CRC / invalid-type message (rejected; its
  heartbeat is not fed, so it times out to STOP),
- the machine reaches capacity and rejects a new remote.

**Arming ownership**: the first non-`stop_only` remote to STOP owns the
STOP->OK re-arm cycle (`remote_stop_id`). A *different* remote can STOP the
robot but cannot itself re-arm — the owner must, or the owner must
unbond/time-out first (which releases ownership). Fail-safe: it is only ever
*harder* to arm. `stop_only` operators may STOP but never arm.

## Safety invariants asserted (all held)

| # | Invariant |
|---|---|
| I1 | any bonded remote sending STOP -> every remote sees STOP |
| I2 | a remote silent > timeout -> robot STOP |
| I3 | robot never OK without a deliberate held STOP->OK cycle |
| I4 | a STOP shorter than `min_stop_ms` (500 ms) cannot arm |
| I5 | a freshly (re)bonded remote forces re-arm (NEED_STOP) |
| I6 | the `(max_remotes+1)`th remote is rejected; armed peers undisturbed |
| I7 | unbonding the arming owner drops the robot to STOP/NEED_STOP |

## Part 1 — software-remote corner-case matrix  (32/32 PASS)

`tools/pstop_multi_remote_test.py` — spins up `host/machine_app_runner`
(linking the unmodified library) and drives it with N scripted remotes that
speak the real 40-byte wire protocol (CRC16 0x8D95), each with its own
device_id + counter handshake. Groups:

- **A** single-remote arming policy (arm / veto / re-arm)
- **B** two-remote arming + any-STOP OR + ownership
- **C** heartbeat loss (network drop / power-off) + re-arm on reconnect
- **D** unbond / disconnect (owner leaves, ownership release, last-remote)
- **E** capacity overflow (`max_remotes=3`), allowlist deny, `stop_only`
- **F** malformed: UNKNOWN, sustained bad-CRC, out-of-range type
- **G** network chaos via `tools/pstop_chaos_proxy.py` (loss/delay/jitter/dup):
  arm through proxy, heavy loss -> STOP, recovery -> re-arm, churn never
  spuriously arms.

Run: `python3 tools/pstop_multi_remote_test.py` (exit 0 = all invariants held).

## Part 2 — real two-chip end-to-end

Both flashed chips against one `machine_app_runner` on the laptop
(`machine.toml`: max_remotes=3, max_missed=1, min_stop_ms=500, allow_unlisted):

- `pstop-01d778b4` (0x01D778B4) — new chip, USB-NCM tether (10.42.0.1:8890)
- `pstop-01d7791c` (0x01D7791C) — old chip, Tailscale (100.110.35.58:8890)

Observed on the machine:

```
P1 near-simultaneous OK  -> ANOMALY: arming VETOED from 0x01D778B4 (100ms < 500ms)   [I4]
P2 NEW held STOP 1200ms -> OK -> ARMED by 0x01D778B4; Robot Status = OK
P3 OLD STOP while armed  -> Robot Status = STOP                                       [I1]
P6 both released to STOP -> disarmed; both chips pstop_last_msg=1 (STOP)              fail-safe
```

Confirms bond, arm, and the any-STOP OR work end-to-end with real hardware over
both transports.

## Test-only software E-stop stub (added, used, REMOVED)

The remotes have no physical E-stop switch wired, so they always read STOP and
cannot exercise the OK/arming path. A **gated** software override was added
ONLY for this test:

- `CONFIG_DCS_ESTOP_SW_STUB` (Kconfig, **default n**), forcing a build `#warning`.
- `POST /api/estop_stub?state=ok|stop|clear` overriding `compute_verdict()`
  (fail-safe default = passthrough to the real hardware read).
- Every piece tagged `TODO(SAFETY): REMOVE before certification`.

**Safety compliance**: a protective-stop verdict must derive ONLY from the
dual-channel hardware loop. The stub deliberately bypasses that cross-check, so
it was **fully reverted after testing** — the code is gone from the tree
(`git` clean), both chips were restored to clean `b19a754`, and the
`/api/estop_stub` endpoint now 404s on both. It was never committed or shipped.

To reproduce the stub for future bench work, re-add the gated option (never
enable it in a production/certified build) — see git history of this doc's
session, or the pattern above.

## Findings

No unsafe behavior. All STOP/timeout/reject paths are fail-safe. Observations
(all safe-by-design):

- Arming ownership sticks to the first arming remote until it unbonds or times
  out; a second remote can STOP but not re-arm. Intended, fail-safe.
- UNKNOWN and out-of-range message types are rejected (not fed to the heartbeat)
  -> STOP arrives via timeout, not instantly. Same effect as silence.
- httpd user-handler budget (`dcs_support.c max_user_uri_handlers=16`) was at
  its limit; adding one more handler (the stub) silently failed to register
  until bumped. Worth watching if more `/api` routes are ever added in prod.
  **[Reconciled 2026-08-07]** Raised to `max_user_uri_handlers=30` (46 total
  slots for microlink's ~20 + dcs's 21); comment in `dcs_support.c` documents
  the arithmetic to re-check on any new route. No longer at the limit.

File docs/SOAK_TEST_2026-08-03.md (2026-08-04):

<!-- SPDX-FileCopyrightText: 2026 Polymath Robotics, Inc. -->
<!-- SPDX-License-Identifier: Apache-2.0 -->

# 6-Hour Fleet Soak — Final Verification (2026-08-03)

**Verdict: PASS.** Over 6 h 11 m, all reachable units ran the same clean committed
build with **zero reboots, zero crashes, zero safety faults, zero heap leaks, and
zero unreachability**. The single logged anomaly was one transient control-plane
reconnect during startup settling, self-healed in seconds.

## Setup

- **Firmware:** all units OTA-updated to `95a948b` (a clean, committed, non-dirty
  build — replacing a prior mix of `f4daf48-dirty` / `1cfbd9a` / `3dcd08d`).
  `95a948b` also adds the `ml_reconnects` telemetry field (see below).
- **Units under test** (the reachable fleet; 6 other units were offline):

  | Unit | ID | Role in soak | Path |
  |---|---|---|---|
  | machn-01d77a1c | `0x01d77a1c` | machine (drives 2 series relays) | Ethernet |
  | PSTOP54 | `0x01d7eed0` | remote — **live safety link to machn** | USB-NCM |
  | PSTOP42 | `0x01d7ed38` | remote — control-plane/network soak | USB-NCM |
  | DUT | `0x01d7f344` | remote — **DERP-relayed** control-plane soak | DERP relay |

- **Window:** 2026-08-03 00:43:37 → 06:54:10 (6 h 11 m monitored; units up
  ~6 h 15 m continuous). Poll interval 30 s → **716 samples/unit, 2864 total.**
  (Monitoring ran in two windows — the host killed the first background task at
  4 h 44 m — but the units ran continuously the whole time and self-track cumulative
  counters, so coverage is complete. A ~5 min fine-grained polling gap at 05:27 has
  no reboot/fault in the surrounding cumulative counters.)
- **Machine state:** fail-safe STOP (unarmed) throughout — the safety *link* is
  soaked (heartbeats + status streaming + replies), not the energized-RUN path
  (which would need a continuously-driven arming gesture).

## Results (all 716 samples/unit)

| Signal | machn | PSTOP54 | PSTOP42 | DUT |
|---|---|---|---|---|
| Reboots (uptime regression) | 0 | 0 | 0 | 0 |
| Fault resets (PANIC/WDT/brownout) during soak | 0 | 0 | 0 | 0 |
| Lockstep mismatch | 0 | 0 | 0 | 0 |
| Dual-core clock xcheck fault | 0 | 0 | 0 | 0 |
| GPIO pad-config fault (SR-R-09) | 0 | 0 | 0 | 0 |
| Relay faults / spurious STOP | 0 | 0 | 0 | 0 |
| Heap leak | none | none | none | none |
| Unreachable samples | 0/716 | 0/716 | 0/716 | 0/716 |
| Control-plane reconnects (`ml_reconnects`) | 2 | 0 | 0 | 0 |
| WiFi/internet disconnects | 0 | 0 | 0 | 0 |

- **No restarts:** every unit's uptime climbed monotonically to ~6 h 15 m;
  `reset_reason` was `3` (SW — the initial OTA boot) for all, with no fault code.
- **Heap stable:** machn 8019k→8020k; PSTOP54 7917k→7918k (min dip 7852k, recovered);
  PSTOP42 7918k→7921k; DUT 7917k→7920k. No downward trend on any unit.
- **DERP path held:** the DERP-relayed DUT stayed `ml_state=CONNECTED` for all 716
  samples — historically the flakiest path, solid here.

### The live safety link (PSTOP54 ↔ machn)

- **`bonded=1` on every one of 716 machn samples** — the bond never dropped.
- **110,817 status messages sent, 110,687 replies — a 99.88 % reply rate over 6 h.**
- Rebonds: 13 → 32 (**+19 total**). ~10 of those were a single settling burst in the
  first 14 min (right after four near-simultaneous OTA reboots); the remaining ~9
  were sporadic over 6 h (≈ 1 per 40 min), each a brief self-healing re-bond that
  never caused a STOP, a mismatch, or a lost bond. `pstop_send_fail` 11 → 20 (+9).
- `wg_dedup_drops` climbed on the USB-NCM units (harmless — dropping duplicate
  WireGuard packets that arrive via both direct and relay paths).

### The one logged anomaly

`00:49:17 machn: ml_state=3 (RECONNECTING)` — a single transient during startup
settling, recovered within seconds; it is one of machn's 2 `ml_reconnects`. Both
machn reconnects landed by 00:57; **zero reconnects in the following ~6 h.**

## Notes

- **`ml_reconnects` (new this build) earned its place:** it caught machn's 2
  control-plane reconnects, which self-recovered between 30 s polls and would
  otherwise have been invisible. `0` on all three remotes = the control plane never
  flapped for them.
- **`rst_hist` historical entries are pre-soak:** PSTOP42's ring buffer contains
  older `6` (TASK_WDT) entries and PSTOP54 older `11` (USB) entries — these predate
  this firmware and this soak (leftover from bench flashing / USB re-enumeration).
  No unit incurred a watchdog or fault reset *during* the 6 h.
- **Monitor correction:** an early false-positive ("machn link stale") came from
  applying remote-role semantics to the machine (`pstop_last_reply_ms` is an
  absolute boot-timestamp, and a machine sends rather than receives replies). The
  check was switched to a reply-counter-progress test; the device was never stale.

## Assessment

The fleet is stable for extended continuous operation on `95a948b`. No restarts,
no disconnects at the bond level, no safety faults, no resource leaks. The only
imperfection is a small rate of brief, self-healing re-bonds on the one active
wireless-tunnelled safety link (~1 per 40 min, 99.88 % reply rate) — worth keeping
an eye on but well within normal for a WireGuard/DERP-tunnelled link and never
consequential to the safety function.

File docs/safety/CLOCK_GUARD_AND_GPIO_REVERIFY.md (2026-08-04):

<!-- SPDX-FileCopyrightText: 2026 Polymath Robotics, Inc. -->
<!-- SPDX-License-Identifier: Apache-2.0 -->

# Machine clock-freeze guard (SR-H-04b / DU-2) + E-stop GPIO pad re-verify (SR-R-09 / DU-1)

**Branch:** `safety/clock-guard-gpio-reverify`
**Standard frame:** IEC 61508 (SIL 3 / PL e allocated). Safe state = **STOP =
de-energized**. Fail-safe reaction of every mechanism below is **STOP**.

This note closes the **two highest-priority Dangerous-Undetected rows** in
`docs/safety/FMEA.md` §3 — the two the FMEDA (`docs/safety/FMEDA.md` §7.4)
ranks #1 and #2 by PFH contribution:

| DU | Failure | Requirement | Mechanism added here | Validation |
|---|---|---|---|---|
| **DU-2** | Machine `get_time_cb` frozen/backward → heartbeat watchdog blind → dead remote looks alive | **SR-H-04b**, SR-I-03 | Host: independent-reference clock guard on `machine_now_ms`. machn: esp_timer-vs-FreeRTOS-tick sanity + watchdogs. | Host **fault-injection unit test** (pass); machn build-verified, HW validation deferred |
| **DU-1** | Lost E-stop pull-down → open loop floats → false-CLOSED → **false OK** | **SR-R-09** | Remote: ~1 s GPIO pad-config register read-back on both IN pins → latch → halt TX → STOP | **On-target fault injection** on `10.43.0.195` (OTA), reverted |

The remote-side **frozen-clock** DU-2 (the chip's own `esp_timer`) was already
closed by the dual-core cross-check documented in
`docs/WATCHDOG_CLOCK_PROTECTION.md`. This note adds the **machine-side** clock
term (host runner + `machn`) — the FMEDA's *dominant* λ_DU (MC-4, β≈1) — and the
remote **GPIO** term.

---

## Part A — SR-H-04b: machine-side clock-freeze guard (DU-2)

### A.1 Why it is dangerous

The machine's liveness watchdog is `pstop_c`'s `check_heartbeats`
(`pstop_c/.../machine.c:267-320`), driven entirely by the value returned from
`env.get_time_cb`. On the host runner that callback is `machine_now_ms()` reading
`CLOCK_MONOTONIC`. `check_heartbeats` computes `diff = now - last_timestamp` and
**skips the remote entirely when `now <= last_timestamp`** (machine.c:282). So if
`CLOCK_MONOTONIC` **freezes** or steps **backward**:

- every remote's `diff` is 0 (or the branch is skipped) → the timeout can never
  be reached → **a silent/dead remote is never STOPped** → the robot keeps
  running on a stale liveness case. Dangerous, and **undetected** — the clock is
  upstream of the entire verdict, and *you cannot detect your own clock's freeze
  by reading that same clock*. An independent reference is required (FMEA
  H03-1 / F-P-03).

### A.2 Host runner — `host/machine_app_runner.c` + `host/clock_guard.{c,h}`

A small, pure, unit-tested module (`clock_guard.c`) cross-checks the primary
clock against **three independent progress signals**:

- **`CLOCK_BOOTTIME`** — an independent monotonic reference (keeps advancing even
  if `CLOCK_MONOTONIC` is administratively slewed);
- **`CLOCK_REALTIME`** — a second independent reference (only *forward* motion
  counts as evidence, so an NTP step-back can never manufacture a false fault);
- **loop/call-count proxy** — the truly independent signal: the CPU keeps
  executing and the guard keeps being called even if **every** clock source is
  wedged. This is what catches the classic DU-2 (a `get_time_cb` stuck at a
  constant).

`machine_now_ms()` still returns `CLOCK_MONOTONIC` exactly as before (the library
sees no change), but every call also feeds the guard; the main loop additionally
polls it once per iteration. Detection rules (all in the pure module):

- **Backward** (`mono < highest-seen`) → latch `FAULT_BACKWARD` immediately.
- **Frozen** (`mono` not advancing) **and** an independent reference advanced
  past the **500 ms window** → latch `FAULT_FROZEN`. 500 ms is well under the
  ~2.0 s heartbeat timeout (`max_missed` = 5 since 2026-08-04; was ~1.2 s at 3),
  so a freeze is caught *before* it can mask a dead remote.
- **Frozen** and the **call-count backstop** (2000 stalled calls) is reached
  (all clocks wedged, only the loop advancing) → latch `FAULT_FROZEN`.

The fault is **sticky** (a clock fault is never un-seen). On any latched fault
the main loop **forces `machine_stop_robot()`** (STOP + `status_cb(STOP)`),
**refuses to process inbound traffic** (so no path can commit an OK), and holds
STOP; in a full deployment an external watchdog then restarts the host.

### A.3 machn (ESP32-S3 machine node) — `machn/main/main.c`

The machn's liveness runs on `esp_timer` via a **single latched** `g_tick_now_ms`
(FMEDA MC-4, β≈1 — the dominant term). The comparator now cross-checks
`esp_timer_get_time()` against `xTaskGetTickCount()` (a **different** time base):
a frozen or backward `esp_timer` while the scheduler still ticks → **force STOP**
(open both series relays + `machine_stop_robot` on both cores) → controlled
`esp_restart()` after a 500 ms STOP-settle. The full watchdog stack
(TWDT 5 s / IWDT 300 ms / bootloader-RTC) is enabled in `machn/sdkconfig.defaults`
and the comparator subscribes+feeds the TWDT — mirroring the remote
(`docs/WATCHDOG_CLOCK_PROTECTION.md`).

This is the direct machine-side analogue of the remote's dual-core clock
cross-check.

---

## Part B — SR-R-09: E-stop GPIO pad-config re-verification (DU-1)

### B.1 Why it is dangerous

The two E-stop IN pins (GPIO40 ch A, GPIO42 ch B) are configured **once** in
`estop_init()` as *input + pull-down ENABLED* (`firmware/main/main.c:215-222`), so
an **open** loop discharges through the pull-down and reads 0 → STOP. That config
was **never re-verified at runtime**. If the pull-down is lost (an SEU on the
IO_MUX config register, a stray pad reconfig, ESD), an open loop **floats** and
can echo 1 on the drive-high phase → **false CLOSED → false OK**, with no online
detection. This is **DU-1**, the FMEA's single most dangerous gap; the design doc
claimed a runtime "config-integrity check" that **never existed in code**
(RECONCILIATION R-02).

Option A (live both-phase sampling) does **not** help: it trusts the physical
read, and here the *sensor path physically lies*.

### B.2 Mechanism — `firmware/main/main.c`

Every **~1 s** the comparator reads back each IN pad's configuration registers
via `gpio_ll_get_io_config()` (ESP-IDF v5.5 `hal/gpio_ll.h`), which decodes the
same IO_MUX/GPIO registers `gpio_config()` wrote:

| Field | Register bit | Required | Meaning |
|---|---|---|---|
| `.pd` | IO_MUX `FUN_WPD` | **1** | pull-down enabled — **the DU-1 bit** |
| `.ie` | IO_MUX `FUN_IE` | **1** | input enabled (else the read is dead) |
| `.oe` | GPIO output-enable | **0** | input direction, not a driven output |
| `.pu` | IO_MUX `FUN_WPU` | **0** | no pull-up (a pull-*up* would actively hold an open loop CLOSED — worst case) |

Any mismatch **latches a sticky per-channel fault bit** (`g_gpio_cfg_fault`,
bit0 = ch A / GPIO40, bit1 = ch B / GPIO42). The comparator then fail-safes
**exactly like the clock cross-check**: it **halts all pstop TX**, so every
machine's heartbeat times out to **STOP**. There is **no auto-reset** — a lost
pull-down is a hardware fault a reboot would only *transiently* mask (because
`estop_init` re-enables it), so the device stays safely silent until serviced.
The state is exported to `/state.json` as `gpio_cfg_fault` for observability.

---

## Validation evidence

### V.1 Host clock guard — fault-injection unit test (Part A, host)

`make -C host test` builds and runs `host/test_clock_guard.c`, which injects
mock/stuck/backward clock triples into the pure detector:

```
clock_guard: 5117 checks, 0 failures
```

Cases asserted (each maps to an SR-H-04 clause):

- **Frozen monotonic + advancing reference** → `FAULT_FROZEN`, tripped within the
  ~500 ms window (the classic DU-2: `get_time_cb` stuck at a constant).
- **All clocks wedged, only the loop advancing** → `FAULT_FROZEN` via the
  call-count backstop.
- **Backward monotonic jump** → `FAULT_BACKWARD` immediately.
- **Healthy 5000-poll run incl. a REALTIME step-back** → never trips (no false
  positive).
- **Sticky latch** → a "recovered" clock still reports the fault.

The runner + guard build clean (`make -C host`) and a live smoke on **port 8896**
comes up with **no false clock fault**.

### V.2 Remote GPIO pad re-verify — on-target fault injection (Part B, `10.43.0.195`)

A **throwaway** build (never committed) cleared `FUN_WPD` on channel A's IN pad
(GPIO40) at runtime after ~20 s — simulating a lost pull-down — then reverted.
OTA-only, polling `/state.json` (`t0`=core-0 tick, `sent`=pstop TX count,
`rr`=reset_reason, `boot`=OTA boot-count):

```
t=21 up=32546 rr=3 boot=0 t0=194 gpio_cfg_fault=0 sent=0   healthy, ~1 s before injection
t=22 up=33597 rr=3 boot=0 t0=199 gpio_cfg_fault=1 sent=0   FUN_WPD cleared -> re-verify CAUGHT it
t=23 up=34635 rr=3 boot=0 t0=199 gpio_cfg_fault=1 sent=0   TX HALTED (core ticks frozen) = STOP, in reset grace
t=24 (no response — controlled reset firing)
t=25 (no response)
t=26 (no response)
t=27 up=9051  rr=3 boot=0 t0=0   gpio_cfg_fault=0 sent=0   back up: CLEAN SW reset (rr=3), boot=0, pad re-initialized
```

Proof points:

- **`gpio_cfg_fault` 0 → 1** the instant the pull-down was cleared — the re-verify
  detected the lost pull-down (the DU-1 signature) even though the loop was still
  *physically* closed (`e=11/11`): a config-integrity check, not a level check.
- **TX halted → STOP:** core ticks froze at 199 and `sent` stayed 0 — the
  comparator entered the fail-safe halt (every machine heartbeat-times-out).
- **Clean controlled reset:** the device returned with `reset_reason=3`
  (`ESP_RST_SW`) and `boot_count=0` — the intentional controlled reset, **not**
  the rollback-counted `ESP_RST_TASK_WDT`; on reboot `estop_init` re-wrote the
  pad and it ran healthy again (transient-SEU recovery).

**Injection reverted → clean build stable** (final committed firmware, no
injection): loops advance in lockstep, `gpio_cfg_fault=0`, `pstop_mismatch=0`, no
false fault, across a continuous run past the old injection point:

```
up=15632 t0=26  t1=26  gpio_cfg_fault=0 xfault=0 mm=0   loops in lockstep (t0==t1)
up=28110 t0=150 t1=150 gpio_cfg_fault=0 xfault=0 mm=0   past the old injection tick, no trip
up=55791 t0=427 t1=427 gpio_cfg_fault=0 xfault=0 mm=0   stable, no false fault
```

The re-verify runs every ~1 s (it re-reads the pads continuously) and does
**not** false-trip on a correctly-configured pad.

### V.3 machn clock guard — DEFERRED

`machn/main/main.c` builds clean (`machn_machine.bin`). On-hardware validation on
`100.84.155.111` is **deferred**: it is a **live machine node**, confirming the
STOP *actuation* needs relay HIL feedback, and a throwaway `esp_timer`-freeze
injection would induce a controlled-reset loop — not appropriate to flash onto a
live node without a bench. The logic is the direct analogue of the remote
dual-core cross-check that **is** fault-injection validated
(`docs/WATCHDOG_CLOCK_PROTECTION.md` §4). **Follow-up:** validate on a bench machn
with a 4-ch relay HIL (inject a frozen `esp_timer`, assert both relay drives go
low and the node controlled-resets).

---

## Requirement discharge

| Req | Before | After |
|---|---|---|
| **SR-H-04** (frozen/backward machine clock → STOP) | **Gap** | **Satisfied (host)** — clock guard + fault-injection unit test; machn analogue implemented (HW validation deferred) |
| **SR-I-03** (never-freezing `get_time_cb`) | Partially satisfied | Reinforced — freeze/backward now *detected*, not just assumed |
| **SR-R-09** (periodic GPIO pad re-verify → STOP on lost pull-down) | **Gap** (highest priority) | **Satisfied** — ~1 s read-back on both IN pins; on-target fault injection confirms trip → STOP; clean build stable |

FMEDA impact (`docs/safety/FMEDA.md` §7.4): closing DU-2 (rank 1) moves the
dominant ~3×10⁻⁹/h λ_DU term to λ_DD on the host; SR-R-09 (rank 2) moves the
DU-1 pull-down term. Both raise SFF toward the ≥ 99 % that gives unambiguous
SIL 3 with HFT margin. The machn term remains DU until its HW validation closes.

---

## Residual gaps

1. **machn HW validation** — code-complete + build-verified, on-target proof
   deferred (V.3). Until then the machine-side clock term stays DU on the machn.
2. **Genuine shared-clocksource freeze on the host.** `CLOCK_MONOTONIC`,
   `CLOCK_BOOTTIME`, and `CLOCK_REALTIME` all derive from one Linux clocksource;
   a dead clocksource freezes all three. The **call-count proxy** is the
   backstop for exactly that case, but it is best-effort — a true belt-and-braces
   solution is an **external hardware watchdog** on the host (already recommended
   in FMEA DU-2 / SR-H-04). Documented, not eliminated.
3. **DU-6 (both pull-downs lost together, common-cause).** SR-R-09 re-verifies
   *both* channels independently, so a common-cause loss is now *detected* — but
   a brownout detector wired to the safe state (SR-R-10) is still a separate open
   item for the sub-tick window before the next ~1 s re-verify.
4. **Re-verify latency.** The pad check runs at ~1 s cadence; a pull-down lost
   *and* an E-stop opened within the same ≤ 1 s window is covered by the machine
   heartbeat/PST budget (≤ 2.1 s, SR-SYS-01; `max_missed` = 5 since 2026-08-04) but the pad-fault itself is detected
   only at the next tick. Tightening the cadence trades CPU for latency; 1 s
   matches the design doc's claim and is well inside the PST.

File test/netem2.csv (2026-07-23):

epoch | phase | uptime_s | bc | sent | replies | send_fail | rtt_ms | rebonds | last_msg | path
1784664243 | n0-baseline | 611 | 0 | 5668 | 5667 | 0 | 103 | 0 | 1
1784664248 | n0-baseline | 616 | 0 | 5718 | 5717 | 0 | 104 | 0 | 1
1784664253 | n0-baseline | 621 | 0 | 5769 | 5768 | 0 | 107 | 0 | 1
1784664258 | n0-baseline | 626 | 0 | 5820 | 5819 | 0 | 102 | 0 | 1
1784664263 | n0-baseline | 632 | 0 | 5870 | 5869 | 0 | 102 | 0 | 1
1784664268 | n0-baseline | 637 | 0 | 5921 | 5920 | 0 | 102 | 0 | 1
1784664273 | n0-baseline | 642 | 0 | 5971 | 5970 | 0 | 102 | 0 | 1
1784664278 | n0-baseline | 647 | 0 | 6022 | 6021 | 0 | 102 | 0 | 1
1784664284 | n0-baseline | 652 | 0 | 6073 | 6072 | 0 | 103 | 0 | 1
1784664289 | n0-baseline | 657 | 0 | 6123 | 6122 | 0 | 103 | 0 | 1
1784664294 | n0-baseline | 662 | 0 | 6174 | 6173 | 0 | 102 | 0 | 1
1784664299 | n0-baseline | 667 | 0 | 6225 | 6224 | 0 | 103 | 0 | 1
1784664304 | n0-baseline | 672 | 0 | 6275 | 6274 | 0 | 103 | 0 | 1
1784664309 | n0-baseline | 677 | 0 | 6326 | 6325 | 0 | 103 | 0 | 1
1784664314 | n0-baseline | 682 | 0 | 6376 | 6375 | 0 | 102 | 0 | 1
1784664319 | n0-baseline | 687 | 0 | 6427 | 6426 | 0 | 137 | 0 | 1
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

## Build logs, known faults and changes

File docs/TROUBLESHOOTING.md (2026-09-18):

# Troubleshooting — pstop remote

Field guide for diagnosing a sick unit. Verified against the current
firmware (`firmware/main/main.c` + `firmware/components/dcs_support/`).
`$CHIP` below is the unit's IP on whatever interface is up — bench
addresses are environment-specific. `/state.json` and `/api/*` need no
auth; `/admin/*` uses HTTP basic auth (`admin` / `CONFIG_ML_ADMIN_PASSWORD`,
default `microlink`).

---

## First contact: the LED ring, then `/state.json`

The 16-LED WS2812 ring (IO17) shows the pstop link as seen from the
machine's replies:

| Ring | Meaning |
|---|---|
| WHITE | idle — no pstop peer (machine) configured; nothing to connect to (fresh unit, or peer cleared) |
| RED (slow pulse) | a peer IS configured but no fresh reply — never bonded, machine down/unreachable, or the comparator stopped after a lockstep fault. Distinct from a solid-red commanded STOP |
| BLUE | bonded, not armed — last reply was BOND/UNBOND |
| GREEN | armed — last reply OK, robot cleared to run |
| RED (solid) | STOP — commanded stop (switch pressed, or NEED_STOP arming cycle not yet completed) |
| PURPLE | lockstep MISMATCH — the two cores disagreed recently (e.g. ONE loop channel open/faulted). Takes priority over all other colours; held 2 s so single blips show |
| dim purple comet | boot sign-of-life, or an OTA image being flashed |

The onboard single LED (IO21) shows network state, not pstop state.

```sh
curl -s http://$CHIP/state.json | python3 -m json.tool
```

| Field | Healthy | If not |
|---|---|---|
| `ml_state` | **4** (CONNECTED) | 0–3 = Tailscale not up; check `ts_boot_en`, `wg_paused`, `derp_paused` |
| `boot_count` | **0** | 1 = last boot crashed (this boot is DERP-only); ≥2 = Tailscale paused this boot; >3 = rollback fires |
| `reset_reason` | 1 or 3 | 4/5/6/7 = crash-class, 11 = brownout — see table below |
| `rst_hist` | mostly 1/3 | ring of the 16 most recent reset reasons — repeated 4s/6s = crash pattern |
| `ota_state` | valid | pending-verify right after an OTA until finalize marks it |
| `active_iface` | 1 (eth) / 2 (usb) / 3 (wifi) | 0 = no uplink, 4 = SoftAP setup mode |
| `pstop_sent` / `pstop_replies` | grow together at the configured rate (5 Hz with the default 400 ms window) | replies lagging = path issue; `pstop_send_fail` climbing = chip can't TX (e.g. Tailscale peer while VPN down — fail-safe) |
| `pstop_mismatch` | **0** | climbing = the cores disagree — usually one loop channel open/shorted; ring shows purple |
| `pstop_rebonds` | 0 (rare 1s) | climbing = reply loss > ~2.0 s bursts (heartbeat_ms 400 × max_missed 5; was 1.2 s at max_missed 3) — link quality |
| `e_hi0`/`e_lo0`/`e_hi1`/`e_lo1` | all 1 | per-channel loop diagnostics: `hi=0` = loop open (press/broken wire), `lo=0` = sense stuck high |
| `heap_min_int` | ≥ 20–30 KiB | low-water internal heap; ~6 KiB lows only in USB-NCM mode |
| `wg_pbuf_fails` | 0 | lwIP couldn't alloc for a WG packet (silent drop) |
| `wg_dedup_drops` | climbs slowly | machine's tailscaled hedging direct + DERP simultaneously |
| `gw_rtt_ms` / `gw_ok` / `gw_loss` | 0–few ms / climbing / ~0 | the active uplink's own gateway ping (device-side link health) |
| `rssi` | −50…−75 dBm | below −80 = poor WiFi link, expect drops (0 when WiFi is off) |

## `reset_reason` codes

| Code | Name | Meaning | Look at |
|---|---|---|---|
| 1 | POWERON | Cold boot | nothing — normal |
| 3 | SW | Clean `esp_restart()` (OTA, admin restart, ladder auto-restart) | nothing — normal |
| 4 | PANIC | Stack overflow, hard fault, `abort()` (including a deliberate liveness abort — check the log) | `/api/last_log` |
| 5 | INT_WDT | Interrupts disabled too long | long critical sections |
| 6 | TASK_WDT | TWDT starved 5 s (`CONFIG_ESP_TASK_WDT_TIMEOUT_S=5`) | `/api/last_log`, task list |
| 11 | BROWNOUT | Supply dipped | power supply / cable (not counted toward rollback) |

`reset_reason` is sticky from the last boot. Reason 4 with
`boot_count = 0` means the 10 min age-out already cleared the counter —
the chip is currently healthy.

## Getting the crash log

Primary (remote, no cabling): `GET /api/last_log` serves a 7 KiB
RTC_NOINIT-backed tail of the previous boot's log. Survives
crash/WDT/soft restart — not a power cycle.

Serial options:
- **USB tether disabled** (`usb_enabled=0`): the native USB-Serial-JTAG
  console works over the same USB-C port (`/dev/ttyACM0`).
- **USB tether enabled**: TinyUSB replaces the native console with the
  NCM composite — wire a USB-UART adapter to the UART0 pins to capture
  panics live (`stty -F /dev/ttyUSBx 115200 raw -echo; cat /dev/ttyUSBx`).

Decode backtraces:

```sh
source ~/esp-idf-5.5/export.sh
xtensa-esp32s3-elf-addr2line -e firmware/build/pstop_remote.elf 0x4037.... 0x4037....
```

## What the safety layers look like when they fire

- **Bootloader rollback (bad OTA):**
  `curl -u admin:microlink http://$CHIP/admin/api/ota/status` →
  `"rollback_occurred": true` with the partition it rolled back from.
  ~17 s from bad OTA push to back on the good image, no user action.
- **Crash counter:** `boot_count` in `/state.json`; counter clears after
  10 min healthy uptime. `boot_count > 3` invokes rollback (with a
  never-brick guard if the other slot is also invalid).
- **Degradation ladder:** `boot_count==1` → `derp_only=1` for that boot
  (relay-level latency, auto-restarts back to full speed after the
  age-out); `boot_count>=2` → Tailscale paused (`wg_paused=1`).
- **Liveness abort:** log line "lwIP wedge, rebooting to recover (NOT a
  rollback trigger)" in `/api/last_log`; fires only when the active
  gateway AND pstop have both been silent 180 s after being healthy.

## Common scenarios

### Plugged into USB: the laptop's network stays "connecting…" and the unit joins WiFi instead

Expected on any host that hasn't done the one-time tether setup. The
chip's USB-NCM runs **no DHCP server** — the host must own the link
(NetworkManager `shared` mode: host = `10.42.0.1`, DHCP + NAT for the
chip). Without it the host waits forever for DHCP that never comes,
and the chip, seeing no usable USB uplink, falls back to its
provisioned WiFi. Fix (two files, once per host): install
`host/70-esp-pstop.link` and add the shared profile — full steps in
`host/README.md` → "USB tether — one-time host setup". After replug
the chip DHCPs to `10.42.0.x` and prefers the USB uplink. Point it at a
machine node on the host with `POST /api/pstop_peer?ip=10.42.0.1&port=8890`
(a fresh unit has no peer configured).

### `tailscale ping $CHIP_TS` shows tx climbing, rx 0

Almost always the chip's peer allowlist doesn't include your host's
Tailscale IP (the chip drops DISCO from unknown peers):

```sh
MY_TS_IP=$(tailscale ip -4)
curl -u admin:microlink -X POST http://$CHIP/admin/api/peers/allowed \
     -H "Content-Type: application/json" \
     -d "{\"peers\":[{\"ip\":\"$MY_TS_IP\",\"label\":\"$(hostname)\"}]}"
curl -u admin:microlink -X POST http://$CHIP/admin/api/settings \
     -H "Content-Type: application/json" \
     -d "{\"priority_peer_ip\":\"$MY_TS_IP\"}"
curl -u admin:microlink -X POST http://$CHIP/admin/api/restart
```

Set `priority_peer_ip` to the machine host — it gets the tightened 3 s
disco heartbeat and the ≤10 s direct→DERP failover.

### Tunnel latency ~100–200 ms instead of ~5–25 ms

The chip is riding a DERP relay instead of the direct UDP path:
1. `derp_only=1` in `/state.json` → post-crash ladder; wait ~10 min for
   the auto-restart, or restart manually.
2. Direct path never formed → NAT/firewall/different LAN between chip
   and peer. DERP works, just slower; the pstop link stays up either way.

> **Do not use `pstop_rtt_ms` to judge direct-vs-relay.** It is
> counter-lag-inflated and can read ~100 ms on a ~10 ms direct path
> (`main.c:619`). Judge the path with `tailscale status` (`direct <ip>` vs
> `relay <region>`) from the machine, or the chip's `/admin/api/monitor`
> `pp_has_direct` / `pp_best_ip` (the endpoint the chip picked for the machine).

### Same-LAN chip and machine still relay through DERP

Both on one LAN but the pstop link won't go direct. Check, in order:
1. **Chip advertises its LAN endpoint** — `/admin/api/monitor` `advert_lan_ip`
   should equal the chip's active-uplink IP (not 0). Fixed 2026-07-22 so eth/USB
   units advertise it, not just WiFi.
2. **Machine host isn't hijacking the chip's LAN IP into Tailscale** — on the
   machine, `ip route get <chip-LAN-IP>` must NOT return `dev tailscale0`. If a
   tailnet subnet router advertises the LAN, add `sudo ip rule add to
   <chip-LAN-IP>/32 lookup main priority 1000` (see the subnet-route caveat
   below). This was the dominant real blocker in bench testing.
3. **AP/client isolation** — some APs block client-to-client traffic; no
   firmware change overcomes it, only DERP will work there.

### Machine stays in STOP after the switch was released

Expected if the STOP episode was shorter than the arming policy minimum
(`min_stop_ms = 500` in `host/machine.toml`) — the runner logs
"ANOMALY: arming VETOED". Re-arm with a deliberate press-and-hold
(≥0.5 s) then release. Also expected after any link outage ≥1 s: the
machine latches NEED_STOP and requires a fresh press→release.

### `/api/health` says WARN or CRITICAL

`GET /api/health` → `warnings[]`. `button_wear` at ≥ 80 % of the switch's
rated 100,000 operations (`CONFIG_DCS_BUTTON_RATED_OPS`) is a plan-to-replace
notice; CRITICAL at 100 % means replace the switch, then
`POST /api/health/reset?what=button&confirm=1` (admin) so the count restarts
and `button_swaps` records the service. `loop_mismatch` means one switch loop
has been reading open while the other read closed, more than
`CONFIG_DCS_MISMATCH_WARN_PER_1000` times per 1000 presses: reseat both
terminal pairs and the header, then watch `mismatch_events` for a week; if it
keeps climbing the switch contacts are bouncing and it is due for
replacement. The counters survive reflash and OTA; `erase-flash` zeroes them.
Field semantics: `docs/MONITORING.md`.

### `pstop_mismatch` climbing / ring purple

The two cores' encodings disagree — check the loop diagnostics
(`e_hi*/e_lo*`): one channel open (broken wire, connector) or sense
stuck high while the other is healthy. A genuine both-pole press shows
RED (agreed STOP), not purple.

### Machine log shows "ANOMALY: counter gap"

The chip increments its counter every tick but only sends on lockstep
agreement, so a gap means messages were dropped OR withheld
(mismatch/boot-priming hold) — not necessarily wire loss. Persistent
gaps + `max_lost_messages` (10) exceeded → MSG_LOST STOP.

### Remote shows `REJECTED` on a machine slot / `last_msg = UNBOND`

The machine refused this remote's BOND — it is on the machine's **denylist**, or
the machine runs a non-empty **allowlist** that does not include it
(`GET /api/admission` on machn; `software.allowlist`/`denylist` on the ROS 2
node; `[policy]` in `machine.toml`). The remote parks the slot deliberately and
**does not retry**. Fix the list on the machine, then press **Rebond** on the
remote's machine-peer row (or `POST /api/pstop_peers?slot=N&rebond=1`). A slot
reconfigure or reboot also retries.

### After upgrading a machine, its old operator list is gone

Expected. The old list granted *re-arm* authority, which is now the remote's own
announced role. At first boot the machine moves those ids into its **pin list**
(`GET /api/admission` → `pinlist`; one WARN log line) so they keep their
WireGuard pinning, and starts with open admission. Promote the remotes that
should arm (`/api/role`) and, only if you want to restrict bonding, build the
admission allowlist (`/api/admission?allow=`).

### Remote bonds and sends OK but the machine never arms

The remote announces `stop_only`. Check `GET /api/role` on the **remote**
(`state.json` `role`) and promote it with `POST /api/role?role=operator` (admin
auth). Applies live — no reboot, no re-bond. The machine has no operator list
any more; only the remote's announced role grants re-arm.

### Tailscale reachable from some hosts, not the operator laptop

A tailnet subnet router advertising the robot's LAN steals traffic to
the chip's LAN IP (policy rule beats the connected route). Bench
workaround: an `ip rule` preference for the connected route. Subnet-router
interaction and fleet isolation are covered in `TAILSCALE_ISOLATION.md`.

### Reachable over USB/LAN but not via its Tailscale IP (remote management fails)

The unit checks in fine but can't be reached *inbound* over Tailscale — its
single DERP connection isn't homed on the management server's region, so remote peers relay
to the wrong region and packets never arrive. Critical for NAT'd units (USB
tether / symmetric NAT) where DERP relay is the only inbound path (no direct
hole-punch). Diagnose via `/admin/api/monitor`:

- `fleet_peer_region` — the management server's DERP region as learned by the chip.
- `derp_home_region` / `priority_peer_region` — where DERP is homed / the region
  the chip decided on. Both should equal `fleet_peer_region` (or the priority
  peer's region, which wins when known).
- `derp_connected` — must be true for relay reachability.
- `rehome_calls` / `rehome_applied` — did the re-home run. **`rehome_calls = 0`
  means the WG task isn't running at all** → see the boot-safety pause below.

A wrong region self-heals within a few seconds (the firmware re-homes to the
management server's region and re-advertises it in every MapRequest). If it doesn't recover,
OTA the latest build.

### Tailscale paused / `wg_mgr` task Suspended (boot-safety)

Symptom: `wg_paused=1`, `derp_paused=1`, `ts_boot_en=0`, DERP down, `rehome_calls=0`,
and the `wg_mgr` task shows **Suspended** in `/admin/api/monitor`. The boot-safety
ladder pauses Tailscale after repeated crash-class boots (`boot_count>=2`) to
escape a perceived boot-loop — easily tripped on the bench by aggressive OTA +
hard power-cycling. Recover:

1. `curl -u admin:PW -X POST http://$CHIP/api/ts_boot` — confirm it returns `"ts_boot_en":1`.
2. `curl -u admin:PW -X POST http://$CHIP/admin/api/restart` — a **clean** SW
   restart. Do **not** power-cycle: a hard cut is a crash-class boot and re-arms
   the pause.

For a wedged USB-NCM tether (chip enumerates as `303a:4001` but takes no IP on
`10.42.0.0/24`), power-cycle it via the LC relay: `usb-switch cycle`.

> Note: on these units `/api/last_log` (RTC ring) is unreliable/previous-boot and
> the USB-CDC console emits nothing — debug with the `/admin/api/monitor`
> **counters**, not logs.

### OTA upload times out / hangs

- Don't OTA with a flapping interface enabled — route churn kills the
  TCP session (disable WiFi first if it's bouncing).
- WiFi RSSI below −80 dBm makes large uploads flaky regardless.
- Check `heap_min_int` and `/api/last_log` (chip may be crashing during
  the upload).
- A partial upload never half-applies: the bootloader accepts the full
  image atomically or rejects it.

## Field escalation ladder

1. Soft reboot: `curl -u admin:microlink -X POST http://$CHIP/admin/api/restart`
2. Toggle an interface (each returns JSON, supervisor re-picks the route
   within 1 s): `curl -X POST http://$CHIP/api/iface/eth` (`/wifi`, `/usb`)
3. Toggle Tailscale-at-boot: `curl -X POST http://$CHIP/api/ts_boot`
   (NVS flag, takes effect next reboot)
4. OTA the latest known-good `pstop_remote.bin` (see
   `RECOVERY_PLAYBOOK.md`)
5. Physical reflash: hold BOOT, tap RST → ROM download mode →
   `idf.py -p /dev/ttyACM0 flash`. Last resort; NVS (settings, peer,
   history) survives a reflash because the partition offsets are stable.

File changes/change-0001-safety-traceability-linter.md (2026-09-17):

# change-0001 — Safety traceability linter: machine-checked requirements coverage

**Implements:** No ADR. Authority is the safety chain itself —
`docs/safety/SAFETY_REQUIREMENTS.md`, `docs/safety/TRACEABILITY.md`,
`docs/safety/SYSTEM_DEFINITION.md`.
**Branch:** `change-0001-safety-traceability-linter`
**Base:** `main`
**Status:** implementation complete; PR CI pending
**Safety class:** B — assurance tooling and CI only; no runtime safety-path,
interface, timing, state-machine, protocol, or requirement change.
**Authorization:** one authorizer approved implementation with the exact instruction
`proceed` on 2026-09-11.

Read `docs/safety/TRACEABILITY.md` §1 (Method) and §3 (coverage summary) in full
before starting, then `docs/safety/SAFETY_REQUIREMENTS.md` §1 (numbering and
conventions). Those documents are the authority; this document is the work
breakdown. Where the two disagree, the safety documents win — stop and flag the
conflict rather than choosing.

The repository is the source of truth for the safety case. Where any Notion page
disagrees with a file under `docs/safety/`, the file wins
(`docs/safety/RECONCILIATION.md` establishes this).

The design decisions in §1 and §1a are settled and are not open for
reinterpretation during implementation.

---

## 1. What this change delivers

A checked-in linter that parses the existing safety markdown, asserts
bidirectional traceability consistency across `SAFETY_REQUIREMENTS.md`,
`TRACEABILITY.md` and `SYSTEM_DEFINITION.md`, computes the requirements-coverage
numbers, regenerates the §3 summary block in `TRACEABILITY.md`, and fails CI when
a change breaks traceability or silently drops a requirement's verification.

**Settled decision 1 — markdown is canonical; the linter parses it.** The SR
tables carry hand-authored safety argument in the Status column (reconciliation
dates, commit hashes, named residuals). Extracting them into YAML and generating
the markdown back would flatten that prose into quoted strings and make review
worse, not better. The linter reads the tables and never rewrites them, with one
exception: the generated block in §4d.

**Settled decision 2 — stdlib only.** No `pyyaml`, no `pytest`, no new package
manager. The repo has no Python packaging (`pyproject.toml` absent) and its
existing Python tools are standalone `python3` scripts. Baseline and output files
are JSON, which the `polymath-json` pre-commit hook already covers.

**Settled decision 3 — ratchet, not gate.** The tree does not pass these checks
today: five functions carry no requirement, and `OPEN_ITEMS.md` and
`TRACEABILITY.md` disagree on the requirement count. A baseline file records every
pre-existing violation with a reason. CI fails on new violations only, and fails
when a baselined violation is fixed but not removed from the baseline.

### 1a. Ratified implementation clarifications (2026-09-11)

1. Define the SRS status vocabulary in `checks.py` as `Satisfied`,
   `Partially satisfied`, `Gap`, and `Residual-accepted`, longest-match-first.
   Do not derive it from the conventions prose and do not edit that prose. Emit an
   informational finding when a status in use is absent from the conventions list.
2. The CI workflow has no path filter. It runs on every pull request and every push
   to `main` so moved or deleted evidence cannot escape the check.
3. Baseline the broken `test_timing_floors` citation with owner `raj`. Git history
   establishes that `test_timing_floors.cpp` was added by `1f226be` and deleted by
   `9a28d4a` during the ROS 2 convention restoration. Record those facts without
   deciding whether SR-M-01 remains Verified.
4. Do not rearrange `TRACEABILITY.md`. Use multiple named generated marker pairs
   around purely numeric regions. A bullet mixing numbers with hand-authored prose
   remains outside markers and is checked rather than rewritten. If markers cannot
   meet that rule, stop and quote the resisting text.
5. Evidence resolves only through the documented shorthand, an explicit repository
   path, a repository-wide unique filename or test-source stem, or an existing HIL
   or evidence report that names the cited SR. An ambiguous stem is a finding. Never
   choose the nearest match and never infer evidence from prose.
6. The linter measures citations, not passing execution. Generated output is labelled
   "SRs with at least one cited verifying test" and includes a footnote that citation
   resolution, not test execution, is checked. Existing "passing" wording is not
   edited. If the generated label conflicts with surrounding prose, stop and report.
   If computed citation coverage differs from committed 32/40, report both values and
   the per-SR delta and change nothing.

---

## 2. Scope

### IN scope

1. `tools/safety_lint/` — parsers for the three safety documents.
2. Nine consistency checks (§4c), each with an error/warning severity.
3. Coverage computation reproducing the §3.1 and §3.2 numbers from the parsed
   data.
4. Generated-block rendering into `TRACEABILITY.md` §3 between HTML markers, with
   a `--check` mode that fails when the committed block is stale.
5. `docs/safety/lint-baseline.json` — recorded pre-existing violations with
   reasons and owners.
6. `.github/workflows/safety-lint.yml` — runs the linter on every PR and on every
   push to `main`, without path filters.
7. `tools/safety_lint/self_test.py` — the linter's own test suite, stdlib
   `unittest`, run by the same workflow.

### OUT of scope — do NOT build

- **Any edit to the safety argument itself.** Do not add, remove, reword or
  re-status a requirement. Do not change a Status cell to make a check pass. If a
  check fails on real content, baseline it and report it.
- Any file under `docs/safety/` other than approved generated/check-only markers in
  `TRACEABILITY.md` §3 and the new `lint-baseline.json`. In particular, do not edit
  the SRS conventions section.
- Anything under `pstop_c/` — certified library, separate upstream track,
  excluded from pre-commit for that reason.
- Anything under `ros2/` — governed by ament linters.
- Line-number verification of `file:line` code citations. Files are checked to
  exist; line numbers drift constantly and are explicitly documented as "±a few
  lines as the tree evolves" (`SAFETY_REQUIREMENTS.md` §1). Do not assert on them.
- Parsing `FMEA.md`, `HARA.md` or `FMEDA.md` beyond extracting bare ID sets for
  check C7.
- Structural-coverage integration. `COVERAGE.md` and `docs/safety/coverage/host-summary.json`
  stay out; this change measures requirements coverage only.
- The modification procedure migration from Notion. Separate change.
- Any CI gate on `main` branch protection. The workflow is added; enabling it as a
  required check is a repo-admin action, not this change.

---

## 3. Integration facts (do not rediscover these)

| Fact | Value |
|---|---|
| Requirements spec | `docs/safety/SAFETY_REQUIREMENTS.md` |
| Traceability matrix | `docs/safety/TRACEABILITY.md` |
| Function decomposition | `docs/safety/SYSTEM_DEFINITION.md` §4 (`## 4. Function / item decomposition`, line 95) |
| FMEA (DU register) | `docs/safety/FMEA.md` §3 |
| HARA (safety goals SG-1..6, hazards H-nn) | `docs/safety/HARA.md` §5 |
| Reconciliation record ("code wins") | `docs/safety/RECONCILIATION.md` |
| Open items register | `docs/safety/OPEN_ITEMS.md` |
| SR ID grammar | `SR-<area>-<nn>`; areas `SYS`, `R`, `H`, `M`, `I` (`SAFETY_REQUIREMENTS.md` §1) |
| SR table columns | `ID · Requirement (shall) · Derived from · Allocated to · Integrity · Verify · Status` |
| SR section headings | `## 2.` SR-SYS, `## 3.` SR-R (subsections `### 3.1`, `### 3.2`), `## 4.` SR-H, `## 5.` SR-M, `## 6.` SR-I |
| SRS status vocabulary | `Satisfied`, `Partially satisfied`, `Gap`, `Residual-accepted` — bold-wrapped, often followed by parenthetical prose |
| Traceability table columns | `SR · Alloc F-xx · Code (file:line) · Verifying test(s) · Method · Status` |
| Traceability section headings | `## 2. Traceability matrix` with `### 2.1`–`### 2.5`; `## 3. Requirements coverage summary`; `## 4. Test-gap register`; `## 5. Function → SR reverse map` with `### 5.1`–`### 5.x` |
| Traceability status vocabulary | `Verified`, `Partially-verified`, `Unverified-gap`, `Residual-accepted` (defined in a table under `## 1. Method`) |
| No-test marker | The literal string `NO TEST`, bold-wrapped, in the Verifying test(s) cell |
| Test-file shorthand legend | `TRACEABILITY.md` §2 preamble: `EV`, `MR`, `HIL10/20/30`, `JL`, `REQ n_nn` — each maps to a real path |
| `EV` | `firmware/test/test_estop_verdict.c` |
| `MR` | `tools/pstop_multi_remote_test.py` |
| `HIL10/20/30` | `tools/hil/test_10_button.py`, `test_20_discordance.py`, `test_30_power_cycle.py` |
| `JL` | `ros2/protective_stop_machine/test/test_json_lite.cpp` |
| `REQ n_nn` | `pstop_c/pstop/test/src/pstop/requirements/req_n_nn_test.c` |
| Existing CI guard script pattern | `scripts/check_estop_diversity.sh` — SPDX header, comment block naming the SR and DU it guards, `set -uo pipefail`, exit 2 for "cannot run", exit 1 for "check failed" |
| How a guard is wired to CI | `.github/workflows/firmware-build.yml:46-52` |
| Existing standalone Python test pattern | `tools/test_config_floor.py` — `#!/usr/bin/env python3`, SPDX header, module docstring naming the SR and DU |
| Existing workflows | `pre-commit.yml`, `firmware-build.yml`, `host-check.yml`, `ros2_build.yml`, `pstop_c_build.yml`, `pstop_c_coverage.yml`, `coverage.yml` |
| Checkout action version in use | `actions/checkout@v7` |
| Pre-commit config | `.pre-commit-config.yaml`, `polymath_code_standard` v2.2.0; hooks include `polymath-python`, `polymath-json`, `polymath-markdown`, `polymath-copyright` |
| Pre-commit exclusions | `pstop_c/`, `ros2/`, `archive/`, vendored wireguard/x25519, `hardware/` binaries. `tools/` and `docs/` are NOT excluded — new files must satisfy the hooks |
| Required file header | SPDX two-line header, Apache-2.0, matching `tools/test_config_floor.py` and `scripts/check_estop_diversity.sh` |
| Markdown hook caveat | `OPEN_ITEMS.md` §8 records that the markdown hook rewrites `-` list markers to `+` and that repo-wide normalization is deliberately deferred. Do not let the hook reformat `TRACEABILITY.md` wholesale — only the generated block changes |

### The requirement count disagreement

`TRACEABILITY.md` §3.1 states 40 safety requirements. `OPEN_ITEMS.md` §5 states
39 with a different coverage fraction, dated earlier. **Do not resolve this by
editing either document.** Piece 4 computes the count from the parsed SR tables.
Report the computed number. If it is neither 39 nor 40, stop and raise before
proceeding — the parser is wrong, not the documents.

---

## 4. Pieces, in dependency order

Each piece is committable on its own. Pieces 1–3 add no CI surface and cannot
break the build. Piece 5 is the first piece that can fail a PR.

---

### Piece 1 — SR parser

**Files:** `tools/safety_lint/__init__.py`, `tools/safety_lint/parse_srs.py`,
`tools/safety_lint/model.py`.

**1a. Record types** in `model.py`, frozen dataclasses, stdlib only:

```python
@dataclass(frozen=True)
class SafetyRequirement:
    sr_id: str                  # "SR-R-03"
    area: str                   # "SYS" | "R" | "H" | "M" | "I"
    number: int                 # 3
    shall_text: str             # raw cell, markdown intact
    derived_from: tuple[str, ...]   # ("SG-1", "H-09", "DU-3")
    allocated_to: tuple[str, ...]   # ("F-R-02",)
    integrity: str              # raw cell
    verify_methods: tuple[str, ...] # ("Fault-injection", "Test")
    status: str                 # normalized token from the SRS vocabulary
    status_prose: str           # everything after the token
    source_line: int            # 1-based line in SAFETY_REQUIREMENTS.md
```

**1b. Table discovery.** Walk the file line by line. A requirements table is a
markdown pipe table whose header row's first cell is `ID` and which contains a
cell `Derived from`. Do not hardcode section numbers — `SAFETY_REQUIREMENTS.md`
has subsections (`### 3.1`, `### 3.2`) and more may be added. Ignore every other
pipe table in the file, including the ID-grammar table in §1.

**1c. Cell splitting.** Cells are separated by unescaped `|`. Cells contain inline
code spans with pipes inside them in at least one row — split on `|` only when not
inside a backtick span. Trim, then strip surrounding `**`.

**1d. ID parse.** `SR-(SYS|R|H|M|I)-(\d{2})`, taken from the bolded first cell.
An ID that does not match is an error, not a skip.

**1e. Reference extraction.** From `derived_from`, extract every token matching
`SG-\d`, `H-\d{2}`, `DU-\d`, and FMEA cross-refs of the form `[A-Z]\d{2}-\d`.
From `allocated_to`, extract every `F-[A-Z]-\d{2}`. Expand the range form
`F-R-01..05` into its members. Expand the slash form `F-M-03/04` into
`F-M-03`, `F-M-04`. Both forms occur.

**1f. Status normalization.** Match the leading bolded token against the SRS
vocabulary, case-insensitively, longest match first so `Partially satisfied` is
not read as `Satisfied`. Note that `Partially satisfied — feedback limb
DESCOPED 2026-08` occurs; everything after the token is `status_prose`. A cell
whose leading token is outside the vocabulary is an error naming the file, line
and cell.

**Tests** (`self_test.py`, stdlib `unittest`):
- `test_parses_all_sr_areas` — parse the real `SAFETY_REQUIREMENTS.md`; assert at
  least one SR in each of the five areas.
- `test_sr_ids_unique` — no duplicate `sr_id`.
- `test_allocated_to_range_expansion` — `"F-R-01..05, F-H-03"` yields six
  functions including `F-R-03`.
- `test_allocated_to_slash_expansion` — `"F-M-03/04"` yields two.
- `test_status_longest_match_wins` — a cell beginning `**Partially satisfied**`
  normalizes to `Partially satisfied`, never `Satisfied`. Drift-verify: reorder
  the vocabulary so the short token matches first, confirm the test fails, revert.
- `test_pipe_inside_code_span_does_not_split_cell` — synthetic row containing
  `` `a|b` `` parses as one cell.

---

### Piece 2 — Traceability and system-definition parsers

**Files:** `tools/safety_lint/parse_traceability.py`,
`tools/safety_lint/parse_system_definition.py`, `tools/safety_lint/model.py`.

**2a. `TraceRow`** — `sr_id`, `allocated_to`, `code_refs`, `test_refs`,
`methods`, `status`, `status_prose`, `has_no_test_marker`, `source_line`.

**2b. Matrix discovery.** A traceability table's header row's first cell is `SR`
and it contains a cell beginning `Verifying test`. Same subsection caveat as 1b.

**2c. Code-reference extraction.** From the Code cell, extract tokens shaped
`path:line` or `path:line-line` or a bare backticked filename. Resolve a bare
filename against the paths named in `SYSTEM_DEFINITION.md` §4 where possible;
where not, record it as unresolved rather than failing.

**2d. Test-reference extraction.** Expand the shorthand legend from §3 above into
real paths. Handle the group-letter form `MR[B/D/E/F]` — the path is the same, the
bracket is a group selector, so record the path once. Handle `REQ 2_02/2_03` as
two `req_*_test.c` paths. Also resolve explicit repository paths and a bare filename
or test-source stem only when it is unique across the whole repository. Ambiguity is
a finding, never a nearest-match choice. An HIL/evidence report counts only when the
file exists and names the row's SR. Never infer evidence from prose. Record the
literal `NO TEST` marker separately from test paths; a cell may contain both a
`NO TEST` phrase and real tests, and it does in several rows.

**2e. Reverse-map parser.** Parse §5's tables into `{F-xx: (function_name,
tuple_of_sr_ids)}`. A cell whose SR list is an em-dash-led "none" phrase yields an
empty tuple plus a `declared_non_safety` flag when the phrase contains
`non-safety`.

**2f. System-definition parser.** Parse `SYSTEM_DEFINITION.md` §4's tables into
the authoritative `F-xx` set with names. This is the spine both other documents
are checked against.

**Tests:**
- `test_every_trace_row_has_sr_id`
- `test_test_shorthand_expands_to_existing_paths` — every expanded shorthand path
  exists on disk.
- `test_mr_group_selector_yields_single_path` — `MR[B/D/E/F]` yields one path.
- `test_req_slash_form_yields_two_paths`
- `test_no_test_marker_detected_alongside_real_tests` — a cell with both records
  `has_no_test_marker=True` and a non-empty `test_refs`.
- `test_reverse_map_flags_declared_non_safety` — `F-R-08` parses with an empty SR
  tuple and `declared_non_safety=True`.
- `test_system_definition_function_set_nonempty`

---

### Piece 3 — Consistency checks

**Files:** `tools/safety_lint/checks.py`.

Each check returns zero or more `Finding(check_id, severity, subject, message,
file, line)`. `severity` is `error` or `warning`.

**C1 — SR set parity.** Every SR in `SAFETY_REQUIREMENTS.md` appears exactly once
in the traceability matrix, and vice versa. Severity: error. Subject: the SR ID.

**C2 — Status vocabulary closed.** Every SRS status normalizes to the SRS
vocabulary; every traceability status normalizes to the traceability vocabulary.
Severity: error.

**C3 — Status and evidence agree.** A traceability row with status `Verified` or
`Partially-verified` names at least one resolvable test path. A row with status
`Unverified-gap` carries the `NO TEST` marker and names no test path outside a
`NO TEST` clause. Severity: error. This is the check that catches a requirement
losing its test silently.

**C4 — Cited test files exist.** Every resolved test path exists in the working
tree. Severity: error. Paths under `pstop_c/` are checked for existence but never
opened.

**C5 — Cited code files exist.** Every resolved code path exists. Severity:
error for a missing file. Line numbers are never checked — see §2 OUT of scope.
An unresolved bare filename is severity `warning`.

**C6 — Function allocation is real.** Every `F-xx` in any `Allocated to` cell
exists in the `SYSTEM_DEFINITION.md` §4 set. Severity: error.

**C7 — Upstream references resolve.** Every `SG-n` appears in `HARA.md`, every
`H-nn` appears in `HARA.md`, every `DU-n` appears in `FMEA.md`. Extract bare ID
sets by regex from those files; do not parse their structure. Severity: warning —
those documents restructure and a false positive here must not block a PR.

**C8 — Reverse map completeness.** Every `F-xx` in the system-definition set
appears in the reverse map, and the reverse map's SR list for each function equals
the set of SRs whose `Allocated to` names it. Severity: error for a disagreement,
warning for a function with no SRs at all — the latter is a real known state
(`F-H-04`, `F-M-01`, `F-M-06`) and belongs in the baseline.

**C9 — SRS and traceability agree on allocation.** For each SR, the `Allocated
to` set in the SRS equals the `Alloc F-xx` set in the matrix. Severity: error.

**Baseline handling.** `docs/safety/lint-baseline.json`:

```json
{
  "generated": "2026-09-10",
  "note": "Pre-existing findings accepted at linter introduction. Each entry needs an exact finding message, owner, and reason. Removing a fixed entry is required; CI fails on a stale entry.",
  "findings": [
    {
      "check_id": "C8",
      "subject": "F-H-04",
      "finding": "function has no allocated safety requirement",
      "reason": "Robot status output + logging carries no SR. Known requirements-coverage hole, TRACEABILITY.md §5.2.",
      "owner": "raj"
    }
  ]
}
```

A baseline entry matches exactly one finding by `(check_id, subject, finding)`,
where `finding` is the complete stable finding message. That exact finding is
downgraded to informational and reported in a separate section. A new finding on
the same check and subject remains active. Duplicate exact entries are invalid,
and a baselined entry with no exact matching finding is itself an error — this is
the ratchet.

**Tests:**
- One `test_<check_id>_flags_<condition>` per check, driven by small synthetic
  markdown fixtures under `tools/safety_lint/fixtures/`, not by the real
  documents. The real documents are exercised in Piece 4's integration test.
- `test_baseline_suppresses_exact_matching_finding`
- `test_same_subject_new_finding_is_not_suppressed`
- `test_stale_exact_baseline_entry_is_an_error` — a baselined exact finding with
  no corresponding finding produces an error.
- `test_duplicate_exact_baseline_entries_are_rejected`
- Drift-verify C3 and C8: break the guarded condition in a fixture, confirm the
  test fails, revert. Report that you did it.

---

### Piece 4 — Coverage computation and generated summary

**Files:** `tools/safety_lint/coverage.py`, `tools/safety_lint/render.py`,
`docs/safety/TRACEABILITY.md` (generated block only).

**4a. Counts.** From the parsed traceability rows, compute per area and in total:
count, and counts of `Verified`, `Partially-verified`, `Unverified-gap`,
`Residual-accepted`.

**4b. The two headline fractions**, matching the definitions in §3.1 verbatim:
- **(a) SRs with at least one passing verifying test** = rows whose `test_refs` is
  non-empty, irrespective of status. Note that this currently includes one
  `Residual-accepted` row that has a test (`SR-M-06`) and excludes the other
  (`SR-M-04`, inspection only). Do not special-case by status; count by evidence.
- **(b) Functions traced to at least one SR** = functions in the system-definition
  set with a non-empty SR list. Report both the raw fraction and the fraction
  excluding functions flagged `declared_non_safety`.
- **Strict, fully-verified** = rows with status exactly `Verified`.

**4c. Reproduce before you replace.** Run the computation against the current
tree and compare with the committed §3.1 and §3.2 numbers. They should match. If
any figure differs, **stop and report the discrepancy with both numbers** before
touching the document. A mismatch means either the parser is wrong or the
committed summary is stale; both need a human decision, and the second is a real
finding worth surfacing.

**4d. Generated regions.** Use multiple named marker pairs around purely numeric
regions only:

```
<!-- BEGIN GENERATED: safety-lint <name> -->
...
<!-- END GENERATED: safety-lint <name> -->
```

The surrounding prose in §3 — mixed numeric/prose bullets, the "Reading:"
paragraph, the `†` footnote, and bracketed reconciliation notes — is hand-authored
and stays outside the markers without being moved. Mixed bullets are checked, not
rewritten. Generated coverage is explicitly labelled "SRs with at least one cited
verifying test" and states that the linter checks citation resolution, not test
execution. Rendering replaces only marker contents. `--check` mode renders and
diffs without writing, exiting non-zero on a difference.

**Tests:**
- `test_coverage_matches_committed_summary` — integration against the real
  documents. If Piece 4c found a legitimate discrepancy, this test asserts the
  computed value and carries a comment naming the discrepancy and its resolution.
- `test_generated_block_is_idempotent` — render twice, byte-identical.
- `test_check_mode_detects_stale_block` — mutate a number inside the markers,
  assert `--check` exits non-zero.
- `test_render_does_not_touch_prose_outside_markers` — assert the "Reading:"
  paragraph is byte-identical before and after a render.

---

### Piece 5 — CLI and CI wiring

**Files:** `tools/safety_lint/__main__.py`, `.github/workflows/safety-lint.yml`.

**5a. CLI.** `python3 -m tools.safety_lint [--check] [--write] [--json]`, run from
the repository root.
- Default: run all checks, print a human-readable report, exit 1 on any
  non-baselined error, 0 otherwise.
- `--check`: also verify the generated block is current; exit 1 if stale.
- `--write`: regenerate the block in place.
- `--json`: emit findings as JSON to stdout for future tooling.

Exit codes follow `scripts/check_estop_diversity.sh`: `0` pass, `1` check failed,
`2` cannot run (a required document missing or unparseable).

**5b. Report format.** Errors first, then warnings, then a baselined section, then
the coverage summary. Every finding prints `file:line: [check_id] subject —
message`. The coverage summary prints the same numbers that go into the generated
block, so a reviewer reading CI output does not need to open the diff.

**5c. Workflow.** `.github/workflows/safety-lint.yml`, modelled on the existing
workflows: `actions/checkout@v7`, `ubuntu-latest`, triggers on every push to `main`
and every `pull_request`, with no path filters. Two steps: run `self_test.py`, then
run the linter with `--check`.

**5d. Do not add this to `.pre-commit-config.yaml`.** The linter reads several
files and computes cross-document state; pre-commit's per-file model fits it
badly and the markdown hook's list-marker rewrite is a known landmine
(`OPEN_ITEMS.md` §8). CI only.

**Tests:**
- `test_cli_exit_code_zero_on_clean_tree` — with the baseline in place, the real
  tree exits 0.
- `test_cli_exit_code_one_on_injected_error` — copy the safety docs to a temp
  directory, delete a traceability row, assert exit 1 and a C1 finding.
- `test_cli_exit_code_two_on_missing_document`
- Workflow: confirm it runs and passes on the PR that introduces it. Paste the
  run URL.

---

## 5. Definition of Done

Non-negotiable. A piece is not done until all of these are true and reported.

1. **Tests written first** (red → green) and exercising the real parsing path — no
   monkeypatching the parser under test, no asserting on hand-built record objects
   where the point is that the parser produced them.
2. **Drift-verify each guard test** named above: break the guarded thing, confirm
   the test fails, revert. Report that you did it. C3, C8 and the status
   longest-match test are the three that matter most.
3. **Run the real gate yourself and paste actual output:**
   `python3 tools/safety_lint/self_test.py` and
   `python3 -m tools.safety_lint --check`.
4. **Run `pre-commit run --all-files`** and paste the result. New files under
   `tools/` and `docs/` are in scope for the hooks; the SPDX header and
   `polymath-python` formatting are enforced.
5. **Confirm `git diff docs/safety/` touches only the generated block and
   `lint-baseline.json`.** Paste the diff. Any other change to a safety document
   is a scope violation and must be reverted.
6. **The baseline is justified line by line.** Every entry carries a reason
   naming the document section it comes from, and an owner. A baseline entry with
   a reason of "pre-existing" is not acceptable.
7. **Report two separate sections,** and do not merge them:
   - **"Out of scope, confirmed not built"**
   - **"In scope, required, not done"** — must be empty. Anything in it is
     blocking.
8. **Report the computed requirement count** and state whether it is 39, 40, or
   something else, with the per-area breakdown.

---

## 6. Acceptance criteria

- **AC-1 — parity.** C1 reports zero non-baselined findings against the current
  tree. Every SR in the spec appears exactly once in the matrix and vice versa.
- **AC-2 — count resolved.** The linter reports a single authoritative requirement
  count with a per-area breakdown, and the report states whether it agrees with
  `TRACEABILITY.md` §3.1, `OPEN_ITEMS.md` §5, both, or neither.
- **AC-3 — coverage reproduces.** The computed headline fractions match the
  committed §3.1 numbers, or every difference is reported with both values and an
  explanation before any document is modified.
- **AC-4 — evidence check bites.** Delete `tools/hil/test_10_button.py` in a
  scratch copy; the linter reports a C4 error naming `SR-SYS-03` among the
  affected requirements. Restore. Record the output.
- **AC-5 — silent-drop check bites.** In a scratch copy, change one
  `**Verified**` row's Verifying test cell to `**NO TEST**` while leaving the
  status as `Verified`; the linter reports a C3 error. Restore. Record the output.
- **AC-6 — ratchet works.** Remove one entry from `lint-baseline.json` without
  fixing the underlying issue; the linter reports the finding as a new error.
  Re-add it, then fix the underlying issue in a scratch copy without removing the
  baseline entry; the linter reports the stale entry as an error.
- **AC-7 — generated block is safe.** Running `--write` twice produces no diff on
  the second run, and the "Reading:" paragraph and the `†` footnote in §3 are
  byte-identical before and after.
- **AC-8 — pre-commit clean.** `pre-commit run --all-files` passes, and the run
  did not reformat any file outside this change's scope.
- **AC-9 — CI green.** `safety-lint.yml` passes on the introducing PR. Paste the
  run URL.

---

## 7. Workspace hygiene

- `git status` before you start. If the tree has changes you did not make, stop
  and report — do not stage, revert, or build over them.
- Work on `change-0001-safety-traceability-linter`, branched from `main`. Never
  commit to `main` and never `git push origin main`.
- Touch only the files this plan names. If another file must change, say so and
  why before changing it.
- Every change lands via this branch and a PR targeting `main`.
- Note that `origin/pstop` → `main` may still be open for review
  (`OPEN_ITEMS.md` §8). Confirm `docs/safety/` is present on `main` before
  branching; if it is not, stop and raise.

---

## 8. Known traps

1. **Do not fix the safety documents to make the linter pass.** The linter exists
   to surface disagreements, and the disagreements it surfaces are safety
   findings owned by a human. Editing a Status cell, adding a test reference, or
   silently correcting a count converts a finding into a lie. Baseline it and
   report it.
2. **`Partially satisfied` starts with the substring `Satisfied` is false, but
   `Residual-accepted` and `Residual-with-test` both start with `Residual`.**
   Longest-match-first on status normalization, always. A short-match bug scores
   partials as fully verified and inflates the headline number — the single most
   damaging failure mode this tool can have.
3. **Cells contain pipes inside backtick spans.** A naive `line.split("|")`
   shreds rows and the damage is silent: you get a parsed row with shifted columns
   rather than an exception.
4. **`Allocated to` uses three notations in the same document** — plain
   (`F-R-02`), range (`F-R-01..05`), and slash (`F-M-03/04`). All three appear in
   §2's SR-SYS table alone.
5. **A `NO TEST` marker can coexist with real test references in one cell.**
   `SR-SYS-01`, `SR-SYS-02`, `SR-SYS-05`, `SR-SYS-08`, `SR-SYS-09` and `SR-R-13`
   all name real tests and then state that a specific leg has none. Treating the
   marker as "this row has no tests" mis-scores six rows.
6. **`OPEN_ITEMS.md` and `TRACEABILITY.md` disagree on the requirement count and
   the coverage fractions.** They were written at different dates. Neither is
   authoritative for this change; the parsed tables are.
7. **The markdown pre-commit hook rewrites `-` list markers to `+`.**
   `OPEN_ITEMS.md` §8 records that repo-wide normalization is deliberately
   deferred and that per-file application creates inconsistency. If the hook
   rewrites list markers across `TRACEABILITY.md`, revert and report — the
   generated block must not drag a repo-wide reformat in with it.
8. **`pstop_c/` is excluded from pre-commit and is on a separate upstream track.**
   Test paths under it are checked for existence and never opened, never
   formatted, never modified.
9. **The five functions with no SR are real, not parser bugs.** `F-R-08` and
   `F-R-10` are declared non-safety; `F-H-04`, `F-M-01` and `F-M-06` are genuine
   holes recorded in `TRACEABILITY.md` §5. All five belong in the baseline with
   that distinction preserved.
10. **Line numbers in `file:line` citations drift by design.**
    `SAFETY_REQUIREMENTS.md` §1 says so explicitly. A linter that asserts on them
    fails on every unrelated commit and will be disabled within a week.

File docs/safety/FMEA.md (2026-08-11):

<!-- SPDX-FileCopyrightText: 2026 Polymath Robotics, Inc. -->
<!-- SPDX-License-Identifier: Apache-2.0 -->

# Protective-Stop — FMEA (first draft)

**Status:** Engineering first draft for safety-lead curation. Keyed to the
function IDs in `docs/safety/SYSTEM_DEFINITION.md` (F-R-xx remote firmware,
F-H-xx host machine, F-M-xx ROS2 machine, F-P-xx pre-qualified `pstop_c`
interface). Analysis is of the **code as it stands**, honoring the
reconciliation block: Option A + Option B **implemented**, Option C
**dropped**. Where `PSTOP_SAFETY_DESIGN.md` §6/§10 disagree with the code, the
code wins and the discrepancy is flagged (see §6 of this document).

**Standard frame:** IEC 61508 (systematic capability + FMEDA feed) + ISO 13849
(PL for the actuation side). Target **SIL 3 / PL e**. Safe state = **STOP =
de-energized**. Inherited fail-danger polarity: `OK == 0x00`, `STOP == 0x01`
(`pstop_c/pstop/include/pstop/pstop_msg.h:15-16`).

---

## 1. Method

Each **item** (a code unit or hardware element) realizes one or more
**functions** (F-xx). For every function I enumerate credible **failure modes**
and classify their end effect on the three safety functions (SF-1 stop-on-
demand, SF-2 no-spurious-run, SF-3 arming-integrity) along two axes: **Safe vs
Dangerous** (does the fault tend toward or away from the de-energized safe
state?) and **Detected vs Undetected** (is there an existing on-line mechanism
that catches it and forces the safe reaction?). Criticality is scored
**S**everity × **O**ccurrence × **D**etection, each 1–5 (5 = worst: most
severe / most frequent / least detectable), RPN = S·O·D. Severity is near-
uniformly high because every dangerous failure of a SIL 3 stop function is
potentially catastrophic; the discriminating axes are Occurrence and
Detection. **Dangerous-Undetected (DU)** rows carry D = 4–5 by definition and
are the population that governs the SIL 3 / PFH case — they are extracted into
§3. This qualitative FMEA is the input to (a) the safety-requirements set (the
"candidate requirement hook" column) and (b) a later quantitative **FMEDA**
(diagnostic-coverage / SFF apportionment); the S/O/D here are engineering
estimates, not measured failure rates.

Scoring key: **Class** ∈ {Safe-Det, Safe-Undet, **Dang-Det**, **Dang-Undet**}.
Line/file citations are to the analyzed tree.

---

## 2. FMEA table

### F-R-01 — Dual-channel E-stop loop sensing (`main.c:265` `estop_channel_closed`)

| FM ID | Failure mode | Cause | Local effect | System effect (SF) | Existing detection | Existing mitigation | Class | S/O/D | Residual gap | Candidate requirement |
|---|---|---|---|---|---|---|---|---|---|---|
| R01-1 | Button pressed / loop opened | Normal demand | drive-high echoes 0 → `rb_hi≠1` | SF-1 STOP as intended | `estop_channel_closed:274-308` both-phase read | pull-down input, STOP-only override `:345` | Safe-Det | 5/5/1 | — | Verify per-channel STOP latency ≤ PST |
| R01-2 | Single-channel wire break / one pole open | Random HW (connector, cable) | one core reads OPEN, other CLOSED → encodings diverge | SF-1 STOP (device silenced) | comparator memcmp `main.c:890` | transmit-on-agreement; machine heartbeat-timeout | Safe-Det | 5/3/1 | — | Confirm memcmp covers message+CRC bytes |
| R01-3 | Sense input **floats high on drive-high, low on drive-low** (pull-down lost) | Random HW / SEU on GPIO config reg / F-R-10 or other code reconfiguring the pad | `rb_hi==1 && rb_lo==0` on an **open** loop → false CLOSED → false OK | **SF-2 breach: spurious OK** | **NONE at runtime** — pad config set once at `estop_init:240-247`, never re-verified | one-time boot config only | **Dang-Undet** | 5/2/5 | pull-down integrity never re-checked; design §6/§10#8 claim a "config-integrity check" that **does not exist in code** | Periodic GPIO config-register read-back + drive-low-must-read-0 self-test on both channels; force STOP on mismatch |
| R01-4 | Both channels' pull-downs lost together | Common-cause: brownout, shared pad-mux bug, ESD | both cores false-CLOSED, **agree** → OK transmitted | **SF-2 breach, undetected by lockstep** | none (memcmp passes on agreement) | — | **Dang-Undet** | 5/1/5 | β≈1 for the shared config path; see §4 | Diverse pull-down verification + brown-out detector wired to safe state |
| R01-5 | `ESTOP_SETTLE_US`=10µs too short for wire+contact RC | Systematic (timing) / long cable | drive-level not yet propagated when sampled → intermittent false OPEN or false CLOSED | false OPEN=Safe; **false CLOSED=SF-2** | debounce only smooths OPEN→CLOSED | `LOOP_RECLOSE_DEBOUNCE_TICKS` (release only) | Dang-Undet | 4/2/4 | settle time is a bench constant, not validated against max cable length | Characterize loop RC vs deployed cable; derive settle time with margin |
| R01-6 | GPIO read returns stale/cached level | Silicon errata / driver | this-tick sample not fresh | defeats Option A live-sample premise | — | — | Dang-Undet | 4/1/5 | no read-back proof the sample is of *this* drive | Add read-after-write ordering barrier; document HW guarantee |

### F-R-02 — Per-core verdict formation, Option A + Option B (`main.c:373` `compute_verdict`, `:265-348`)

| FM ID | Failure mode | Cause | Local effect | System effect (SF) | Existing detection | Existing mitigation | Class | S/O/D | Residual gap | Candidate requirement |
|---|---|---|---|---|---|---|---|---|---|---|
| R02-1 | Stale/latched health flag manufactures OK | Systematic SW | — | (blocked) | Option A: OK codeword = arithmetic image of **this-tick** reads `:305`; overrides are STOP-only `:345-347` | live-sample derivation | Safe-Det | 5/2/2 | Compensates the `OK==0` polarity **for generation only** (see §3) | Assert OK is unreachable without a fresh matched sample (unit + MC/DC) |
| R02-2 | Systematic misinterpretation of `rb_hi/rb_lo` in one core's expression | Systematic SW | that core wrong, other correct → diverge | SF-1 STOP | Option B: core0 arithmetic-image `:305` vs core1 boolean `:307` → memcmp diverges | diverse expressions | Safe-Det | 4/2/2 | see R02-3 | Keep the two expressions provably non-convergent |
| R02-3 | Compiler collapses the two "logically identical" expressions to identical object code | Systematic (toolchain) | Option B diversity **evaporates** at object level → a shared codegen bug hits both identically and **agrees** | **SF-2 potential** | none (memcmp passes) | source-level diversity only | **Dang-Undet** | 4/2/4 | comment `:299` itself states they are "logically identical when correct"; single toolchain, same ISA — no compiler/ISA diversity | Compile-diverse the two verdict paths (different TU/flags) OR disassemble-and-diff as a build gate to prove non-identical machine code |
| R02-4 | Shared STOP-only override / debounce block buggy (`:317-347`) | Systematic SW (identical on both cores) | both cores mis-handle identically → agree | direction: override can only **raise** to STOP; a bug that fails to raise is masked by R02-1 (msg already STOP on mismatch) | memcmp cannot catch (identical) | STOP-biased structure | Safe-Undet | 3/2/4 | β≈1 here but fault direction is safe | MC/DC on the override block; prove monotonic (STOP-only) property by test |
| R02-5 | `k_estop_msg[]` table (core0 only) corrupted | Random RAM/flash | core0 wrong, core1 uses constants → diverge | SF-1 STOP | memcmp `:890` | table read by one core only | Safe-Det | 4/1/2 | — | — |

### F-R-03 — Release debounce + boot warm-up (`main.c:191,200,323-363`)

| FM ID | Failure mode | Cause | Local effect | System effect (SF) | Existing detection | Existing mitigation | Class | S/O/D | Residual gap | Candidate requirement |
|---|---|---|---|---|---|---|---|---|---|---|
| R03-1 | `estop_primed()` returns true too early | Systematic SW (single copy, `:359`) | boot-priming STOP→OK artifact reaches machine → auto-completes arming with no operator | **SF-3 breach** | machine `min_stop_ms`=500ms veto (boot glitch ~200ms) | comparator holds send until primed `:903` | Dang-Det | 5/2/3 | `estop_primed` is a **non-diverse single point**; SF-3 rests on machine-side min-stop | Cross-core-agreed prime flag; unit-test the boot-glitch-never-arms invariant (design §10 companion) |
| R03-2 | Debounce filters the OPEN→STOP edge | Systematic SW | STOP delayed/suppressed | **SF-1 delay** | — | code path resets `closed_streak` immediately on any unhealthy read `:332`; STOP is single-tick | Safe-Det | 5/1/2 | verify no path filters STOP direction | Test: STOP edge is never debounced |
| R03-3 | `closed_streak`/`open_streak` uint8 wrap | Systematic | counter saturates at 255 (guarded `:324,333`) | none | saturating guard | explicit `<255` clamp | Safe-Undet | 2/1/3 | — | — |

### F-R-04 — Lockstep comparator + relay send (`main.c:802` `comparator_task`)

| FM ID | Failure mode | Cause | Local effect | System effect (SF) | Existing detection | Existing mitigation | Class | S/O/D | Residual gap | Candidate requirement |
|---|---|---|---|---|---|---|---|---|---|---|
| R04-1 | One core task starves / misses 80ms publish | Scheduling, WG-task preemption | `both_in=false` | SF-1 STOP (send nothing) | `CORE_PUBLISH_TIMEOUT` `:881`, mismatch counter | safety tasks at prio 8 above WG `:1131` | Safe-Det | 4/2/2 | — | Monitor `pstop_mismatch` climb as a health signal |
| R04-2 | Stale `g_done` give satisfies next tick prematurely | Race (late publish) | comparator memcmps stale buffer | could compare wrong-tick data | pre-drain of both semaphores `:873-874` | explicit take-0 before notify | Safe-Det | 4/1/3 | correctness depends on drain ordering | Assert each take corresponds to this-tick encode |
| R04-3 | **RAM fault flips STOP→OK in `g_encoded[0][i]` after memcmp, before `sess_sendto`** | Random RAM/SEU | transmitted message differs from compared message | SF-2 window | CRC over [0..37] now stale → machine rejects INVALID_CHECKSUM → no state change | machine default-STOP, next-tick resend, heartbeat | Dang-Det | 4/1/3 | single-tick STOP could be lost if machine already OK; recovered next tick | Send the *compared* buffer via a read-once + re-verify, or CRC-check just before send |
| R04-4 | Comparator task itself hangs/deadlocks | Systematic SW / socket block | no sends | SF-1 STOP (machine timeout) | none in-remote; machine heartbeat | non-blocking socket discipline `:437`; TWDT (`dcs_safety.c`) covers CPU hang not logic hang | Safe-Det | 4/2/2 | a *logically* wedged-but-scheduled comparator is not TWDT-visible; machine timeout still saves it | Machine-side liveness is the backstop — keep heartbeat mandatory |
| R04-5 | `memcmp` returns 0 on non-equal (miscompiled/short len) | Systematic SW | divergence missed | SF-2 | none | uses `PSTOP_MESSAGE_SIZE` length | Dang-Undet | 5/1/4 | trust in libc memcmp; length constant correct (40) | Unit-test comparator with injected 1-byte diff at each offset |

### F-R-05 / F-R-06 — Encode + black-channel round-trip (`main.c:409-423`, `:724-794`)

| FM ID | Failure mode | Cause | Local effect | System effect (SF) | Existing detection | Existing mitigation | Class | S/O/D | Residual gap | Candidate requirement |
|---|---|---|---|---|---|---|---|---|---|---|
| R05-1 | Systematic encode bug produces identical wrong bytes on both cores | Systematic SW in `pstop_message_encode` (shared, pre-qualified) | both encodings identical-but-wrong → **agree** | SF-2 if the wrong byte is the message field | memcmp cannot catch (identical) | `[PQ]` pstop_c coverage/CI | Dang-Undet | 4/1/4 | Option B does **not** diversify encoding; lockstep is blind to common encode faults | Interface req F-P-01: layout/CRC-span unaltered; add a second independent encoder image on one core for the message byte |
| R06-1 | Remote adopts spoofed/replayed reply counter unconditionally (`:779`) | Comms (on-tunnel spoof/replay) | remote echoes attacker counter to machine | machine sees wrong `received_counter` → MSG_LOST → **no OK** | src IP/port check `:741`; CRC check `:746`; machine echo validation (F-P-04) | fail-safe direction (tends STOP) | Safe-Undet | 3/1/3 | black-channel confidentiality assumed (WG/Tailscale); no app-layer replay window on the reply path | Document black-channel integrity assumption; consider reply counter-monotonic guard |
| R06-2 | `sess_send_period_ms` adopts hostile `heartbeat_timeout` | Comms | send rate changed | bounded | clamp to [TICK_MS, 1000ms] `:489-495` | clamp | Safe-Det | 2/1/2 | — | — |
| R06-3 | Source-bound socket lost when VPN drops → plaintext fall-through | Config/transport | — (prevented) | — | `sess_ensure_socket` holds session dark when VPN IP=0 `:572-579` | source-bind = sendto fails, not fails-open `:568` | Safe-Det | 4/2/2 | — | Keep source-binding invariant under test (2026-07-20 regression) |

### F-R-07 — Network transport (`dcs_net_liveness.c`, `dcs_net_*`)

| FM ID | Failure mode | Cause | Local effect | System effect (SF) | Existing detection | Existing mitigation | Class | S/O/D | Residual gap | Candidate requirement |
|---|---|---|---|---|---|---|---|---|---|---|
| R07-1 | lwIP stack wedged (scheduler alive) | Systematic SW | no packets flow | SF-1 STOP (machine timeout) + self-reboot recovery | gateway-ping + pstop cross-check `dcs_net_liveness.c:288-331` | `abort()`+reboot, not rollback-counted | Safe-Det | 4/2/3 | watchdog only arms after pstop bonded (`ps_last>0`) — an *never-bonded* wedge stays up but machine already STOP | Liveness is availability, not safety; keep machine timeout authoritative |
| R07-2 | Liveness watchdog false-aborts a healthy chip | Systematic (ICMP rate-limit) | spurious reboot → brief STOP | Availability loss, **fail-safe** | dual arm (gateway AND pstop) `:311-319` | reboot not counted to rollback | Safe-Det | 2/2/2 | — | — |

### F-R-08 — Status indication (`dcs_pstop_ring.c`) — non-safety, must be non-interfering

| FM ID | Failure mode | Cause | Local effect | System effect (SF) | Existing detection | Existing mitigation | Class | S/O/D | Residual gap | Candidate requirement |
|---|---|---|---|---|---|---|---|---|---|---|
| R08-1 | Ring shows OK while device commands STOP | Systematic SW (display logic) | operator misled | no actuation effect (display only) | operator cross-check | reads published telemetry only, no verdict path write | Safe-Undet | 3/2/4 | a misleading indicator can defeat operator supervision (a PL e assumption) | Prove ring cannot read/write the verdict path; treat indicator integrity per HARA supervision credit |
| R08-2 | Locate/OTA spinner masks safety colour indefinitely | Systematic | STOP/OK colour hidden | display only | auto-expire `DCS_RING_LOCATE_TIMEOUT_MS` `:518` | bounded mask | Safe-Det | 2/2/2 | — | — |

### F-R-09 — Boot / NVS / rollback (`dcs_safety.c`)

| FM ID | Failure mode | Cause | Local effect | System effect (SF) | Existing detection | Existing mitigation | Class | S/O/D | Residual gap | Candidate requirement |
|---|---|---|---|---|---|---|---|---|---|---|
| R09-1 | NVS peer-slot config corrupted | Flash wear / bit-rot | wrong/absent machine target | session dark → machine STOP; or points at wrong machine | none on peer-slot integrity | fail-safe (no session = STOP) | Dang-Det | 3/2/3 | a *valid-but-wrong* machine_id bonds a machine that should not be armed by this remote | CRC/version the NVS peer slots; reject on mismatch → dark |
| R09-2 | Rapid-boot rollback bricks both partitions | Systematic | device down | STOP (no sends) | boot-count ladder `:72`; both-invalid guard `:88` | refuse-to-brick `:88-101` | Safe-Det | 3/1/2 | — | — |
| R09-3 | Boot loop from genuine code fault masked as "network" abort | Systematic (mis-tagged reset) | rollback ladder not advanced | delayed rollback of a bad image | `was_liveness_abort` consumed once `:45-46` | flag single-shot | Dang-Det | 3/1/3 | a code fault that also happens to abort via liveness path could dodge the counter once | Ensure only the liveness path can set the magic; audit all `abort()` sites |

### F-H-01..05 — Host machine (`host/machine_app_runner.c`)

| FM ID | Failure mode | Cause | Local effect | System effect (SF) | Existing detection | Existing mitigation | Class | S/O/D | Residual gap | Candidate requirement |
|---|---|---|---|---|---|---|---|---|---|---|
| H01-1 | Non-BOND from unknown/timed-out remote dereferenced in upstream | Systematic SW (upstream bug) | crash | process death → all remotes STOP | wrapper filters `:752-757` before library | drop non-BOND from unknown | Safe-Det | 4/1/2 | — | Interface req F-P-02: keep the pre-dispatch guard |
| H02-1 | `min_stop_ms` set to 0 in `machine.toml` | **Config (no validation)** | arming delay disabled → a STOP→OK transient arms | **SF-3 breach** | none — `cfg_load` uses raw `parse_uint`, **no floor** `:240-241` | operator discipline only | **Dang-Undet** | 5/2/4 | host runner has **no safety-floor validation** (ROS2 node does: `kMinStopFloorMs=100`) | Enforce a compiled min-stop floor in the host runner; reject config below it |
| H02-2 | `max_missed_heartbeats` set very high, or `default_heartbeat_ms` huge | **Config (no validation)** | heartbeat timeout → minutes | **SF-1 latency breach** (silence not caught in time) | none — unbounded `parse_uint` `:228,236` | pstop_c constants exist but not enforced here | **Dang-Undet** | 5/2/4 | no clamp to `PSTOP_MIN/MAX_HEARTBEAT`; comment `:721` even mis-states timeout as `hb×(max_missed+1)` (actual is `hb×max_missed`, machine.c:298) | Validate timing against a compiled envelope (mirror ROS2 `validate_timing`); correct the stale comment |
| H02-3 | Early-OK propagated before policy commit | Systematic SW | spurious arm | (blocked) | raw `status_cb(OK)` held; committed only via `robot_status_commit_ok` after STOPPED→OK `:365-379,834-844` | latch + library native `delay_between_stop_ms` (#59) | Safe-Det | 4/1/2 | double-guard (wrapper + library) | Keep both guards; test the latch |
| H02-4 | `remote_details_cb` returns `stop_only=false` for a **non-operator** (a remote absent from the machine's operator allowlist) | **Config: operator allowlist mis-set** / shell default wrong (same obligation on host `machine.toml`, ROS param, and `machn` `/api/operators`) | that remote is admitted as an **operator** → it may perform the STOP→OK re-arm | **SF-3 breach: unauthorized re-arm** (a stop-only/non-operator remote resumes the machine — HARA H-13) | no online diagnostic — the certified gate trusts the shell-supplied `is_stop_only` (`machine.c:16,31`); caught only by commissioning **config review** + the upstream stop-only gate tests (`machine_test.c:677,1165`) | **default `stop_only=true` + empty operator allowlist** (out of the box every remote is stop-only); certified gate `machine.c:135-142` refuses STOP→OK ownership when `is_stop_only==true`; the same remote's STOP still stops (`:131,155-156`) and it is heartbeat-monitored (`:266-320`) | Dang-Det | 5/1/3 | a *valid-but-wrong* allowlist entry (a genuine non-operator deliberately listed) is not machine-detectable — rests on config discipline | **SR-SYS-09**; commissioning review of the operator allowlist; per-machine operator-list config-integrity check |
| H03-1 | `machine_now_ms` (CLOCK_MONOTONIC) frozen | Silicon/kernel | `check_heartbeats` sees `diff=0` → never times out | **SF-1 breach: silence undetected** | none (`now<=last_timestamp` path just skips, machine.c:282) | monotonic clock assumed sound | **Dang-Undet** | 5/1/5 | F-P-03 obligation: "supply a correct `get_time_cb`; never freeze it" — no independent clock check | Independent clock sanity (compare two time sources) or external watchdog on the machine host |
| H05-1 | Many-to-one OR aggregation fails to STOP on one remote's STOP | Systematic SW (library) | one remote's STOP lost | SF-1 breach | `[PQ]` pstop_c `handle_stop_msg`/`machine_stop_robot` (machine.c:127-156) | fail-safe OR is a library property | Dang-Det | 5/1/3 | out of scope internally (pre-qualified); interface only | F-P interface: verify OR semantics at integration (multi-remote E2E) |
| H04-1 | Announce thread config injects into safety path | Config/comms | — | none (separate thread, log-only) | isolated `:484-601` | outside safety loop | Safe-Undet | 1/1/2 | — | Confirm non-interference in review |

### F-M-01..08 — ROS2 machine (`ros2/protective_stop_machine/`)

| FM ID | Failure mode | Cause | Local effect | System effect (SF) | Existing detection | Existing mitigation | Class | S/O/D | Residual gap | Candidate requirement |
|---|---|---|---|---|---|---|---|---|---|---|
| M01-1 | Error transition leaks live publish timer | Systematic SW | stale publishes after teardown | misleading state, no actuation | `on_error` cancels+resets timer `:220`; backend stopped | explicit teardown, one UNSTABLE emitted | Safe-Det | 3/1/2 | — | — |
| M02-1 | `build_backend` selects wrong backend | Config | wrong observation source | fail on unknown → configure FAILURE `:121` | validated string | default software | Safe-Det | 2/1/2 | — | — |
| M03-1 | Software backend `cb_status` no-op + state from `robot_state` | Design | relies entirely on library min-stop native enforcement | if `delay_between_stop_ms`=0 → transient arms | ROS `validate_timing` floor 100ms `:84` blocks 0 | node-level floor | Safe-Det | 4/1/3 | software backend has **no physical relay** (`relay.applicable=false` `:199`) — actuation is a downstream ROS consumer's duty | State the actuation boundary explicitly; downstream consumer must treat STOP/UNSTABLE as de-energize |
| M03-2 | Second concurrent software backend clobbers `g_impl` | Systematic SW | callback context corruption | refused: `start()` returns false `:103` | file-scope guard | single-instance refusal | Safe-Det | 3/1/2 | — | — |
| M04-1 | `/state.json` unreachable / HTTP fail | Comms | no fresh state | `reachable=false` → UNSTABLE; diag ERROR "ROS blind" `:286` | curl status check `:74`; parse check | ESP32 `machn` enforces STOP **independently** | Safe-Det | 4/2/2 | ROS is **observation-only** on hardware backend; safety rests on `machn` | Keep ESP32 relay enforcement authoritative; ROS must never be in the actuation loop |
| M04-2 | `relay_stop` key missing/garbled in JSON | Comms/parse | — | defaults **true** (STOP) `hardware_backend.cpp:119` | `bool_at("relay_stop", true)` fail-safe default | safe default | Safe-Det | 3/2/2 | — | — |
| M05-1 | Deeply-nested hostile JSON overflows stack | Comms (compromised device) | crash | node down → observation lost (machn still enforces) | depth cap 32 `json_lite.hpp:87,97` | bounded recursion | Safe-Det | 3/1/2 | — | — |
| M05-2 | Tolerant number/string parse mis-reads a field | Systematic SW | wrong numeric telemetry | display/diag only (relay_stop is bool, defaults safe) | — | safe defaults on the safety-relevant bool | Safe-Undet | 2/2/3 | number parser accepts `1.2.3`-style junk `:185-198` | Constrain parser or validate the specific fields consumed |
| M07-1 | Runtime timing param loosens envelope | Config | longer timeout / shorter min-stop | (blocked) | `validate_timing` on set-param and service `:305-342` | compiled floor envelope `:28-35` | Safe-Det | 4/1/2 | envelope only on ROS2 path, **not** host runner (see H02) | Unify the validation envelope across host + ROS |
| M06-1 | Publish tick reads torn snapshot | Race | inconsistent published fields | display/diag only | mutex-guarded `snapshot()` `software_backend.cpp:235` | lock | Safe-Undet | 2/1/3 | — | — |
| M08-1 | Diagnostics under-reports a relay feedback fault | Systematic SW | fault not surfaced to ROS | observation gap (machn still STOPs) | `diagnostics()` maps `fault_a/b` `:289` | reads snapshot | Safe-Undet | 3/1/3 | ROS diag is advisory | — |

### F-P-01..04 — Pre-qualified `pstop_c` interface obligations (referenced, not re-verified)

| FM ID | Interface obligation | If the app shell violates it | System effect (SF) | Where the shell must hold the line | Class if violated | Candidate requirement |
|---|---|---|---|---|---|---|
| P01-1 | 40-byte layout + CRC-16 over bytes **[0..37]** (`pstop_msg.c:238,254`; size=40 `config.h:12`) | shell alters layout/CRC span → machine mis-validates | SF-2/SF-1 | remote encode `main.c:422`, decode `:745`; never repack | **Dang-Undet** | Freeze wire layout; golden-vector test both ends |
| P02-1 | Machine dispatch **default→STOP** (`machine.c:196-201`) | shell adds a path that answers OK on unknown | SF-2 | shell only forwards to `machine_process_message` | **Dang-Undet** | Assert every non-OK/BOND/UNBOND ⇒ STOP at integration |
| P03-1 | Correct, never-frozen `get_time_cb` on machine monotonic clock (`machine.c:218,269`) | frozen/backward clock → heartbeat check disabled | SF-1 (see H03-1) | `machine_now_ms`/`now_ms` on CLOCK_MONOTONIC | **Dang-Undet** | Independent clock cross-check |
| P04-1 | Counter/stamp echo + MSG_LOST/OUT_OF_ORDER (`machine.c` seq checks) | shell spoofs/bypasses echo | SF-2 (replay-to-run) | remote must not fabricate echo `main.c:767,779` | Dang-Det | Never synthesize `received_counter`; integration replay test |

---

## 3. Dangerous-Undetected (DU) register

These rows dominate the SIL 3 case. DU = the fault moves away from the safe
state (toward spurious RUN, or defeats a stop) **and** no on-line diagnostic
forces the safe reaction.

| DU ID | Function | Failure mode | Why undetected | Does Option A/B compensate? | S/O/D | Priority |
|---|---|---|---|---|---|---|
| **DU-1** | F-R-01 (R01-3) | Lost pull-down → open loop reads as closed → **false OK** | GPIO config set once at boot, never re-verified; the "config-integrity check" in design §6/§10#8 **is not implemented** | **No.** Option A trusts the live read; if the *sensor path* lies, the fresh sample is a false positive. Option B does not read the pad config. | 5/2/5 | **Highest** |
| **DU-2** | F-H-03 / F-P-03 (H03-1) | Machine `get_time_cb` frozen → remote silence never times out | `check_heartbeats` skips when `now<=last_timestamp` (machine.c:282); no independent clock check | No — clock is upstream of the verdict entirely | 5/1/5 | **Highest** |
| **DU-3** | F-R-02 (R02-3) | Compiler collapses the two diverse verdict expressions to identical code → common codegen fault agrees | lockstep memcmp passes on identical (wrong) output | **Partially self-defeating.** Option B's diversity is source-level only; single toolchain/ISA. The compensation for `OK==0` polarity leans on this diversity that the compiler may erase. | 4/2/4 | High |
| **DU-4** | F-H-02 (H02-1/2) | `machine.toml` sets `min_stop_ms=0` or huge heartbeat/`max_missed` | host runner performs **no** safety-floor validation (unlike ROS2 node) | N/A — config layer, upstream of A/B | 5/2/4 | High |
| **DU-5** | F-R-05 / F-P-01 (R05-1) | Systematic `pstop_message_encode` fault → identical wrong bytes on both cores | Option B diversifies the verdict *selection* but **not** the encode; memcmp blind to identical faults | No — encode is shared, pre-qualified but common-mode | 4/1/4 | High |
| **DU-6** | F-R-01 (R01-4) | Both pull-downs lost together (brownout/ESD/shared mux bug) → both cores false-OK and agree | common-cause defeats the cross-check (β≈1 on shared config path) | No | 5/1/5 | High |
| **DU-7** | F-R-04 (R04-5) | `memcmp` mis-returns equal for non-equal buffers | trust in libc; no positive-diff self-test | No — comparator is the diagnostic itself | 5/1/4 | Medium-High |
| **DU-8** | F-R-01 (R01-5/6) | Settle-time too short / stale GPIO read → this-tick sample not truly fresh | Option A assumes the read reflects *this* drive | Undermines Option A's premise if HW timing is off | 4/2/4 | Medium |
| **DU-9** | F-M-05 (M05-2) | Tolerant JSON parser mis-reads a consumed field | no schema validation | N/A (observation path; `relay_stop` bool defaults safe, limits blast radius) | 2/2/3 | Low |

**On the inherited `OK==0x00` fail-danger polarity:** an all-zeros artefact
decodes toward OK. The compensating measure (SYSTEM_DEFINITION §5) is the
Option A live-sample derivation: OK is only emitted when *this tick's* physical
both-phase read matches the driven level (`main.c:281-308`). That fully
addresses the **generation-side** danger — a zeroed flag, a latched state, or a
skipped branch cannot manufacture OK, and an all-zeros packet on the wire is
rejected by CRC at the machine. It does **not** address (a) a **sensor path
that physically lies** (DU-1/DU-6 — the live read is a false positive), (b)
**common-mode faults downstream of verdict selection** (encode DU-5, comparator
DU-7, the non-diverse `estop_primed` gate R03-1), or (c) **erosion of the
Option B diversity by the toolchain** (DU-3). Net: Option A/B compensate the
polarity for the fault classes they were scoped to (stuck/latched/interpretation
of the reads) and **do not** constitute a general defence against the fail-
danger polarity. A far-Hamming OK/STOP codeword upstream in `pstop_c` would
retire the polarity concern structurally; the code is written to survive that
change (the physical image is only a table index, `main.c:288`).

---

## 4. Common-cause / systematic analysis

**Does Option B actually break dual-core common-cause?** **Partially, and only
for one narrow fault class.** Option B diversifies *the expression that selects
the OK/STOP codeword from the two reads* (core0 arithmetic-image
`k_estop_msg[((rb_hi^1)|rb_lo)&1]` vs core1 boolean `(rb_hi==1)&&(rb_lo==0)`,
`main.c:304-308`). That genuinely catches a systematic misinterpretation of the
read variables in one expression. **It does not** provide:

- **Compiler/ISA diversity.** Both expressions are compiled by one toolchain
  for two identical Xtensa cores. The comment itself concedes they are
  "logically identical when correct." A modern optimizer may emit identical
  machine code → diversity erased (**DU-3**). This is the weakest link in the
  Option B claim and should be either build-gated (disassemble-and-diff) or
  made true structural diversity (separate translation units / flags, ideally a
  second implementation).
- **Diversity across the shared surface.** Everything after codeword selection
  is byte-identical code on both cores: the STOP-only override/debounce block
  (`:317-347`), `pstop_message_encode` (`:422`), the per-slot field assembly
  (`:409-423`). β≈1 there. The override block is STOP-biased (safe direction),
  but **encode is not** (DU-5).
- **Non-diverse singletons.** `estop_primed()` (`:359`), the comparator/memcmp
  (`:890`), the boot-priming send gate (`:903`), and the machine-side clock
  (H03-1) are single instances with no redundancy at all.

**Where β≈1 (identical code path, no diversity):** the override/debounce block;
message encode; comparator memcmp; `estop_primed`; the entire machine-side
(host/ROS) processing (single-threaded, single copy) — machine redundancy is
achieved by the *series relay chain on the `machn` device*, not by the app.

**Specific common-cause vectors requested:**

- **Boot transient.** The first loop samples glitch open on this board; the
  boot-priming hold (`estop_primed`, `LOOP_BOOT_OPEN_CONFIRM_TICKS`) suppresses
  the artefact STOP→OK so it cannot auto-arm (SF-3). Correct — **but the gate is
  a single non-diverse function** (R03-1); SF-3 also rests on machine-side
  `min_stop_ms`. Two independent barriers, one of which (host runner) can be
  config-disabled (**DU-4**).
- **NVS corruption.** Peer slots are not integrity-checked (R09-1). Fail-safe if
  a slot goes absent (session dark → STOP), but a *valid-but-wrong* `machine_id`
  is a silent mis-target. Boot-count NVS is guarded against bricking (`:88`).
- **Clock / `get_time_cb`.** Machine monotonic clock is the sole liveness time
  base by deliberate design (never anchored to remote stamp — correct, else a
  silent remote would freeze the watchdog). A frozen local clock is **DU-2**
  with no cross-check.
- **Relay weld (ESP32 `machn`, hardware-backend actuator).**
  **[DESCOPED 2026-08 — relay feedback OFF by default, pending new machine
  hardware; REVERSIBLE via `CONFIG_MACHN_RELAY_FEEDBACK`. See
  docs/RELAY_FEEDBACK_DESCOPE.md.** The series two-relay de-energize-to-safe stop
  (HFT=1, either contact opens the chain) is UNCHANGED and still safe on demand.
  What is descoped is the resistor-divider **feedback/diagnosis** below: a single
  weld is now **latent (dangerous-undetected)** until the next stop demand, and
  the ~1 s stop-on-contradiction no longer fires. FMEDA MC-2 DC credit is stale
  pending recompute (§FMEDA). Compensating measure: periodic commanded-open
  proof test (see the double-weld recommendation at the end of this bullet).]**
  Two relay contacts
  are **wired in series** in the stop circuit and each core drives its own coil
  from its own verdict (`machn/main/main.c:19-25,65-68`). A single welded
  contact still lets the other open the series chain → load de-energizes (safe).
  A resistor-divider feedback per contact detects commanded-vs-observed
  contradiction and, after `RELAY_FAULT_STOP_TICKS` (~1 s), forces STOPPED. The
  residual DU is a **double weld** (both contacts welded closed) — the series
  chain can no longer open; feedback would show a contradiction only if a core
  *commands* open, so a double weld while commanded-closed is latent until the
  next stop demand. Recommend periodic proof-test (commanded open cycle) to
  reveal a latent double weld — this is the classic PL e proof-test-interval
  requirement.
- **Network black-channel spoof/replay.** Confidentiality/integrity are provided
  by WireGuard/Tailscale (out of scope), plus app-layer CRC-16, per-session src
  IP/port filtering (`:741`), and `pstop_c` counter/stamp echo + MSG_LOST/
  OUT_OF_ORDER (F-P-04). All identified spoof/replay effects push the system
  toward STOP (fail-safe), so this is Safe-Undet, contingent on the black-
  channel assumption being stated as a safety requirement.

**Systematic-capability note (IEC 61508-3):** the dominant systematic risk is
**shared source code across the two cores** (single-version programming with
cosmetic expression diversity), compiled by a single toolchain. For a SIL 3
claim this needs either genuine N-version diversity on the safety decision or a
strong argument (MC/DC + toolchain qualification + object-code diff) that the
residual systematic capability is adequate. The current Option B, as written,
is **not** by itself sufficient evidence of common-cause independence.

---

## 5. Top findings (ranked)

1. **DU-1 — Lost GPIO pull-down reads as a closed loop → false OK, no runtime
   detection (F-R-01).** The single most dangerous gap: the pad configuration is
   set once at `estop_init` and never re-verified, yet `PSTOP_SAFETY_DESIGN.md`
   §6 and §10 item 8 both claim a runtime "config-integrity check" that **does
   not exist in the code**. Add a periodic config-register read-back plus a
   drive-low-must-read-0 self-test on both channels.
2. **DU-2 / F-P-03 — Frozen machine clock disables the entire heartbeat
   watchdog (F-H-03).** The whole liveness case rests on one monotonic clock
   with no independent cross-check; `check_heartbeats` silently skips when time
   does not advance. Add a second time source or an external hardware watchdog
   on the machine host.
3. **DU-4 — Host runner accepts unsafe timing config (F-H-02).** `machine.toml`
   can set `min_stop_ms=0` (defeats SF-3 arming) or an arbitrarily long
   heartbeat/`max_missed` (defeats SF-1 latency), because the host runner does
   **no** safety-floor validation — while the ROS2 node does. Port the ROS2
   `validate_timing` envelope into the host runner. (Also: the timeout comment
   at `machine_app_runner.c:721` mis-states the formula as `hb×(max_missed+1)`;
   the library uses `hb×max_missed`.)
4. **DU-3 — Option B diversity is erasable by the compiler (F-R-02).** The two
   "diverse" verdict expressions are logically identical and share one toolchain
   and ISA; an optimizer may collapse them, and the shared code surface after
   codeword selection is β≈1. Option B, as written, is not sufficient
   common-cause evidence for SIL 3. Build-gate an object-code diff or introduce
   real structural diversity.
5. **DU-5 / DU-7 — Lockstep is blind to common-mode faults in its own shared
   code (F-R-04/05).** A systematic `pstop_message_encode` bug (DU-5) or a
   `memcmp` that mis-returns equal (DU-7) produces identical wrong output on
   both cores and passes the comparator. Add golden-vector encode tests and a
   comparator positive-diff self-test (inject a 1-byte diff at every offset).

**Latent-fault proof-test flag (ISO 13849 / PL e):** the **double relay weld**
on the `machn` actuator (§4) is a latent dangerous fault revealed only by a
commanded-open cycle — specify a proof-test interval.

**Doc-vs-code inconsistencies found (trust the code):**
- §6/§10#8 assert a runtime GPIO "config-integrity check" — **not implemented**
  (root of DU-1).
- §6 attributes replay/stale-packet detection to a "stamp signature" — that was
  **Option C, dropped**; actual protection is `pstop_c` counter/stamp echo +
  MSG_LOST (F-P-04) over a CRC/black channel.
- §6/§10 "challenge" language reflects the dropped unpredictable-challenge
  design; the code uses deterministic both-phase sampling (Option A), which is
  reproducible by a same-firmware fault — recorded as a residual, not a control.
- `machine_app_runner.c:721` heartbeat-timeout comment (`hb×(max_missed+1)`)
  contradicts the library math and SYSTEM_DEFINITION (`hb×max_missed`).

---

*End of first draft. Every **Dang-Undet** row and the top-5 findings require
safety-lead disposition before this feeds the requirements set and the FMEDA.*

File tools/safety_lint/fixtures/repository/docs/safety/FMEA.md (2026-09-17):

<!-- SPDX-FileCopyrightText: 2026 Polymath Robotics, Inc. -->
<!-- SPDX-License-Identifier: Apache-2.0 -->

# FMEA

DU-1

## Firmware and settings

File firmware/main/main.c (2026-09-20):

// SPDX-FileCopyrightText: 2026 Polymath Robotics
// SPDX-License-Identifier: Apache-2.0

/**
 * @file main.c
 * @brief Dual-Core Safety — lockstep pstop client, one remote to up to
 * PSTOP_MAX_MACHINES machines.
 *
 * Two pinned tasks on cores 0 and 1 each independently build the SAME
 * outgoing pstop_msg_t per bonded machine and encode each to a 40-byte
 * buffer. A comparator task does a bytewise memcmp of the two encodings
 * for every machine; only if ALL agree does it transmit anything this
 * tick. Disagreement → send nothing to anyone → every machine's heartbeat
 * times out → STOP. Lockstep integrity is a property of the DEVICE, not
 * of one link, so a single mismatch silences all sessions.
 *
 * The whole `pstop_msg_t` is compared, including the CRC, so the safety
 * check catches RAM/cache/ALU corruption during encoding — not just a
 * mismatch in the OK/STOP verdict.
 *
 * Machines are independent sessions: each has its own socket (so egress
 * binding is per peer type), its own pstop_c protocol_data_t counter
 * state, its own non-blocking bond state machine and its own reply-loss
 * watchdog. One unreachable machine NEVER stalls heartbeats to the
 * others — the mirror of the machine side's many-remote fail-safe OR.
 * The arming gesture (STOP→OK) is broadcast: one press-and-release arms
 * every bonded machine; each machine still enforces its own min_stop_ms
 * veto.
 *
 * Everything *not* part of the safety pattern (HTTP admin UI, OTA-rollback
 * ladder, NVS, telemetry, network-liveness watchdog, USB/WiFi boot path)
 * lives in components/dcs_support/.
 *
 * Modelled on pstop_c/examples/client/client_app.c:
 *   bond per machine → loop send_msg(verdict) → never unbond.
 */

#include <stdatomic.h>
#include <stdbool.h>
#include <stdint.h>
#include <string.h>

#include "dcs_identity.h"
#include "dcs_support.h"
#include "driver/gpio.h"
#include "esp_log.h"
#include "esp_rom_sys.h"
#include "esp_system.h"
#include "esp_task_wdt.h"
#include "esp_timer.h"
#include "estop_verdict.h"
#include "freertos/FreeRTOS.h"
#include "freertos/semphr.h"
#include "freertos/task.h"
#include "hal/gpio_ll.h" /* gpio_ll_get_io_config — pad-config read-back (SR-R-09) */
#include "lockstep_window.h"
#include "lwip/sockets.h"
#include "pstop/protocol_data.h"
#include "pstop/pstop_msg.h"
#include "pstop_aux_channel.h"
#include "soc/gpio_struct.h" /* GPIO peripheral instance for gpio_ll_* */

/* ============================================================================
 * Configuration
 * ========================================================================== */

#define TICK_HZ 10
#define TICK_MS (1000u / TICK_HZ)
#define TICK_PERIOD pdMS_TO_TICKS(1000 / TICK_HZ)

/* === Machine-governed heartbeat rate =======================================
 * The MACHINE decides the update rate its safety case needs: pstop_c puts the
 * per-operator heartbeat_ms (machine.toml: default_heartbeat_ms / per-operator
 * heartbeat_ms) into the heartbeat_timeout field of every reply, including
 * the bond ack (machine.c: resp->heartbeat_timeout = remote_data.heartbeat_ms;
 * the field is only valid machine→operator). The remote adopts it per session:
 * it transmits every heartbeat_timeout/2 (2x margin, so normal jitter can
 * never cost the machine a whole heartbeat window), clamped between the 10 Hz
 * lockstep tick (the E-stop sampling cadence is a safety property and never
 * slows down) and PSTOP_MAX_SEND_PERIOD_MS. Sends are DECIMATED ticks — the
 * per-session counter advances only on transmitting ticks, so the machine
 * sees contiguous counters (protocol.c rejects gaps > max_lost_messages+1).
 * A reply carrying heartbeat_timeout=0 (reject paths) changes nothing. */
#define PSTOP_MAX_SEND_PERIOD_MS 1000u

/* Each core publishes its encoded buffers within 80 ms of the tick. If a core
 * doesn't, treat that tick as a mismatch (send nothing). 80ms leaves the
 * comparator 20ms of slack to drain RX and re-align to vTaskDelayUntil's
 * 100ms tick — and gives the cores enough headroom that being briefly
 * preempted by ml_wg_mgr or httpd doesn't cause spurious mismatches. */
#define CORE_PUBLISH_TIMEOUT pdMS_TO_TICKS(80)

/* Machine sessions. Must not exceed DCS_PSTOP_MAX_MACHINES (the telemetry
 * and peer-slot plumbing in dcs_support is sized to it). */
#define PSTOP_MAX_MACHINES DCS_PSTOP_MAX_MACHINES

/* Local UDP source ports: slot i binds PSTOP_LOCAL_PORT + i (8891..8894).
 * One socket per machine keeps the reply path trivially demultiplexed and
 * lets each socket carry its own egress binding (VPN vs LAN). */
#define PSTOP_LOCAL_PORT 8891

#define HEARTBEAT_TIMEOUT_MS 1000u

/* Reply-loss watchdog, per session. If a machine stops replying for longer
 * than this, that link has desynced and won't recover on its own — re-bond
 * that session to re-sync counters. Other sessions are untouched.
 *
 * MUST exceed the machine's heartbeat timeout + jitter, so the remote only
 * tears the session AFTER machn would itself have dropped the bond — never on
 * a sub-timeout reply blip. That timeout is `heartbeat_ms × max_missed`
 * = 400 × 5 = 2000 ms with today's defaults (max_missed raised 3→5 on
 * 2026-08-04). The old value (1500 ms) was set against the legacy 1000 ms
 * timeout and was NOT updated with max_missed, so it dropped BELOW the machine
 * timeout: a ~1.6 s reply lag (e.g. a peer-join X25519/DISCO crypto burst
 * time-sharing the wg_mgr decrypt task) forced a nuisance rebond even though
 * machn still held the bond.
 *
 * This constant is only the FLOOR. A hard-coded 2500 ms held the invariant
 * for the 400 ms default alone; the actual threshold is derived per session
 * from the machine-adopted heartbeat in sess_rebond_after_ms() so any
 * configured heartbeat keeps the remote's watchdog above the machine's.
 * The floor also covers the pre-first-reply state (heartbeat not yet
 * learned). Safety is unaffected — machn's heartbeat timeout remains the
 * STOP authority; this only governs connectivity re-sync. */
#define REBOND_AFTER_MS 2500u

/* Missed-heartbeat multiplier in the machine's bond-drop timeout. max_missed
 * is NOT advertised on the wire (replies carry only heartbeat_timeout), so
 * this is a hard-coded coupling to machn's MACHN_MAX_MISSED_HEARTBEATS = 5
 * (machn/main/main.c) — if that constant changes, this one MUST change with
 * it. Long-term fix: advertise the machine's absolute timeout in the reply
 * instead of making the remote reconstruct it. */
#define REBOND_MACHINE_MAX_MISSED 5u
#define REBOND_JITTER_MARGIN_MS 500u

/* Bond handshake, per session: one BOND in flight at a time; retry after
 * this long without a reply. Long spacing means we never have more than one
 * BOND outstanding — critical because the pstop protocol rejects duplicate
 * counters with MSG_LOST once a client is registered — and is long enough
 * that the machine's check_heartbeats can age out a half-bonded stale
 * client between attempts. */
#define BOND_RETRY_MS 5000u

/* How long the comparator waits for the first reply after a send burst.
 * Bounded so the 10 Hz tick always holds. */
#define REPLY_WAIT_MS 50

static const char * TAG = "dcs_main";

/* Last message TYPE received from a machine, aggregated worst-of across
 * bonded sessions (STOP beats BOND/UNBOND beats OK), published for the LED
 * ring's legacy consumers and /state.json. The ring's per-segment display
 * reads the per-machine arrays instead. */
extern atomic_uint_fast32_t g_dcs_pstop_last_msg;
extern atomic_uint_fast32_t g_dcs_pstop_replies;
extern atomic_uint_fast32_t g_dcs_pstop_rebonds;
extern atomic_uint_fast32_t g_dcs_pstop_mm[7]; /* lockstep-mismatch attribution (soak item 5; dcs_internal.h) */
extern atomic_uint_fast32_t g_dcs_pstop_mm_seq; /* seqlock for g_dcs_pstop_mm (odd while being written) */

/* ============================================================================
 * Lockstep state — one tick's worth of inputs for every active session,
 * snapshotted by the comparator before notifying the cores. Cores read this
 * read-only and encode one buffer per active slot.
 * ========================================================================== */

typedef struct
{
  bool active; /* encode this slot this tick (session is BONDED) */
  uint64_t stamp_ms;
  uint32_t counter;
  uint32_t received_counter;
  uint64_t received_stamp;
  uint32_t receiver_id; /* this machine's device id */
  uint8_t role; /* announced role (pstop_aux_role_t), snapshotted per tick so
                 * both cores encode the same value even if /api/role flips
                 * between their encodes (role is live, no reboot) */
} tick_input_t;

static tick_input_t g_tick[PSTOP_MAX_MACHINES];
/* E-stop rolling-level source: advances EVERY tick regardless of which
 * sessions transmit, so the drive-high/drive-low sampling pattern never
 * stalls under send decimation. Written by the comparator before it
 * notifies the cores; read-only for the cores (same discipline as g_tick). */
static uint32_t g_tick_roll;
static uint8_t g_encoded[2][PSTOP_MAX_MACHINES][PSTOP_MESSAGE_SIZE];
static uint8_t g_verdict[2]; /* for telemetry */
static SemaphoreHandle_t g_done[2]; /* core_id → comparator */
static TaskHandle_t g_core_h[2]; /* comparator → core_id */
static atomic_uint_fast64_t g_core_done_us[2]; /* esp_timer stamp of each core's last publish (telemetry) */

/* ============================================================================
 * Dual-channel hardware E-stop loops.
 *
 * Two independent loopback channels run through the two poles of an external
 * DPST normally-closed E-stop switch. Each lockstep core owns ONE channel and
 * reads it independently — this is the cross-check:
 *
 *     core 0 (channel A):  GPIO39 (drive) --> DPST pole 1 --> GPIO40 (sense)
 *     core 1 (channel B):  GPIO41 (drive) --> DPST pole 2 --> GPIO42 (sense)
 *
 * Each tick the owning core drives its OUT pin with a rolling level (the tick
 * counter's LSB) and verifies the echo on its IN pin, which is pulled DOWN so
 * an OPEN loop reads 0:
 *     drive 1, read 0  -> loop OPEN (button pressed) or wire broken
 *     drive 0, read 1  -> IN shorted high
 * The loop counts as CLOSED only when the most recent drive-high echoed high
 * (proves continuity) AND the most recent drive-low echoed low (rules out a
 * stuck-high short). Until BOTH phases have been sampled the channel reads
 * OPEN, so the device is fail-safe (STOP) at boot and the rolling pattern
 * makes a stuck/shorted pin detectable rather than latching a false OK.
 *
 * Pressing the button opens BOTH poles at once: both cores independently reach
 * STOP, agree, and a STOP message is sent. A SINGLE-channel fault (one loop
 * open/short, the other intact) makes the two cores DISAGREE -> the
 * comparator's memcmp fails -> nothing is sent -> every machine heartbeat-
 * times out and stops. No single fault can mask a real stop.
 * ========================================================================== */

#define ESTOP_SETTLE_US 10 /* propagation through the wire + switch contacts */

/* The debounce/boot constants (LOOP_RECLOSE_DEBOUNCE_TICKS,
 * LOOP_BOOT_OPEN_CONFIRM_TICKS), the per-core state struct (estop_state_t), and
 * the verdict/debounce/priming logic now live in estop_verdict.{h,c} so the
 * SIL-critical decision core is host-unit-testable to branch + MC/DC (the
 * on-target Xtensa build can't be gcov'd — JTAG pins ARE the loop pins). See
 * firmware/test/ and docs/safety/COVERAGE.md. */

static const struct
{
  gpio_num_t out;
  gpio_num_t in;
} g_estop_ch[2] = {
  {GPIO_NUM_39, GPIO_NUM_40}, /* core 0 — channel A */
  {GPIO_NUM_41, GPIO_NUM_42}, /* core 1 — channel B */
};

static estop_state_t g_estop_st[2]; /* per-core state; type in estop_verdict.h */

static void estop_init(void)
{
  for (int c = 0; c < 2; c++) {
    gpio_config_t out_cfg = {
      .pin_bit_mask = 1ULL << g_estop_ch[c].out,
      .mode = GPIO_MODE_OUTPUT,
      .pull_up_en = GPIO_PULLUP_DISABLE,
      .pull_down_en = GPIO_PULLDOWN_DISABLE,
      .intr_type = GPIO_INTR_DISABLE,
    };
    gpio_config(&out_cfg);
    gpio_config_t in_cfg = {
      .pin_bit_mask = 1ULL << g_estop_ch[c].in,
      .mode = GPIO_MODE_INPUT,
      .pull_up_en = GPIO_PULLUP_DISABLE,
      .pull_down_en = GPIO_PULLDOWN_ENABLE, /* OPEN loop -> reads 0 -> STOP */
      .intr_type = GPIO_INTR_DISABLE,
    };
    gpio_config(&in_cfg);
    gpio_set_level(g_estop_ch[c].out, 0);
  }
  (void)memset(g_estop_st, 0, sizeof(g_estop_st));
  ESP_LOGI(
    TAG,
    "E-stop loops: chA=GPIO%d->GPIO%d  chB=GPIO%d->GPIO%d",
    g_estop_ch[0].out,
    g_estop_ch[0].in,
    g_estop_ch[1].out,
    g_estop_ch[1].in);
}

/* Drive THIS core's loop with the tick's rolling level, sample the echo, and
 * return true iff the loop is proven closed-and-healthy. Each core touches only
 * its own pin pair, so the two cores never contend. Called exactly ONCE per
 * tick per core — the sampled verdict is then reused for every machine's
 * encoding, so all sessions carry the same tick verdict. */
static uint8_t estop_channel_closed(int core_id, uint32_t counter)
{
  const gpio_num_t out = g_estop_ch[core_id].out;
  const gpio_num_t in = g_estop_ch[core_id].in;
  (void)counter; /* both phases are sampled every tick; no rolling phase */

  /* SAFETY — button integral to the message (external reviewer, 2026-08).
   * Sample BOTH loop phases THIS tick: drive HIGH then LOW, reading each back.
   * A healthy closed loop conducts as driven → rb_hi==1 AND rb_lo==0. */
  gpio_set_level(out, 1);
  esp_rom_delay_us(ESTOP_SETTLE_US);
  const int rb_hi = gpio_get_level(in);
  gpio_set_level(out, 0);
  esp_rom_delay_us(ESTOP_SETTLE_US);
  const int rb_lo = gpio_get_level(in);

  /* Decide the verdict + update debounce/priming in the pure, host-testable
   * core (estop_verdict.c — carries the full safety rationale). This function
   * stays thin HAL glue: drive/read both phases (above), decide, publish. */
  const uint8_t msg = estop_decide(&g_estop_st[core_id], core_id, rb_hi, rb_lo);
  dcs_publish_estop(core_id, g_estop_st[core_id].high_ok, g_estop_st[core_id].low_ok);
  return msg;
}

/* True once BOTH cores have sampled their loop on both rolling phases. The
 * comparator holds off sending until then (see comparator_task), so the
 * one-time boot-priming STOP never reaches any machine. That artifact STOP
 * would otherwise complete the machine's NEED_STOP arming (a STOP->OK cycle)
 * and arm the robot to OK with NO operator action — arming MUST be a deliberate
 * manual press->release. After priming, the only STOP->OK on the wire comes
 * from a real E-stop press then release. (Primed flags latch true for the run,
 * so this gate only affects the ~2-tick startup window.) */
static bool estop_primed(void)
{
  return estop_channels_primed(g_estop_st);
}

/* ============================================================================
 * Safety verdict — each core reads its OWN E-stop channel. OK only while the
 * loop is proven closed; otherwise STOP. The two cores' verdicts are
 * cross-checked downstream by the comparator's byte-compare (disagreement =>
 * send nothing => machines stop), so a per-core read here is the intended
 * design, not a lockstep hazard: identical inputs (both loops closed, or both
 * open) produce identical messages; only a genuine channel split diverges.
 * ========================================================================== */
static uint8_t compute_verdict(uint32_t counter, int core_id)
{
  /* estop_channel_closed now returns the codeword directly (physical-image
   * derived; OK only on a live sample that matched the driven level). */
  return estop_channel_closed(core_id, counter);
}

/* ============================================================================
 * E-stop GPIO pad-config re-verification — SR-R-09 / FMEA DU-1.
 *
 * The E-stop IN pins are configured ONCE in estop_init() as INPUT with the
 * PULL-DOWN ENABLED, so an OPEN loop discharges to 0 and reads STOP. If that
 * pull-down is lost at runtime (an SEU on the IO_MUX config register, a stray
 * pad reconfig, ESD), an open loop FLOATS and can echo 1 on the drive-high
 * phase -> false CLOSED -> false OK, with NO existing runtime detection: this
 * is DU-1, the highest-priority dangerous-undetected gap. PSTOP_SAFETY_DESIGN
 * claimed a runtime "config-integrity check"; the code never had one. This is
 * it.
 *
 * Every ~1 s the comparator reads back each IN pad's configuration registers
 * and confirms the safe setup is intact. Read-back primitive:
 * gpio_ll_get_io_config() (ESP-IDF v5.5 hal/gpio_ll.h) decodes the very
 * IO_MUX/GPIO registers gpio_config() wrote:
 *   .pd = FUN_WPD (IO_MUX pull-down)     MUST be 1  <- the DU-1 bit
 *   .ie = FUN_IE  (IO_MUX input-enable)  MUST be 1  (else the read is dead)
 *   .oe = GPIO output-enable (direction) MUST be 0  (input, not driven output)
 *   .pu = FUN_WPU (IO_MUX pull-up)       MUST be 0  (a pull-UP would actively
 *                                                    hold an open loop CLOSED)
 * Any mismatch latches a STICKY per-channel fault bit; the comparator then
 * fail-safes exactly like the clock cross-check: it halts all pstop TX (every
 * machine heartbeat-times-out to STOP), then after a short STOP-settle grace
 * does a CONTROLLED, CLEAN reset (esp_restart, reset_reason ESP_RST_SW — NOT
 * counted toward the OTA rollback ladder). On reboot estop_init re-writes the
 * pad config, so a TRANSIENT corruption (an SEU-flipped FUN_WPD bit) is
 * recovered; a PERSISTENT hardware fault simply re-trips and loops, and the
 * device stays safely silent (machines STOPped) the whole time. Using our own
 * controlled reset preempts the cores' unfed-TWDT reset (which would otherwise
 * fire ~5 s later as the rollback-counted ESP_RST_TASK_WDT).
 * ========================================================================== */

#define ESTOP_PADCFG_REVERIFY_TICKS 10u /* ~1 s at the 100 ms comparator tick */
#define ESTOP_PADCFG_RESET_GRACE_MS 1500u /* STOP-settle (> heartbeat timeout) before the controlled reset */

/* Sticky bitmask: bit c set once channel c's pad config is seen bad. */
static atomic_uint_fast32_t g_gpio_cfg_fault;

/* True iff this IN pad still holds the safe E-stop config (input + pull-down). */
static bool estop_padcfg_ok(gpio_num_t in)
{
  gpio_io_config_t cfg;
  gpio_ll_get_io_config(&GPIO, (uint32_t)in, &cfg);
  return cfg.pd && cfg.ie && !cfg.oe && !cfg.pu;
}
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
void app_main(void)
{
  dcs_boot_state_t bs = dcs_support_init();

  /* Per-core completion semaphores. Cores give → comparator takes. These
     * allocate from internal heap, which can run as low as ~18 KB when WiFi +
     * USB-NCM + a Tailscale TLS handshake coincide. A silent NULL here would
     * later be passed to xSemaphoreGive/Take in the SAFETY path → assert/panic.
     * Retry briefly to ride out a transient coincident allocation; if the heap
     * is genuinely exhausted, a CLEAN reboot (does NOT count toward rollback)
     * beats a NULL-deref panic (which would). */
  for (int i = 0; (i < 20) && ((g_done[0] == NULL) || (g_done[1] == NULL)); i++) {
    if (g_done[0] == NULL) {
      g_done[0] = xSemaphoreCreateBinary();
    }
    if (g_done[1] == NULL) {
      g_done[1] = xSemaphoreCreateBinary();
    }
    if ((g_done[0] != NULL) && (g_done[1] != NULL)) {
      break;
    }
    vTaskDelay(pdMS_TO_TICKS(100));
  }
  if (!g_done[0] || !g_done[1]) {
    ESP_LOGE(
      TAG,
      "FATAL: g_done semaphore alloc failed (internal heap exhausted) "
      "— cannot run lockstep; clean reboot to retry");
    vTaskDelay(pdMS_TO_TICKS(50));
    esp_restart();
  }

  /* Priority for the safety lockstep tasks. Must sit ABOVE the microlink/
     * Tailscale tasks (ml_net_io & ml_wg_mgr run at prio 7, ml_derp_tx &
     * ml_coord at 5) so the cores always publish their encoding within the
     * comparator's 80 ms window even under sustained WireGuard load. At prio 5
     * (== the old value) the cores were preempted by the prio-7 WG tasks,
     * which showed up as a slow climb in pstop_mismatch (core-publish-timeouts)
     * during Tailscale soaks. These tasks are tiny — compute a verdict, encode,
     * then block — so running them above WG costs the radio path nothing.
     * Stays well below the TCPIP thread (prio 18) the sockets depend on. */
#define SAFETY_TASK_PRIO 8

  /* Bring up the dual-channel E-stop GPIOs before the cores start reading
     * them. Done here (not in dcs_support) because the loops ARE the safety
     * input — they belong with the lockstep, in the auditable file. */
  estop_init();

  /* Spawn the per-core tasks first (their notify handles will be used by
     * the comparator). Creation can fail under the internal-heap floor; a NULL
     * g_core_h would later be passed to xTaskNotifyGive() → panic, so treat a
     * failed create as fatal and clean-reboot to retry (not a rollback trigger). */
  BaseType_t r0 =
    xTaskCreatePinnedToCore(core_task, "core0", 3072, (void *)(intptr_t)0, SAFETY_TASK_PRIO, &g_core_h[0], 0);
  BaseType_t r1 =
    xTaskCreatePinnedToCore(core_task, "core1", 3072, (void *)(intptr_t)1, SAFETY_TASK_PRIO, &g_core_h[1], 1);

  /* Comparator task — unpinned, the FreeRTOS scheduler can place it on
     * whichever core has slack. Higher stack budget than the cores since
     * it owns the sockets + drain logic. */
  BaseType_t rc = xTaskCreate(comparator_task, "comparator", 5120, NULL, SAFETY_TASK_PRIO, NULL);

  if ((r0 != pdPASS) || (r1 != pdPASS) || (rc != pdPASS) || (g_core_h[0] == NULL) || (g_core_h[1] == NULL)) {
    ESP_LOGE(TAG, "FATAL: safety lockstep task create failed (heap) — clean reboot");
    vTaskDelay(pdMS_TO_TICKS(50));
    esp_restart();
  }

  dcs_support_finalize(&bs);
}

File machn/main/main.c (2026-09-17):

// SPDX-FileCopyrightText: 2026 Polymath Robotics
// SPDX-License-Identifier: Apache-2.0

/**
 * @file main.c — ESP32-S3 pstop MACHINE node ("machn").
 *
 * The machine role of pstop_c on the remote's platform, inverting the
 * remote's lockstep: the remote's two cores independently ENCODE and the
 * comparator transmits only on agreement; here the two cores independently
 * DECODE + DECIDE and the comparator actuates/replies only on agreement.
 *
 *   - Each core runs its OWN pstop_c machine instance (own state, own
 *     remotes table). Every received datagram is processed by BOTH.
 *   - The comparator compares (library verdict, reply bytes). Agreement →
 *     reply sent, relays driven to the agreed state. Disagreement →
 *     internal fault: NO reply (remotes see silence and stop), both relay
 *     outputs commanded open, mismatch counter incremented. Transient by
 *     design — agreement on a later tick resumes normally, like the remote.
 *   - Each core drives ITS OWN relay from ITS OWN instance's verdict; the
 *     two relay contacts are wired in series in the robot's stop circuit,
 *     so either core alone stops the robot. Energized = run; any reset,
 *     brownout, or hang fails to STOP.
 *   - Feedback: a resistor divider on each relay's switched output, read
 *     as a digital input by the comparator every tick. A persistent
 *     commanded-vs-observed contradiction raises a (self-clearing) relay
 *     fault indication; safety never depends on it — the series partner
 *     carries the stop.
 *     NOTE (2026-08): relay-feedback monitoring is DESCOPED by default via
 *     the Kconfig gate CONFIG_MACHN_RELAY_FEEDBACK (default n; see the gate
 *     comment below). A new machine-specific hardware revision + wiring
 *     diagram is coming in which the divider feedback voltages cannot be read
 *     sanely; the read-back path is therefore gated OFF (relays are still
 *     DRIVEN exactly as before). Rationale, reversal steps, and safety-case
 *     impact: docs/RELAY_FEEDBACK_DESCOPE.md. Set the Kconfig to y to restore.
 *
 * pstop_c (certification track) is UNMODIFIED — this file is the shell.
 * Design: docs/MACHINE_ESP32_DESIGN.md. Scaffold status: timing config is
 * compile-time constants. Admission (may a remote BOND at all) is the optional
 * NVS-backed allow/denylist (dcs_list_*, managed at /api/admission; both empty
 * = everyone). Re-arm authority is the REMOTE's own announced role, re-read on
 * every frame. Telemetry reuses the dcs comparator/core atomics (machn-specific
 * /state.json fields are a follow-up).
 */

#include <stdatomic.h>
#include <stdlib.h> /* strtoul for the operator-hostname parse */
#include <string.h>

#include "dcs_support.h"
#include "esp_log.h"
#include "esp_system.h" /* esp_restart on a clock fault */
#include "esp_task_wdt.h" /* TWDT subscribe/feed for the comparator */
#include "esp_timer.h"
#include "microlink.h" /* peer-wanted hook: pin operator remotes past the peer cap */
#include "sdkconfig.h" /* CONFIG_MACHN_RELAY_FEEDBACK — relay-feedback gate */
// clang-format off
#include "freertos/FreeRTOS.h"
#include "freertos/task.h"
#include "freertos/semphr.h"
// clang-format on
#include "driver/gpio.h"
#include "lwip/sockets.h"
#include "pstop/machine.h"
#include "pstop/pstop_msg.h"
#include "pstop/pstop_remote_data.h"
#include "pstop_aux_channel.h"

static const char * TAG = "machn";

/* === Role configuration (compile-time scaffold; NVS/admin UI later) ====== */
#define MACHN_LISTEN_PORT 8890
#define MACHN_MACHINE_ID 0x01020304u /* what remotes put in receiver_id */
#define MACHN_MAX_REMOTES 8
#define MACHN_MAX_LOST_MESSAGES 10u
#define MACHN_MAX_MISSED_HEARTBEATS \
  5u /* was 3; raised to ride through ~90min control-plane re-sync RTT spikes (2026-08-04) */
#define MACHN_MIN_STOP_MS 500u /* -> library delay_between_stop_ms */
#define MACHN_DEFAULT_HEARTBEAT_MS 400u /* advertised: remotes publish at /2 */

/* === Relay I/O (reuses the remote's E-stop loop pins) ===================== */
#define RELAY_A_DRIVE 39 /* core 0 -> relay 1 coil driver */
#define RELAY_A_SENSE 40 /* divider on relay 1's switched output (feedback; gated, see below) */
#define RELAY_B_DRIVE 41 /* core 1 -> relay 2 coil driver */
#define RELAY_B_SENSE 42 /* divider on relay 2's switched output (feedback; gated, see below) */
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

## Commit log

2024-04-19 Merge instructions to main (#1)
    * init stuff
    * gh flavored markdown experiment
    * images showing up?
    * image path fix
    * image size?
    * image size pt 2?
    * image size pt 3?
    * image size pt 4 + bullet points
    * image size pt 4 + bullet points
    * image size pt 4
    * i think i understand gh markdown now
    * heatsink
    * center align?
    * caption
    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
2024-04-19 Instructions (#2)
    * caption 2
    * caption 3
    * caption 4
    * caption 5: the finale?
    * caption 5
    * caption 7
    * step 3
    * step 3.1
    * step 3.2
    * step 4
    * add mermaid
    * stop button + e-ink rotation
    * stop button img sizes
    * step 6
    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
2024-04-19 Instructions #3 (#3)
    * step 6.1
    * power button instructions
    * power wiring size
    * battery indicator and i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
2026-05-05 Initial prototype client/server app (#9)
    - This demonstrates very simple pstop behavior
    - Fixing bug in getting current time
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2026-05-21 Adding more unit tests (#24)
    - Fixing issue where 2 clients bond/ok, one client stops/ok to take control
    and then client that has control unbonds. Robot needs to stop.
    [main.c]
2026-05-22 Improving logging (#27)
    - Log function now takes timestamp, device_id, message, error code
    - This is called when message changes or when timeout happens
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2026-07-23 Revert "Restructure into firmware monorepo; archive ROS2; add CI + OSS scaffolding (#53)"
    This reverts commit 65273eddd2c416851a3544a9169486d478f86096.
    [FF0126BBCAEA01.stp, JACK-USBC-6SMT-2SL.stp, LED.step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]
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2026-08-04 net(microlink): multi-region DERP relay — fix outbound cold-bond errno-128 (#67)
    ## What & why
    Fixes the recurring **outbound cold-bond `errno-128`** — a chip could
    not originate a WireGuard session to a safety peer on a **different DERP
    region**. Root cause (finally isolated, see
    `docs/OUTBOUND_COLD_BOND.md`): the chip kept **one** DERP relay
    connection on one region, and `ml_derp_queue_send` had no per-peer
    region routing, so it could not relay a handshake to an off-region peer
    → outbound `errno-128`, inbound fine. Every bench unit homes on region
    2, which is why this hid for weeks. This is precondition **A** of the
    four-link chain that the last five "fixes" each half-closed.
    ## Th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
2026-08-05 ros2: restore David's machine-node conventions (fix #68 regression) + carry features forward (#70)
    ## Fixes the ros2 convention regression from #68
    **@david1244** — you were right: #68 (`1f226be`) wholesale-imported
    pstop's *older* ros2 structure into the machine package and reverted
    your conventions cleanup. My mistake — I brought pstop's `ros2/` in
    verbatim instead of reconciling it onto your `987d90c` state. This
    restores your conventions on current main, and carries the genuinely-new
    work forward **in your style** (not the reverted structure).
    ### Restored to your conventions (was reverted by #68)
    - **CMake:** back to `ament_cmake_auto` +
    `ament_auto_find_build_dependencies()`,
    `ge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
    [machine_params.yaml, protective_stop_machine_params.yaml]
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2026-08-05 net+crypto: DERP-stability, crypto -O3, region-9 aux fix, KATs + peer diagnostic (#74)
    Consolidated, bench-verified work off `dev` (per the dev→main flow).
    Five logical changes; all firmware/machn build clean on ESP-IDF 5.5 and
    the host crypto KATs pass (21/0).
    ## 1. DERP-stability — stop nuisance safety-heartbeat rebonds
    (`08103bd`)
    Two-queue TX priority (separate FIFO for safety+handshake frames,
    drained before disco/aux so aux work can't starve the heartbeat),
    hard-NAT flap backoff, disco probe dedup. On top of the multi-region
    relay already on main (#67).
    ## 2. crypto -O3 on the vetted primitives (`d78d842`)
    `-O3` (vs project `-Og`) on the already-shipped, hand-vetted primitives
    (X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
2026-08-07 post-deploy hardening: max_missed=5, OTA wrong-lineage reject + connectivity/USB-NCM/scale validation (#80)
    Post-deploy hardening + validation off `dev`, bench-verified on
    `7867d4b`. Two small firmware/config changes; the rest are validation
    records of already-merged mechanisms.
    ## Code / config
    1. **max_missed = 5 everywhere** (`1fdf05d`) — ROS 2 node default
    reconciled to machn/host (2.0s timeout); configs+docs aligned.
    2. **OTA wrong-lineage reject at first-chunk** (`abb7808`) — HTTP-upload
    OTA now enforces the `project_name` check (machine refuses a remote
    image, HTTP 400, no reboot); remote gains symmetric
    `CONFIG_ML_OTA_REQUIRE_PROJECT`.
    ## Validation (docs, `OPEN_ITEMS.md`)
    - Ou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
    [protective_stop_machine_params.yaml]
2026-08-10 post-audit hardening: wifi_tx_power persistence, wifi s_idx race, MISRA/microlink sweep + doc reconciliation + USB-NCM setup guide (#81)
    Post-audit hardening + doc hygiene off `dev`.
    ## Firmware
    - **wifi_tx_power persistence** — the one runtime setter that didn't
    survive power loss (NVS `wifi_txp`, re-applied at
    `WIFI_EVENT_STA_START`).
    - **dcs_wifi `s_idx` atomic** — closes the last residual of the MISRA
    "wifi_status unlocked read".
    - **Event-driven demote on link-down** — link-down events wake the route
    supervisor for instant failover; purely additive (periodic poll
    preserved as fallback), non-safety supervisor.
    ## Tests
    - **EMC-blip / auto-arm regression guard** — host test prov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
    [dcs_internal.h, dcs_nvs.c]
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2026-08-10 net(derp): stuck-on-relay + cold-bond recovery (1/4) (#87)
    ## net(derp): stuck-on-relay + cold-bond recovery (1/4)
    **Stack (base → top):** `main` → **pr/1** → pr/2 → pr/3 → pr/4.
    Review/merge bottom-up.
    First layer of the split of the tested/deployed `net/derp-autoneg`
    branch. All connectivity-robustness fixes that stand on their own on top
    of `main`.
    ### Contents
    - **DERP stuck-on-relay fix (v1→v2→v3 lineage).** `probe stale best
    endpoint + relay-bound retry` → `fast CMM + pong-race fix` → `bound
    probe-slot lifetime + break CMM chains (regains-oscillation fix)` → `CMM
    throttle cleanups from v3 adversarial review`. A chip that fell back to
    a DERP relay would stay relay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
    [dcs_internal.h, dcs_support.c, main.c]
2026-08-10 net(derp): region visibility + lock (2/4) (#88)
    ## net(derp): DERP region visibility + lock (2/4)
    **Stack:** main → pr/1 → **pr/2** → pr/3 → pr/4. **Base =
    `pr/1-derp-connectivity`.** Review/merge after pr/1.
    Second layer. Operator-facing control over the DERP home region,
    building on the connectivity fixes in pr/1.
    - **DERP-region visibility + lock UI** (remote and machine).
    `get_derp_region()` now returns the effective home (lock wins, else
    learned); new `get_derp_region_locked()` exposes the configured override
    so both device pages show AUTO vs LOCKED at a glance. `/state.json`
    gains `derp_region_locked`; the admin page gets a Lock / Clear-Auto
    control reusing `POS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
2026-08-10 obs(derp): DISCO/heap/arm-state telemetry + sdkconfig-parity CI (3/4) (#89)
    ## obs(derp): DISCO / heap / arm-state telemetry + safety cleanups (3/4)
    **Stack:** main → pr/1 → pr/2 → **pr/3** → pr/4. **Base =
    `pr/2-derp-region-control`.** Review/merge after pr/2.
    Third layer. Observability for the dynamics the pr/1 fixes rely on, plus
    two small safety/telemetry cleanups.
    - **Instantaneous internal-heap fields** (`heap_free_int` /
    `heap_lfb_int`) for leak-vs-fragmentation-vs-transient diagnosis
    alongside the lifetime watermark.
    - **DISCO observability** in `/admin/api/monitor`: `probe_tbl_hw`
    (pending-probe table high-water; 64 = saturated), `cmm_rx_count`
    (CallMeMaybe r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
    [dcs_internal.h, dcs_support.c, main.c]
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2026-08-11 fix(ring): dim idle white ring to 50% brightness (#93)
    Dims the **idle (IDLE = white)** safety-ring state to 50% brightness.
    White lights all three WS2812 channels, so at `RING_BRIGHTNESS` (40/ch)
    it reads ~3× brighter than the single-channel state colours
    (green/red/blue/amber) and is glaring when a remote is idle.
    - Adds `RING_WHITE_BRIGHTNESS = RING_BRIGHTNESS / 2` and uses it for the
    IDLE white fill only.
    - Amber (UNREACHABLE), green (OK), red (STOP), blue (BOND), and the
    locate-mode white are unchanged.
    Note: an earlier report of "idle shows amber not white" was
    double-checked and is **not** a logic bug — a device only shows amber
    when a machine slot is actually configured-but-unre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
    [dcs_pstop_ring.c]
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2026-08-13 fix(net): survive edge connection-table flushes — DERP/disco resilience (#94)
    ## DERP/disco resilience — survive office-edge connection-table flushes
    **Status: one fix still pending, but ready for merge anyway.** Base
    `main`, HEAD `674f457`.
    ### The bug
    The bench protective-stop dropped green every few hours. Root cause
    (nailed via a live wire+journal capture from the DUT-host, over a
    session-to-session bridge): the **office edge firewall periodically
    flushes its connection table** — RSTing DERP TCP across regions *and*
    rebinding NAT in the same instant. One flush kills the machine↔remote
    *direct* path (a NAT hairpin off the edge's public IP, not LAN) **and**
    the DERP relay at once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
    [dcs_internal.h, dcs_nvs.c, dcs_pstop_ring.c]
2026-08-14 Stage-1 gapless region switch (pin→MBB) + reliability fixes [living dev PR] (#95)
    Consolidated dev-branch effort (single living PR). **Prepared for merge
    2026-08-14** — all 20 review findings across 7 automated rounds fixed
    in-line and replied; CI green; fleet field-validated.
    ## Headline result
    **run-31 (overnight, real office edge, zero-exclusion): 400+
    home-DERP-conn RSTs absorbed with ZERO protective-stop disarms and worst
    heartbeat gap <1s** — the identical storm class produced 13 disarms in
    3h two nights earlier. Full progression: run-26 (1 disarm/5 switches,
    legacy) → run-27 gate (17/17 switches green) → run-29 (13 disarms/3h,
    classes taxonomized) → run-31 (0 disarms unde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
    [dcs_internal.h, dcs_nvs.c, dcs_pstop_ring.c]
2026-08-16 Registration-loss auto-heal + path-gated pong demote + rx-staleness reap (#96)
    Bypass rule by ilia in admin account, weekend merge
    Fixes the two defects behind the 2026-08-14 nuisance-disarm incident,
    root-caused by experiment (hq0 wire captures + adversarial source
    review; bench tasks #40/#41):
    ### 1. Quiet DERP registration loss → periodic idempotent re-register
    (PRIMARY)
    The control plane silently forgot machn's registration; derp-9 then
    **denied** relaying to its key (30 denials logged during the reboot
    window, zero after) — a 100% inbound relay black-hole invisible to every
    local gauge. Cure was a reboot; now the coord loop re-registers every 5
    min through the normal reconnect flo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
2026-08-20 Fix §7a skip-defeat: tolerate learned endpoints in the re-add compare (#97)
    ## Scope (grown through live bench forensics — every fix validated on a
    reproducer)
    Nine functional commits, all quiescence/diagnostics/self-heal — no
    safety-path behavior change:
    | Commit | What |
    |---|---|
    | `829f881` | **§7a skip-defeat fix**: order-insensitive subset endpoint
    compare (learn-from-ping appends defeated exact equality forever for
    pinned peers → X25519 re-add storms under churn; run-36's 6-disarm
    cascade) |
    | `0f03afe` | `peer_has_endpoint()` shared membership helper (3 drifted
    copies — review finding) |
    | `d1ecd6e` | `readd_skipfail[7]` per-clause skip-defeat attribution
    counters |
    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
    [dcs_internal.h, dcs_nvs.c, dcs_support.c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]
2026-08-20 Bench observability + release tooling (runs 35-51 retrospective) (#98)
    ## Bench observability + release tooling
    Retrospective deliverables from the runs 35-51 stability campaign — each
    item exists because its absence measurably cost debugging time.
    Non-firmware (tools/ + docs/ only); no device behavior changes. Targets
    `dev` so it folds into the normal main flow after review; branch deleted
    after merge per branch policy.
    ### `tools/udp_canary.py` — independent wire truth
    **Rationale:** firmware self-reported network metrics are not wire
    evidence. A week of firmware-side gauges could not distinguish "our
    stack is flaky" from "the network edge is flapping"; an ad-hoc STUN
    canary then ide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
2026-08-27 docs: add OSHWA certification and clarify heartbeat cadence (#108)
    - record OSHWA open source hardware certification for Protective Stop
    v1.2 (`US002846`)
    - add the official UID-bearing OSHW wide mark and link it to the
    certification registry
    - add a generated license-facts graphic for CERN-OHL-P-2.0, Apache-2.0,
    and CC-BY-4.0
    - rewrite the main README to be shorter, clearer, and more natural while
    preserving the safety boundary
    - replace stale fixed-10 Hz network claims with machine-controlled
    heartbeat language
    - update the hardware manifest, contribution licensing, and
    certification-mark guidance
    The fixed internal sensing/comparator cycle and historical 10 Hz test
    results re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
2026-09-03 feat: remote-announced operator/stop-only role over the pstop aux channel (#107)
    Let a remote announce its own role (`operator` or `stop_only`) in the
    CRC-protected `padding1` field added to the pstop v2 message. A machine
    grants re-arm authority only when the remote announces `OPERATOR`
    **and** its existing machine-side policy permits that ID.
    `pstop_c` remains unmodified. Wrapper code owns the schema and policy.
    ## Design
    - `common/pstop_aux_channel.h` defines the versioned role values and
    fail-safe codec.
    - Unknown pstop versions or aux versions decode as unspecified; unknown
    role bytes decode as stop-only.
    - The remote stores its role in NVS and defaults to stop-only.
    - `POST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
    [dcs_internal.h, dcs_nvs.c, dcs_support.c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]
2026-09-11 docs: quickstart guide for a fresh laptop + remote over Tailscale (#114)
    `docs/QUICKSTART.md`: a copy-paste walkthrough from an empty Ubuntu
    24.04 laptop to a bench test through STOP and ARM, over the user's own
    tailnet.
    Sections: Tailscale account/key -> laptop joins -> USB tether
    (`host/setup/install.sh`) -> build + flash -> first boot -> ROS 2 Jazzy
    machine node -> pair -> test-station table -> troubleshooting table.
    Appendices: plain-C runner, PoE/LAN/WiFi, what persists across reflash
    vs erase-flash.
    ## Traps found while tracing the code, fixed here
    | Where | What |
    | `components/microlink/Kconfig` | Auth-key help said "reusable +
    ephemeral". Firmware re-sends t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
2026-09-11 feat(health): lifetime wear counters + health-warning board (/api/health) (#115)
    Stacked on #114 (base = `docs/quickstart`); retarget to `main` once that
    merges.
    ## Why
    Know when a remote should be retired for wear. The stop switch on the
    BOM (NKK FF0126BBCAEA01) is rated **100,000 operations** (mechanical and
    electrical life, [FF01
    datasheet](https://www.nkkswitches.com/pdf/FF01%20E-Stop%20Switches.pdf)).
    Nothing on the chip counted presses, and nothing persisted across power
    cycles.
    **Counters** (NVS blob `dcs_app/health`, survive reboot / `idf.py flash`
    / OTA; lost on `erase-flash` or the boot-time NVS auto-erase):
    | Field | Source |
    | `presses` | rising edge of **b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
    [dcs_internal.h, dcs_nvs.c]
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2026-09-17 fix(microlink): boot preseed must honour the peer allowlist for table slots (#132)
    One function, +44/−1 across two commits: the boot NVS peer preseed now
    applies the same **two gates** to **table occupancy** that `add_peer()`
    applies to a netmap-delivered peer — the allowlist, and (round-2
    follow-up, per @iliabaranov's comment and the Claude finding) the
    runtime `max_peers` cap. Rebased on merged #130.
    ## Bug
    `ml_peer_nvs_load_all()` marks every cached peer `active`. The preseed
    loop skipped the WireGuard *install* for non-allowed entries but left
    them in `ml->peers[]`. On a device with the allowlist filter enabled,
    stranger entries cached from before the filter was turned on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
2026-09-17 feat: add safety traceability linter (#119)
    ## What this delivers
    A stdlib-only linter that parses the canonical safety markdown, checks
    bidirectional SR/function/evidence consistency, computes citation
    coverage, ratchets existing findings through an exact baseline, and runs
    on every PR and push to `main`.
    ## Classification
    Class B: assurance tooling and CI only. No runtime safety path,
    interface, timing, state machine, protocol, requirement text, or
    verification status changes.
    ## Coverage result
    - 40 requirements: SYS 9, R 15, H 6, M 6, I 4
    - 32/40 have at least one resolved cited verifying artifact
    - 17/40 are marked strictly Verified
    - 22/27 functions are traced, or 22/25 excluding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
2026-09-18 fix(ota): yield between writes for idle watchdog progress (#123)
    ## Stack (merge top to bottom; each PR shows only its own commits)
    1. #123 fix(ota): yield between writes `5+/0−` **→ this PR**
    2. #122 fix(diag): complete logs, valid reply ages `23+/6−`
    3. #134 fix(wg): relay re-fetch backoff + DERP ladder `94+/13−`
    4. #145 fix(safety): crash-counter age-out 120 s → 10 min `32+/12−`
    5. #135 fix(usb): bounded TX FIFO `302+/4−`
    Stack tip `v1.2-40-g04bea4b` (all review fixes) is on DUT `01d7f344` +
    bbd8 `0154bbd8`: bonded to a ROS 2 machine, DUT gesture arms; tether
    disable→re-enable cycle exercised on the DUT (counters reconcile, no
    crash). After merging one PR, retarget the n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
2026-09-18 fix(diag): preserve complete logs and valid reply ages (#122)
    1. #123 fix(ota): yield between writes `5+/0−`
    2. #122 fix(diag): complete logs, valid reply ages `23+/6−` **→ this
    PR**
    crash). After merging one PR, retarget the next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
2026-09-18 fix(wg): escalate relay-stuck coord re-fetch backoff; DERP retry ladder for any safety peer (#134)
    3. #134 fix(wg): relay re-fetch backoff + DERP ladder `94+/13−` **→ this
    crash). Af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
2026-09-18 fix(safety): crash-counter age-out 120 s -> 10 min (#145)
    4. #145 fix(safety): crash-counter age-out 120 s → 10 min `32+/12−` **→
    this PR**
    crash). After merging one PR, retarget the next to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
    [dcs_internal.h]
2026-09-18 fix(usb): bounded in-order TX FIFO so an NCM-busy endpoint retries instead of dropping (#135)
    5. #135 fix(usb): bounded TX FIFO `302+/4−` **→ this PR**
    crash). After m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
2026-09-20 fix: remote connectivity — USB tether TX, bus-state failover, WireGuard re-establishment, coord deadline (#156)
    Consolidates #149, #152, #151, #155 and #153 (closed as superseded;
    their review threads and bot findings were addressed there and the fixes
    are included here). 12 linear commits, 409+/29−. Every commit was in the
    build that passed the 3.7 h soak below.
    ## What is fixed
    | area | commit(s) | defect |
    |---|---|---|
    | USB tether TX | `de335e8` `1b5fe82` | `tinyusb_net_send_sync(…, 0)`
    reclaimed the packet before the equal-priority TinyUSB task ran the
    deferred send — ~95 % of device→host frames silently dropped (regression
    from #135). Now a 20 ms wait; TIMEOUT-after-send du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
2026-09-20 chore(release): guard against credentials in published firmware (#148)
    Every value in the git-ignored `sdkconfig.credentials` is compiled into
    both the `.bin` and the `.elf` as a plain string. Nothing in the repo
    prevented such a build from being attached to a GitHub release.
    - `tools/release_guard.sh <artifact>…` — exit 1 if any artifact (a)
    carries the private-build brand, (b) contains a value of a local
    credentials file (public Kconfig defaults skipped; Kconfig escapes
    undone; short values matched as whole C strings), or (c) contains a
    secret-shaped string (`tskey-…`, PEM key with body, literal
    `Bearer`/`Basic` tokens). Never prints the value, only which key leaked.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
2026-09-21 fix(eth): W5500 RX via SDK polling mode; INT-line stall gauge (#128) (#162)
    Closes the ~1 s Ethernet receive-stall class discussed in #128.
    ## Problem
    The ESP-IDF W5500 driver configures the chip's INT pin as a
    **falling-edge** interrupt although INT is a **level** signal. If a
    frame completes in the sub-µs window between the driver clearing `Sn_IR`
    and INT re-asserting, no new edge is produced and the frame waits for
    the driver task's 1000 ms `ulTaskNotifyTake` re-check (the vendor's own
    workaround, espressif/esp-idf#6233; polling mode was added later in
    esp-idf#12692). On a 5 Hz heartbeat with a 1.6 s stop-on-silence budget
    that eats up to 1 s of margin, receive-side only.
    ## Change (93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
    [dcs_eth.c, dcs_internal.h, dcs_support.c]
2026-09-21 fix(tether): no retransmit of ambiguous USB hand-offs; monotonic WireGuard handshake timestamps (#157) (#160)
    Fixes #157 (two 9-minute tether outages, 2026-09-19 19:18 and 2026-09-20
    09:06). Two independent, minimal commits.
    ## Root cause (from tether-side captures)
    A routine host-initiated WireGuard rekey; the device's handshake
    **response left the device three times** (identical bytes, within 1 ms).
    The host's parallel handshake workers each consumed a copy and derived
    **three sessions** from one handshake (three keepalives, each with
    counter 0), keeping the last and discarding the first — the one whose
    receiver index the device uses. From then on the host transmitted but no
    longer acce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
2026-09-28 fix(microlink): refuse the public default admin password over Tailscale (#179)
    Stacked on #178 (2 of 6).
    Public release images use the admin password `microlink`. On a shared
    tailnet, any peer that can reach a remote, including a clone of a stolen
    unit, could use it to read coredumps, change settings or promote the
    remote to `operator`.
    An image built with the public default (or an empty) password refuses
    admin requests that arrive on its Tailscale interface (the socket's
    local address is the WireGuard netif's address). USB tether, Ethernet
    and SoftAP are unaffected, so the quickstart only changes its admin
    calls to use `$DEV`. Images built with their own password are
    unaffe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
2026-09-28 fix(admin): enter_download hands USB to USB-Serial-JTAG; the host resets (#180)
    Stacked on #179 (3 of 6).
    `/api/enter_download` forced the ROM into download mode with a system
    reset. Two problems once a unit runs Secure Download Mode (#181):
    - With the USB tether up, TinyUSB owns the internal PHY and the mux
    survives the reset, so the ROM came up on its USB-OTG loader
    (`303a:0009`), which Secure Download Mode disables.
    - A system reset re-arms the RTC watchdog's flash-boot protection (~9 s
    measured). esptool disables it when it connects over USB-Serial-JTAG,
    but not in Secure Download Mode, so a full app write (~25 s) was cut
    off.
    The handler soft-disconnects the tether, han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
2026-09-28 feat(tools): pstop_secure.py, provisioning for the secure profiles (#182)
    Stacked on #181 (5 of 6).
    `tools/pstop_secure.py` signs a secure-profile build with the owner's
    key, encrypts it for one unit (`secure-fe`), provisions a blank unit and
    re-flashes provisioned ones over USB: `sign-bootloader`, `provision`,
    `flash`, `sign-ota`. Key generation and reading a unit's security state
    are one-line `openssl`/`esptool` commands in the doc.
    - Provisioning follows Espressif's ["enable
    externally"](https://docs.espressif.com/projects/esp-idf/en/stable/esp32s3/security/security-features-enablement-workflows.html)
    order and burns the same eFuses the ESP-IDF 5.5.4 bootloader would,
    ending wit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

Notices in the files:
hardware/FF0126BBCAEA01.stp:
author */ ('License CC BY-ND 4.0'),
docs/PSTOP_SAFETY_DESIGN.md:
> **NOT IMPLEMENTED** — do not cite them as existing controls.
